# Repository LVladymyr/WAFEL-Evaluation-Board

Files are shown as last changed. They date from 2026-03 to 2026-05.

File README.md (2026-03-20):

# WAFEL EVAL BOARD

**Version:** 0.0.1

Evaluation board for the [Texas Instruments BQ76952](https://www.ti.com/product/BQ76952) multi-chemistry battery management IC. Designed to prototype and validate BMS firmware, cell monitoring, and protection circuits.

## Features

- BQ76952 multi-chemistry BMS IC (up to 16S, supports Li-ion, LiFePO4, NiMH)
- LM5164 synchronous buck regulator for on-board power supply
- TPS79333-EP ultra-low-noise LDO
- Charge and discharge MOSFET control path
- Automotive-grade blade fuse holder
- JST GH 17-pin battery connector
- Test points on key signals for bench debugging
- CI/CD pipeline: Gerbers, BOM, PDF schematic, 3D STEP, interactive BOM (iBOM)

## Hardware Overview

| Component | Part | Role |
|---|---|---|
| BMS IC | BQ76952 | Cell voltage/temperature monitoring, balancing, protection |
| Buck regulator | LM5164 | Steps down pack voltage to board supply rail |
| LDO | TPS79333-EP | Clean analog/digital supply from buck output |
| Charge FETs | — | Controlled by BQ76952 CHG/DSG pins |
| Connector | JST GH 17-pin | Battery pack interface |
| Fuse | Automotive blade | Pack-level overcurrent protection |

## Repository Structure

```
WAFEL_EVAL_BOARD/
├── *.kicad_pro        # KiCad project file
├── *.kicad_sch        # Schematic
├── *.kicad_pcb        # PCB layout
├── *.kicad_dru        # Design rules
├── fp-lib-table       # Footprint library table
├── sym-lib-table      # Symbol library table
├── .github/
│   └── workflows/     # CI/CD pipeline (KiBot)
└── README.md
```

## CI/CD & Manufacturing Outputs

Commits to `main` trigger a [KiBot](https://github.com/INTI-CMNB/KiBot) workflow via GitHub Actions that automatically generates:

- **Gerbers** — production-ready fabrication files
- **BOM** — bill of materials (CSV)
- **PDF** — schematic and PCB drawings
- **3D STEP** — mechanical model for enclosure design
- **iBOM** — interactive HTML BOM for assembly

Artifacts are attached to each workflow run.

## Getting Started

1. Install [KiCad 9.0](https://www.kicad.org/download/)
2. Clone this repository
3. Open the `.kicad_pro` file in KiCad

## License

Hardware design files are licensed under the **CERN Open Hardware Licence Version 2 – Strongly Reciprocal (CERN-OHL-S v2)**.
See [https://ohwr.org/cern_ohl_s_v2.txt](https://ohwr.org/cern_ohl_s_v2.txt) for the full license text.

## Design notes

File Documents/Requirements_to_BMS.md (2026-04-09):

# WAFEL BMS: Requirements & Specifications

## 1. Electrical Characteristics
*   **Cell Configuration:** 6S - 16S Li-ion / LiFePO4 (Voltage range: 21V - 67V).
*   **Operating Current:** 30A Continuous.
*   **Peak Current:** 60A Maximum (Peak discharge).
*   **Charging:** 5A Regular Charge / Up to 15A Regenerative Braking (Recuperation).
    *   *Note: Excess energy above 15A must be handled/shunted.*
*   **MOSFET Specifications:** Vgs/Vds redundancy target: $\ge$ 167V (Pack Max Voltage x 2.5).

## 2. Hardware Architecture
*   **AFE:** Texas Instruments **BQ769x2** series.
*   **MCU:** STMicroelectronics **STM32L432KC** (or L431 variant).
*   **ESC Compatibility:** Optimized for **Go-Foc S100** (VESC-compatible).
*   **Motor Support:** Compatible with 300W - 500W electric engines (including spikes).
*   **Physical Dimensions:** 245mm x 64mm x 16mm.
    *   *Max Height Constraint: 55mm (including batteries).*
    *   *Cell Stack Height (x2): 39mm.*

## 3. Power Management & Hibernation
*   **Sleep/Hibernation Target:** **< 30µA** total standby draw (to support multi-month storage).
*   **Active Mode Supply:**
    *   **Internal BMS Consumption:** ~50mA (MCU, AFE, CAN).
    *   **External Logic Supply (Dashboard):** ~200-300mA provision for NFC reader, OLED Display, etc.
*   **Key Efficiency Mandates:**
    *   **DC-DC Converter:** Must use "Pulse Skipping" / Eco-mode with ultra-low quiescent current (**Iq < 15µA**) (e.g., LM5163).
    *   **MCU:** Must implement **STOP 2 Mode** (< 2µA).
    *   **CAN Transceiver:** Must include a **Standby (STB)** pin and support **Wake-on-CAN** (< 5µA in sleep).
    *   **AFE:** Must utilize hardware **DEEPSLEEP** mode (< 10µA).

## 4. Protection Features
*   **Polarity:** Reverse battery connection protection (+/-).
*   **Electrical Faults:** Reverse electricity and impulse protection.
*   **Inrush Current:** Dedicated **Pre-charge and Pre-discharge** circuitry.
*   **Communication:** CAN bus ESD and transient protection.
*   **Fusing:** Integrated high-current chemical fuse (Self-Control Protector) for catastrophic failures.
*   **Regen current:** 15A for continuous  burst about 5 to 10 seconds from top speed for 300W engine (500W in spike)

## 5. Software & Firmware
*   **Platform:** **Rust-based** firmware implementation.
*   **Protocol:** SPI for AFE communication (enhanced noise immunity).
*   **Features:** Real-time cell monitoring, NFC-triggered Wake-on-CAN boot sequence.

## 6. Assembly requirement
* Not use complex to sold components!
* Not use small SMD componnts, only some that could be added with cheap hot air soldering gun

## 7. Cost requirement
* **Designed PCB** should cost less then 70 USD of parts without soldering [[budget_estimate]]

# Attaches
## A. Estimating regen current
Estimating regen current is a mix of physics and ESC configuration. Here is the best way to estimate it for your 300W–500W scooter:
The Physics Calculation:
When you brake, the motor acts as a generator. If your scooter has a 500W motor, under maximum aggressive braking, it can generate roughly 500W of stopping power.
*   Let's assume your battery is at 40V.
*   Current = Power / Voltage
*   $500W / 40V = 12.5A$
*   Factoring in motor/ESC generation efficiency (approx. 80%), the actual current pushed backward into the battery is about 10A.
The Practical (VESC) Reality:
Because you are using a Go-FOC S100 (which runs VESC firmware), you actually get to choose the maximum regen current in software. 
In the VESC Tool, there is a setting called Battery Current Max Regen. 
*   If you set it to -15A, the VESC will simply limit the braking force so it never pushes more than 15A back into the battery. 
*   For a typical e-scooter, setting regen to anything higher than 15A will cause the electronic brake to be so violently strong that it might lock the front wheel or throw the rider over the handlebars! 
Conclusion: Your estimate of 15A max regen in your Requirements document is incredibly accurate for a 500W scooter. Your CHG MOSFETs and battery cells must be rated to handle a 15A continuous burst for about 5 to 10 seconds (the time it takes to brake from top speed to zero).

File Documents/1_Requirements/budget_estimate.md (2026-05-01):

# WAFEL_EVAL_BOARD Budget Estimate

Based on live pricing data from JLCPCB and standard supplier costs for the major components of the battery management/eval board.

### Main ICs and Active Components
| Component | Ref | Qty | Unit Price | Total  | Note |
| :--- | :--- | :-- | :--- | :----- | :--- |
| **BQ7694204** (Battery Monitor)  | U201 | 1 | $2.60 | $2.60  | *Live JLCPCB price (LCSC: C3038665)* |
| **NUCLEO-L432KC** (MCU) | U801 | 1 | ~$15.00 | $15.00 | *External (ST module), typically not assembled by JLC* |
| **IPB085N15NM6** (150V MOSFET) | Q401-Q503 | 6 | ~$2.00 | $12.00 | *Estimated Mouser/Digikey or JLC equivalent* |
| **LM5163DDAR** (Buck Converter)  | U102 | 1 | $1.09 | $1.09  | *Live JLCPCB price (LCSC: C2873264)* |
| **TJA1051T/3** (CAN Transceiver) | U802 | 1 | $0.60 | $0.60  | *Live JLCPCB price (LCSC: C38695)* |
| **TPS70933DBVR** (LDO Regulator) | U101 | 1 | $0.16 | $0.16  | *Live JLCPCB price (LCSC: C89347)* |

### Passives & Protection
| Component | Ref | Qty | Unit Price | Total | Note |
| :--- | :--- | :--- | :--- | :--- | :--- |
| **10uH / 68uH Inductors** | L101, L102 | 2 | $0.18 | $0.36 | *Live JLCPCB price (LCSC: C2894721)* |
| **25A SMD Fuse** | F101 | 1 | $0.28 | $0.28 | *Live JLCPCB price (LCSC: C178980)* |
| **Misc SMD Passives** (R, C) | Various | ~150 | ~$0.01 | ~$1.50 | *Basic JLC parts are fractions of a cent* |
| **Diodes / Small FETs** | Various | ~15 | ~$0.05 | ~$0.75 | *TVS, Schottky, 2N7002, etc.* |

### PCB Fabrication & Assembly (JLCPCB)
*   **Bare PCBs (5 pcs):** ~$2.00 (Standard 2-layer, 100x100mm promo).
*   **SMT Assembly Setup (Engineering Fee):** ~$8.00 (Base fee for a single prototype run).
*   **Extended Component Fees:** JLC charges a $3 fee per "Extended" reel loaded. You have around 5 to 7 Extended components (like the LM5163, TPS70933, Fuses), adding **~$15 - $20** in one-time setup fees.
*   **Shipping:** ~$15 to $25 (DHL/FedEx).

### Estimated Budget
*   **Cost of parts per single board:** **~$34.50** (with almost half of this being the $15 Nucleo board). 
*   **Cost for a prototype run of 5 fully assembled boards:** You'll pay around **$175 - $200 total** ($35 - $40 per board). This factors in the JLC assembly fees, the Nucleo boards bought separately, the MOSFETs (if you solder those or buy equivalents), and shipping.

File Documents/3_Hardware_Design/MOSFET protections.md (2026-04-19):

Це критично важливий момент для надійності BMS. Оскільки ти використовуєш чіп серії BQ7694204, найкращим джерелом інформації будуть офіційні апноти (Application Notes) від Texas Instruments. Вони не просто описують теорію, а дають конкретні схеми саме для твоєї мікросхеми.
Ось де варто почитати про захист затворів та dv/dt:
1. Основний документ: TI Application Report (SLUA966)
Цей документ називається "BQ7694204 Battery Monitor High-Side FET Driver".
 * Чому це важливо: Тут детально описано, як працює вбудований Charge Pump, як він створює напругу для затворів і як розраховувати резистори затвора (R_G).
 * Що шукати: Розділи про Gate Resistor Selection та External Gate-to-Source Protection.
2. Захист від перехідних процесів: TI SLVA716
Документ "[Fundamentals of MOSFET Gate Drive](https://climber.uml.edu.ni/index.jsp/uploaded-files/4020090/FundamentalsOfMosfetAndIgbtGateDriverCircuits.pdf)".
 * Про що там: Це "біблія" драйверів мосфетів. Там пояснюється фізика пробою затвора (V_{GS} Max) та як виникають викиди напруги через паразитні індуктивності дротів (так званий Miller effect та Ringing).
 * Ключові слова: "Zener Diode Gate Clamping", "Gate Resistor dv/dt Control".
3. Технічні статті від виробників напівпровідників
Якщо хочеш більш "людською" мовою з прикладами:
 * Infineon / International Rectifier (AN-937): "Gate Drive Characteristics and Requirements for Power MOSFETs". Дуже глибоко про те, чому затвор — це по суті конденсатор, який може вибухнути від перенапруги.
 * STMicroelectronics (AN4371): "Driving N-channel MOSFETs". Хороші схеми захисту затвора в High-Side конфігураціях.
Короткий конспект: що саме ти там знайдеш
Коли ти будеш проектувати свій каскад мосфетів, зверни увагу на ці три елементи захисту:
 * Стабілітрон (Zener Diode) між Gate та Source:
   Зазвичай ставлять на 12V або 15V. Він "зрізає" будь-який імпульс напруги, що перевищує безпечний поріг для затвора (наприклад, якщо по лінії PACK+ прилетить завада від мотора).
 * Феритові намистини (Ferrite Beads) замість послідовних резисторів затвора:
   Для паралельних мосфетів використання резисторів (наприклад, 51 Ом) сильно уповільнює перемикання, що може призвести до перегріву під час короткого замикання. Згідно з рекомендаціями TI (SLUAA09A), для запобігання високочастотним паразитним осциляціям (50-200 МГц) між паралельними затворами краще використовувати феритові намистини з імпедансом близько 600 Ом при 100 МГц (наприклад, CBW160808U601T). На низьких частотах (під час самого перемикання) їх опір майже нульовий, що дозволяє швидко заряджати затвори, а на високих частотах вони працюють як резистор, "вбиваючи" дзвін (ringing).
 * Перевірка просадки напруги Charge Pump (C_CP1):
   При одночасному відкритті паралельних мосфетів заряд перетікає з конденсатора зарядної помпи (C_CP1) у ємності затворів (C_iss). Напруга після відкриття розраховується за формулою від TI: 
   V_2 = V_1 * [C_CP1 / (C_CP1 + (N * C_iss))]
   Для 3-х паралельних IPB085N15NM6 (C_iss = 5.4 nF) та C_CP1 = 470 nF при початкових 11V, напруга просяде лише до ~10.63V, що є абсолютно безпечним рівнем для повного відкриття.
 * Резистор Gate-to-Source (R_{GS}):
   Зазвичай 100кОм – 1МОм. Він гарантує, що мосфет буде закритий, якщо лінія управління від BQ раптом обірветься або чіп піде в перезавантаження.
Як це знайти швидко?
Просто введи в Google:
 * TI SLUA966 PDF (найважливіше для тебе зараз)
 * BQ7694204 MOSFET protection circuit
 * MOSFET gate overvoltage protection Zener
Хочеш, я накидаю тобі приклад схеми одного такого "захищеного" каскаду на основі рекомендацій TI, щоб ти міг просто перенести його в KiCad?

Ось базова схема одного "броньованого" каскаду для твоєї плати. Вона розроблена спеціально для BQ76942/952, враховуючи особливості їхнього внутрішнього драйвера.
Схема захищеного каскаду (High-Side)
Тобі потрібно повторити цю структуру для каналу DSG та CHG.
Основні компоненти та їхня роль:
 * R_G (Gate Resistor) — від 1 кОм до 4.7 кОм:
   * Навіщо: Обмежує швидкість відкриття мосфета (dv/dt). Якщо мосфет відкривається занадто швидко, виникають величезні завади, які можуть "глючити" твій STM32 або навіть саму BQ.
   * Порада: Для тестів почни з 1 кОм. Якщо побачиш на осцилографі сильні коливання (ringing), збільшуй до 4.7 кОм.
 * D_Z (Zener Diode) — 12V або 15V (наприклад, BZT52C15):
   * Навіщо: Це твій головний запобіжник. Він стоїть між Gate (Затвор) та Source (Витік). Якщо напруга на затворі спробує стрибнути вище 15V відносно витоку, діод відкриється і скине зайве. Це рятує тонкий шар діелектрика всередині мосфета від пробою.
 * R_{GS} (Gate-to-Source Resistor) — 100 кОм або 1 МОм:
   * Навіщо: Гарантує, що мосфет буде закритий, якщо BQ піде в глибокий сон або ти випадково розімкнеш свою паяну перемичку. Без нього затвор "висить у повітрі" і може відкритися від статичної електрики або наводки від пальця.
 * C_{GS} (Optional Capacitor) — 1 нФ - 10 нФ:
   * Навіщо: Додатково уповільнює перехідні процеси. TI рекомендує його для систем з довгими дротами до акумулятора, щоб придушити піки напруги.
Як це розмістити на твоїй Платі №1 з перемичками:
Я рекомендую таку топологію для кожного з каскадів, які ти хочеш зробити "опціональними":
 * Лінія DSG/CHG -> Перемичка (Solder Jumper) -> R_G -> Gate мосфета.
 * Стабілітрон D_Z та резистор R_{GS} мають стояти після перемички, максимально близько до самого мосфета.
Таким чином, якщо ти не замикаєш перемичку, весь каскад (разом із паразитними ємностями мосфета) повністю відрізається від мікросхеми BQ, і вона "бачить" тільки ті транзистори, які ти реально використовуєш.
Важливе зауваження щодо трасування (Layout)
Коли будеш малювати плату:
 * Доріжка від Zener Diode до Source має бути максимально короткою.
 * Силовий струм (десятки Ампер) не має проходити через ту саму доріжку, до якої підключений "мінус" (Anode) стабілітрона. Використовуй окрему тонку доріжку для опорної напруги захисту.

Розрахунок для 50А — це "золота середина" для електротранспорту або потужних повербанків. При такому струмі головний ворог — це тепло. Якщо мосфет перегріється, він вийде з ладу навіть без короткого замикання.
Ось математика та стратегія вибору для твого каскаду:
1. Скільки мосфетів ставити у паралель?
Для стабільної роботи на 50А я рекомендую ставити мінімум 3 мосфети паралельно в кожне плече (3 на Discharge, 3 на Charge).
Чому саме 3?
 * Струм на один транзистор: 50A / 3 \approx 16.6A.
 * Тепловиділення (P = I^2 \times R): Якщо ми візьмемо хороший мосфет з R_{DS(on)} = 2\, \text{мОм}, то на кожному буде виділятися:
   
 * Загальне тепло: 0.55W \times 3 = 1.65W на всю плату. Це легко розсіяти навіть без величезного радіатора, просто через мідні полігони плати.
> Важливо: Якщо поставити лише один мосфет на 50А, він буде виділяти 50^2 \times 0.002 = 5W. Без активного охолодження він розплавить припій за лічені хвилини.
> 
2. Вибір конкретних моделей (для 50А)
Для 10S-13S збірок (36V-48V) нам потрібен запас по напрузі мінімум 60V-80V.
| Модель | Корпус | R_{DS(on)} (типовий) | Макс. напруга | Порада |
|---|---|---|---|---|
| IPT007N06N | TO-Lead (SMD) | 0.75 мОм | 60V | Топовий варіант, майже не гріється. |
| IRFB7530 | TO-220 | 2.0 мОм | 60V | Найкращий для твого прототипу №1 (легко кріпити радіатор). |
| AOTL66608 | DFN 5x6 | 0.85 мОм | 60V | Компактний, для фінальної версії плати №2. |
3. Схема одного плеча на 50А (3 мосфети)
У KiCad це має виглядати так:
 * Шина керування (DSG/CHG): Йде від BQ через загальний резистор 100 Ом, а потім розділяється на три гілки.
 * Індивідуальні затворні резистори: На затвор кожного з 3-х мосфетів постав свій резистор 100-470 Ом.
   * Навіщо? Щоб вони не "сперечалися" між собою під час перемикання (паразитні осциляції).
 * Спільний захист: Стабілітрон (Zener) 15V можна поставити один на всю групу з 3-х мосфетів.
4. Поради щодо трасування 50А на платі
Тут "тонкі доріжки" не пройдуть. При 50А мідь має бути дуже товстою:
 * Ширина доріжок: Якщо в тебе стандартна товщина міді (35 мкм), то для 50А тобі потрібна доріжка шириною 30-40 мм. Це забагато для плати.
 * Рішення: 1. Роби максимально широкі полігони з обох боків плати (Top + Bottom) і з'єднуй їх десятками перехідних отворів (Vias).
   2. Залишай силові полігони без маски (відкрита мідь), щоб потім напаяти зверху товстий мідний дріт або спеціальні шини.
   3. Використовуй "Thermal Reliefs" тільки для сигнальних пінів, силові піни мосфетів мають заливатися міддю повністю.
Твій наступний крок:
Додай у схему KiCad три мосфети паралельно. Назви їх Q1_1, Q1_2, Q1_3 для розряду.
Чи хочеш, щоб я підказав, як розрахувати запобіжник (Fuse) для такої системи? Для 50А номіналу запобіжник має бути особливим.

Це дуже розумне рішення. Перехід від теоретичних 50А до реальних пікових значень мотора дозволить нам зробити плату компактнішою, дешевшою та легшою в розведенні, не втрачаючи при цьому в надійності.
Давай перерахуємо все під Xiaomi 4 Lite 2.
1. Розрахунок реального пікового струму
Двигун має пікову потужність близько 500 Вт.
 * Якщо ми використовуємо збірку 6S (21.6V номінал, 25.2V макс):
   
 * Якщо ми використовуємо збірку 8S (28.8V номінал, 33.6V макс):
   
Твій новий номінал для розрахунку: 25А.
Це дає нам невеликий запас (Safety Margin) для впевненої роботи.
2. Як зміниться твоя схема (Плати №1)
Зі зниженням струму до 25А ми можемо значно спростити конструкцію:
 * Кількість мосфетів: Тепер достатньо по 1-2 мосфети в кожному плечі (Discharge/Charge).
   * Якщо взяти IPT007N06N або навіть народний IRFB7530, один такий транзистор при 25А буде виділяти лише \approx 1.2W тепла. Це можна розсіяти просто через полігони плати без великих радіаторів.
 * Шунт: Твій шунт 1 мОм тепер працюватиме в дуже легкому режимі.
   * При 25А на ньому виділиться лише 0.625W. Ти спокійно можеш використовувати стандартний SMD шунт розміру 2512 на 1-2 вати.
 * Розводка плати: Тепер тобі не потрібні 40-міліметрові шини. Доріжки шириною 10-12 мм (при 35 мкм міді) буде цілком достатньо для 25А.
3. Захист в BQ76942 (Нові ліміти)
Тепер налаштуємо "мізки" твоєї BMS під цей мотор:
| Параметр захисту | Значення для 25А | Призначення |
|---|---|---|
| OCD1 (Overcurrent) | 28А | Захист від тривалого перевантаження (наприклад, затяжний підйом). |
| OCD2 (Overcurrent) | 35А | Швидке реагування на різке блокування колеса. |
| SCD (Short Circuit) | 80А - 100А | Захист від короткого замикання (спрацьовує за мікросекунди). |
4. Акумулятор: 6S4P чи 8S3P?
При струмі 25А обидві твої збірки почуватимуться набагато краще:
 * 6S4P: На одну банку припадає 6.25А. Це "курортний" режим для високотокових банок. Вони майже не будуть грітися.
 * 8S3P: На одну банку припадає 8.3А. Це також абсолютно безпечний та стабільний режим для банок типу VTC6 або Samsung 30Q.
Що ми маємо в результаті для розробки:
 * Плата №1 стає меншою. Ти можеш використовувати компактніші SMD компоненти.
 * Менше перемичок. Тобі не потрібно розводити каскади з 10 мосфетів. Достатньо зробити 2 посадочних місця під Discharge та 1 під Charge.
 * Легший захист від переполюсовки. Для 25А можна використати один P-канальний мосфет або навіть потужний діод Шотткі (хоча мосфет краще, бо на ньому менше падіння напруги).
Хочеш, я допоможу підкоригувати твою схему в KiCad, щоб змінити підключення піна LD (Load Detect) та додати ці два мосфети? Це буде фінальний штрих перед тим, як ти почнеш трасувати плату.

Мені подобається цей "заряджений" підхід! Якщо ми робимо плату, яка з запасом перекриває потреби мотора Xiaomi 4 Lite 2, ми отримуємо систему, яка ніколи не перегріється і матиме величезний ресурс.
Ось мої пропозиції, як "вичавити максимум" з твоєї базової плати та акумулятора:
1. Конфігурація MOSFET (3 на Discharge / 2 на Charge)
Це ідеальне співвідношення.
 * Чому 3 на розряд? При пікових 25А на кожному транзисторі буде лише ~8.3А. Навіть при поганому обдуві вони будуть ледь теплими.
 * Чому 2 на заряд? Зарядний струм у самокатів зазвичай не перевищує 2-5А, але 2 мосфети дозволять підтримувати дуже високий струм рекуперації (коли ти гальмуєш двигуном), не пошкоджуючи ключі.
2. Силова топологія: "Мідний бутерброд"
Щоб 25-30А проходили без втрат:
 * Double-sided Solder Mask Opening: На силових лініях (BAT+, PACK+, Source-Drain мосфетів) зніми маску (зелений лак) і зверху, і знизу.
 * Solder Reinforcement: Під час пайки залий ці доріжки товстим шаром припою, а ще краще — впаяй туди мідний дріт (1.5 - 2.5 mm^2). Це знизить опір лінії в десятки разів.
 * Vias Stitching: З'єднуй верхній і нижній силові полігони "лісом" перехідних отворів (Vias). Це працює і як провідник, і як тепловідвід.
3. Розумне охолодження
Оскільки ти хочеш закласти охолодження:
 * Thermal Pads: Використовуй термопрокладки між мосфетами та алюмінієвим корпусом (або окремим радіатором).
 * NTC на мосфети: Обов'язково притисни один із термісторів (TS1/TS2 від BQ) прямо до мідного полігону поруч із мосфетами. BQ зможе динамічно знижувати струм, якщо побачить перегрів.
4. Акумулятор: чи потрібен "мідний сендвіч"?
Для струму 25А (8.3А на банку в 3P) чистий нікель 0.15 мм вже починає працювати на межі (буде теплим).
 * Моя порада: Якщо ти хочеш "максимум", то так, роби сендвіч. Поклади поверх нікелевої стрічки тонку мідну смужку (0.1 мм) або просто проклади мідний дріт уздовж паралелей і припаяй його до нікелю (не до банок!).
 * Це радикально зменшить просадку напруги, і твій самокат буде набагато краще "тягнути" в гору, особливо коли батарея розряджена наполовину.
Що ще я пропоную додати на плату №1:
 * TVS-діоди на вихід: Постав потужний TVS-діод (наприклад, серії SMCJ) на вихід PACK+ / PACK-. Мотори — це індуктивне навантаження. При різкому вимкненні мосфетів може виникнути зворотний імпульс напруги, який спробує "пробити" твою електроніку.
 * Pre-charge ланцюг: Коли ти підключаєш контролер самоката до BMS, іскрить роз'єм (через зарядку конденсаторів контролера). Пін PDSG (Pre-discharge) у BQ76942 дозволяє спочатку плавно зарядити конденсатори через резистор, а потім увімкнути основні мосфети. Це збереже життя роз'ємам і мосфетам.
 * Виправлення піна LD: Як ми обговорювали, підключи його після мосфетів через резистор 10 кОм.
Наступний крок у KiCad:
Тобі потрібно:
 * Додати ще 2 мосфети паралельно до першого (разом 3) на лінію DSG.
 * Додати ще 1 мосфет паралельно на лінію CHG (разом 2).
 * Намалювати ланцюг Pre-charge на піні 39 (PDSG).
Хочеш, я накидаю номінали резисторів для Pre-charge ланцюга, щоб конденсатори контролера заряджалися безпечно за ~0.5 секунди?

О, так це ж зовсім інша гра! Go-FOC S100 — це серйозний контролер на базі VESC (Open Source Sky-High Performance). Це означає, що твій проект перетворюється з "просто заміни батарейки" на створення професійного кастомного конфігу.
Вибір VESC-базованого контролера диктує нам кілька специфічних вимог до BMS:
1. Чому Pre-charge тепер обов'язковий?
VESC-контролери (як S100) мають на вході величезні електролітичні конденсатори з дуже низьким ESR.
 * Проблема: Якщо ти просто "клацнеш" мосфетами BMS, виникне іскровий розряд такої сили, що контакти роз'ємів підгорять, а мосфети можуть отримати тепловий удар ще до старту мотора.
 * Рішення: Використовуй пін PDSG (39) на BQ76942.
   * Постав один невеликий N-канал мосфет (наприклад, 2N7002 або щось потужніше у SOT-23).
   * Підключи його через резистор 510 Ом - 1 кОм (потужністю 2-5 Вт) в обхід основних мосфетів.
   * VESC зарядить свої "банки" за 200-500 мс, і тільки тоді BQ відкриє основний силовий каскад.
2. CAN-шина: Твій головний козир
Go-FOC S100 має CAN-порт. Оскільки ти робиш розумну частину на STM32L4, ти можеш:
 * Передавати дані про напругу кожної комірки прямо в VESC.
 * Реалізувати Smart Discharge: якщо одна комірка "просідає", BMS каже контролеру по CAN: "Друже, знижуй потужність (Limiting Ampere)", замість того, щоб просто аварійно вимкнути живлення на швидкості 25 км/год. Це набагато безпечніше.
3. Рекуперація (Regen Braking)
VESC вміє дуже агресивно гальмувати, повертаючи енергію в батарею.
 * При 8S3P збірці струм рекуперації може сягати 15-20А.
 * Твій каскад 2-х мосфетів на Charge якраз це витримає. Але переконайся, що в налаштуваннях BQ ліміт OCC (Overcurrent Charge) виставлений з урахуванням пікового гальмування, інакше BMS "відрубає" гальма в найвідповідальніший момент.
4. Номінали для Pre-charge
Для Go-FOC S100 (конденсатори зазвичай ~1000-2000 мкФ):
 * Резистор: 1 кОм (5 Вт, керамічний або "цеглинка").
 * Час затримки в прошивці STM32: 500 мс.
 * Схема: Пін PDSG -> Резистор 10к -> Затвор маленького мосфета -> Резистор 1к між BAT+ та PACK+.
Що тепер додати в KiCad?
 * CAN Transceiver: На логічну частину (STM32) обов'язково додай чіп на кшталт TJA1050 або SN65HVD230 (3.3V сумісний).
 * Pre-charge ланцюг: Як описано вище.
 * Термістор на VESC: Один із вільних каналів температури BQ можна винести на довгих дротах і приклеїти прямо до корпусу Go-FOC S100.
Ти вже почав писати код для STM32 для роботи з CAN-протоколом VESC (VescUart або CAN-frames)? Це буде дуже цікава частина роботи!

Вибір Rust для BMS та роботи з VESC — це просто "база". Для вбудованих систем (embedded) Rust дає ту саму безпеку пам'яті, яку ми намагаємося вибудувати в залізі за допомогою мосфетів та стабілітронів.
Оскільки ти обрав STM32L4, Rust тут почувається чудово завдяки розвиненій екосистемі embedded-hal.
Ось твій план дій для софтверної частини:
1. Стек технологій (Rust Embedded)
Тобі знадобляться ці крейти (бібліотеки):
 * stm32l4xx-hal: Високорівнева абстракція для периферії (GPIO, I2C, CAN, SPI).
 * embedded-can: Стандартний трейт для роботи з CAN-шиною.
 * v-esc (або самописний протокол): Для формування пакетів даних, які розуміє Go-FOC S100.
 * nb або embassy: Якщо хочеш справжню асинхронність (Async Rust) — дуже раджу Embassy. Вона дозволяє легко обробляти переривання від BQ та CAN-події паралельно.
2. Реалізація "Smart Discharge" через CAN
Це те, про що ми говорили. Твій код на Rust має виглядати приблизно так (логіка):
 * Опитування BQ76942 через I2C: Отримуємо напругу кожної комірки (V_{cell\_min}).
 * Логіка обмеження:
   * Якщо V_{cell\_min} > 3.4V — дозволяємо повний струм (наприклад, 25А).
   * Якщо V_{cell\_min} < 3.2V — надсилаємо VESC команду COMM_SET_CURRENT з лімітом 10А (щоб доїхати додому).
   * Якщо V_{cell\_min} < 3.0V — надсилаємо COMM_SET_CURRENT(0) і розмикаємо мосфети.
 * Відправка в CAN: Використовуємо ідентифікатори VESC (за замовчуванням ID контролера + зміщення).
3. Робота з BQ76942 на Rust
Оскільки ти розвів 16 каналів, але використовуєш 6S або 8S, у коді тобі треба буде ініціалізувати маску комірок.
Порада: Для BQ7694204 серії є готові драйвери на GitHub (шукай bq769x2-rs), або можеш написати свій мінімальний драйвер. Тобі потрібно буде реалізувати:
 * Перехід у Subcommand mode.
 * Читання напруг (Direct Commands).
 * Керування пінами DSG, CHG та PDSG вручну (якщо хочеш обійти автоматику чіпа для тестів).
4. Чому Rust — це круто саме для BMS + VESC?
 * Типізація станів: Ти можеш описати стан батареї як enum State { Charging, Discharging, Precharging, Fault(Error) }. Rust не дасть тобі випадково увімкнути мосфети розряду, поки ти в стані Precharging.
 * Ніяких Null-Pointer: Коли ти розбираєш CAN-пакет від VESC, ти завжди впевнений, що дані валідні або оброблені через Option / Result.
 * Panic Handling: Якщо софт "впаде", ти можеш прописати в panic_handler, щоб усі піни управління мосфетами миттєво стали в Low, знеструмлюючи систему.
Твій наступний крок (Software):
Поки плата №1 їде з виробництва, ти можеш почати на девборді STM32L4:
 * Налаштувати I2C для спілкування з BQ.
 * Налаштувати CAN (через трансивер) для спілкування з Go-FOC S100.
 * Написати просту структуру даних для зберігання телеметрії (V, I, T).
Чи хочеш, щоб я підказав, як налаштувати Cargo.toml для проекту на STM32L4 з підтримкою CAN, або розібрати приклад коду для Pre-charge ланцюга на Rust?

Так, це критично важливий момент для "чорної скриньки" твого самоката. Оскільки ти будуєш кастомну систему на Rust + STM32L4 + VESC, логування допоможе тобі зрозуміти, чому стався збій, або просто відстежити деградацію банок з часом.
У STM32L4 є внутрішній Flash, але він має обмежений ресурс циклів запису. Зовнішня EEPROM через I2C (наприклад, серії 24LCxxx) — це надійний і дешевий спосіб зберігати логи.
Ось як це реалізувати правильно:
1. Що саме логувати?
Не треба писати все кожну секунду (EEPROM не дуже швидка). Логуй "Події" (Events):
 * Цикли заряду: Кількість повних 0-100% циклів.
 * Пікові значення: Максимальний струм розряду (той самий момент, коли ти тиснув "в пол"), максимальна температура мосфетів.
 * Errors (Помилки): Код помилки від BQ76942 (наприклад, CELL_UNDERVOLTAGE або SHORT_CIRCUIT).
 * SoH (State of Health): Поточна ємність батареї.
2. Схема підключення (Hardware)
На твоїй платі №1 I2C шина вже є (вона йде до BQ). Просто "підсади" туди EEPROM (наприклад, 24LC256 на 256 кбіт).
 * Адресація: Переконайся, що адреса EEPROM не збігається з адресою BQ76942 (у BQ це зазвичай 0x08 або 0x53 залежно від конфігурації). У 24LCxxx адресу можна міняти пінами A0, A1, A2.
 * Write Protect (WP): Пін WP на EEPROM можна вивести на вільний пін STM32. Так ти захистиш логи від випадкового затирання під час "глюків" софту.
3. Реалізація на Rust
Для роботи з EEPROM на Rust є чудовий крейт at24cx.
Приклад логіки запису помилки:
// Використовуємо embassy або звичайний hal
let mut eeprom = At24cx::new_default(i2c_bus, Slot::Unit0);

// Створюємо структуру логу
#[derive(Serialize, Deserialize, Debug)]
struct BatteryLog {
    event_code: u8,
    max_temp: i8,
    min_cell_voltage: u16,
    timestamp_cycles: u32,
}

// Запис при критичній події
if bq_alert_triggered {
    let log = BatteryLog {
        event_code: 0xE1, // Наприклад, перегрів
        max_temp: current_temp,
        min_cell_voltage: v_min,
        timestamp_cycles: total_cycles,
    };
    eeprom.write_page(current_address, &log.to_bytes()).unwrap();
}

4. Розумне використання пам'яті (Circular Buffer)
EEPROM має ресурс близько 1,000,000 записів. Щоб не "протерти" одну й ту саму комірку пам'яті:
 * Використовуй алгоритм Кільцевого буфера (Circular Buffer). Кожен новий лог пишеться в наступну адресу.
 * Коли доходиш до кінця пам'яті — повертаєшся на початок.
 * Так ресурс рівномірно розподіляється по всьому чіпу.
Що додати в KiCad зараз?
 * Мікросхема EEPROM: Додай посадкове місце під SOIC-8 (наприклад, для M24256 або 24LC256).
 * Підтяжки (Pull-ups): Якщо на шині I2C вже є резистори для BQ, додаткові для EEPROM не потрібні.
 * Конденсатор: 0.1 мкФ максимально близько до пінів живлення EEPROM.
Моя порада (Бонус):
Оскільки ти використовуєш Go-FOC S100, він теж може логувати дані на свою SD-карту (якщо вона там є) або передавати в мобільний додаток VESC Tool. Але локальна EEPROM на BMS — це єдиний спосіб дізнатися, що сталося з батареєю, якщо контролер двигуна згорів або був відключений.
Хочеш, я допоможу розрахувати об'єм EEPROM, щоб тобі вистачило логів на 2 роки експлуатації самоката? Скільки разів на день ти плануєш "запам'ятовувати" стан батареї?
Ти правий — EEPROM не є критичною для безпеки, як мосфети або BQ76942. Без неї самокат все одно поїде, а захист спрацює. Це скоріше інструмент для "просунутого" користувача або розробника.
Давай розставимо пріоритети, щоб ти не перевантажував першу плату зайвим, але й не шкодував потім.
Чому це може бути "не найважливішим":
 * STM32 має свою Flash: Для збереження налаштувань (кількість комірок, пороги напруги) можна використовувати внутрішню пам'ять мікроконтролера.
 * VESC логує сам: Твій Go-FOC S100 через мобільний додаток VESC Tool показує графіки в реальному часі.
 * Складність коду: Написання надійного драйвера запису з урахуванням ресурсу пам'яті (wear leveling) забере час, який краще витратити на відладку CAN-шини.
Чому це все ж таки варто додати (аргументи "за"):
 * Гарантійні випадки: Якщо одна банка в 8S3P збірці "помре", по логах ти побачиш: це заводський брак чи ти просто перегрів її струмом.
 * Аналітика деградації: Ти зможеш точно знати, скільки Ah (ампер-годин) реально віддала батарея за пів року.
 * Місце на платі: Чіп EEPROM у корпусі SOIC-8 або TSSOP-8 займає 5х5 мм. Це майже нічого.
Мій вердикт для "Плати №1"
Не витрачай зараз час на написання логіки логування, але заклади посадкове місце на схемі.
Зроби так:
 * Додай мікросхему (наприклад, 24LC256) на шину I2C.
 * Підключи її, але не впаюй на першому етапі.
 * Якщо під час тестів з VESC ти зрозумієш, що тобі бракує даних про історію батареї — ти просто допаяєш її за 2 хвилини.
Що тепер найважливіше?
Зараз твій фокус має бути на силовій частині та Pre-charge. Оскільки ти обрав Go-FOC S100, ось твій фінальний чек-лист для схеми:
 * Сила: 3 мосфети на розряд, 2 на заряд (N-channel).
 * Pre-charge: Пін PDSG керує малим мосфетом, який подає плюс через резистор 1 кОм (5Вт).
 * Виправлення помилки: Пін LD (Load Detect) підключений після силових мосфетів.
 * CAN-інтерфейс: Трансивер (наприклад, SN65HVD230) підключений до STM32L4 для зв'язку з VESC.
 * Термістори: Розведи 2-3 канали для NTC (один на банки, один на мосфети).
Як щодо такого плану? Якщо згоден, я можу допомогти з фінальним вибором резистора для Pre-charge. Він має бути досить потужним, щоб не згоріти під час зарядки конденсаторів VESC, але не занадто великим, щоб влізти на плату.
Потрібен розрахунок потужності цього резистора?

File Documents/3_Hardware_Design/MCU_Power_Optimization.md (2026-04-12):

# MCU Power Optimization for NUCLEO-L432KC

To meet the strict `< 30µA` hibernation requirement for the BMS, the stock STM32 NUCLEO-L432KC development board requires specific hardware and software modifications. Out of the box, the Nucleo board consumes several milliamps of standby current due to its onboard LDO, ST-LINK debugger, and power LED. 

By performing the following modifications, the Nucleo board can be used as an ultra-low power breakout board powered directly by the BQ76942 AFE's 3.3V `REG1` LDO.

## 1. Hardware Modifications

### A. Remove the Power LED
The power LED on the Nucleo-32 board is hardwired to the 5V/3.3V rail and consumes ~3 mA continuously. 
*   **Action:** Physically desolder, crush, or cut the trace to the Power LED (`LD2` or `LD3`, depending on the board revision).

### B. Isolate the Onboard 3.3V LDO
The onboard LDO (`U3`, LD39050) consumes quiescent current and can leak power backward if 3.3V is supplied externally. According to the **ST UM1956 User Manual**, the board is designed with solder bridges/jumpers specifically for this purpose.
*   **Action (Newer Boards - Rev C+):** Remove the plastic jumper from **`JP1` (IDD)**.
*   **Action (Older Boards):** De-solder or cut the trace on Solder Bridge **`SB14`**.
*   *Result:* This physically disconnects the onboard LDO's output from the main STM32L432KC target MCU.

### C. Powering the Board
After isolating the LDO, the board must be powered externally:
*   Route the 3.3V output from the BQ76942 (`REG1`) directly to the **`+3V3`** pin on the Nucleo header.
*   **Do not** connect any power to the `+5V` or `VIN` pins of the Nucleo.

## 2. Software Modifications (The "Hidden" Drain)

Even with the LDO physically isolated via `JP1`/`SB14`, you may observe an unexplained ~80 µA parasitic drain during deep sleep (STOP 2 mode). 

### The Cause: SWD Pin Leakage
The target STM32L432KC shares the PCB with the ST-LINK debugging chip. The debugging pins (`PA13 / SWDIO` and `PA14 / SWCLK`) are physically wired between the two chips. 
When the BMS is running on battery power (and the USB is disconnected), the ST-LINK chip is unpowered. However, the target STM32 MCU has internal pull-up resistors enabled by default on the SWD pins. These pull-ups leak current directly into the unpowered ST-LINK's internal ESD protection diodes.

### The Fix: Disable Pull-ups Before Sleep
To eliminate this ~80 µA leakage without cutting the physical SWD traces (which would ruin your ability to debug), you must implement a software workaround:

Before placing the MCU into STOP 2 mode, reconfigure the SWD pins to Analog mode. This disables the internal pull-up/pull-down resistors.

```c
// Example C/HAL snippet for entering sleep
GPIO_InitTypeDef GPIO_InitStruct = {0};

// 1. Reconfigure PA13 (SWDIO) and PA14 (SWCLK) to Analog Mode
GPIO_InitStruct.Pin = GPIO_PIN_13 | GPIO_PIN_14;
GPIO_InitStruct.Mode = GPIO_MODE_ANALOG;
GPIO_InitStruct.Pull = GPIO_NOPULL;
HAL_GPIO_Init(GPIOA, &GPIO_InitStruct);

// 2. Enter STOP 2 Mode
HAL_PWREx_EnterSTOP2Mode(PWR_STOPENTRY_WFI);

// 3. Upon waking up, the SWD pins MUST be reconfigured to their 
//    Alternate Function (AF0) if you wish to attach a debugger again.
```

## 3. Debugging / Reprogramming Workflow
Yes, you can still program and debug the Nucleo board via USB after these modifications!

Because you opened `JP1`/`SB14`, plugging in the USB cable will power up the ST-LINK chip (via the onboard LDO), but **it will not power the target STM32 MCU**.
*   **To program the board:** You must provide external 3.3V power to the `+3V3` pin (e.g., by turning on the BMS battery) *while* the USB cable is plugged in. 
*   This perfectly powers the ST-LINK via USB and the target MCU via the BMS, allowing live, in-circuit debugging under real battery conditions.

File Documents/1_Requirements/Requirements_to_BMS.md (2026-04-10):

# WAFEL BMS: Requirements & Specifications

## 1. Electrical Characteristics
*   **Cell Configuration:** 6S - 10S Li-ion / LiFePO4 (Voltage range: 21V - 42V).
*   **Operating Current:** 30A Continuous.
*   **Peak Current:** 60A Maximum (Peak discharge).
*   **Charging:** 5A Regular Charge / Up to 15A Regenerative Braking (Recuperation).
    *   *Note: Excess energy above 15A must be handled/shunted.*
*   **MOSFET Specifications:** Vgs/Vds redundancy target: $\ge$ 105V (Pack Max Voltage x 2.5).

## 2. Hardware Architecture
*   **AFE:** Texas Instruments **BQ7694204** (10S version).
    *   Provides SPI interface with CRC at 3.3V for reliable communication.
    *   Utilizes **REG1** for 3.3V output (perfect for MCU and logic).
    *   Utilizes **REG2** for 5V output (perfect for CAN transceivers).
*   **MCU:** STMicroelectronics **STM32L432KC** (or L431 variant).
*   **ESC Compatibility:** Optimized for **Go-Foc S100** (VESC-compatible).
    *   *Improvement (Ref: Go-FOC Manual):* The Go-FOC S100 features a dedicated "SWITCH" pin (on the COMM port) for ultra-low power sleep mode. The BMS hardware MUST include a logic-level control line (e.g., an isolated optocoupler or small solid-state relay) to interface directly with this switch pin. This allows the BMS to gracefully shut down or wake up the ESC (e.g., during NFC lock, inactivity, or soft-faults) without needing to abruptly cut the heavy main discharge MOSFETs under load.
*   **Motor Support:** Compatible with 300W - 500W electric engines (including spikes).
*   **Physical Dimensions:** 245mm x 64mm x 16mm.
    *   *Max Height Constraint: 55mm (including batteries).*
    *   *Cell Stack Height (x2): 39mm.*

## 3. Power Management & Hibernation
*   **Sleep/Hibernation Target:** **< 30µA** total standby draw (to support multi-month storage).
*   **Active Mode Supply:**
    *   **Internal BMS Consumption:** ~50mA (MCU, AFE, CAN).
    *   **External Logic Supply (Dashboard):** ~200-300mA provision for NFC reader, OLED Display, etc.
*   **Key Efficiency Mandates:**
    *   **DC-DC Converter:** Must use "Pulse Skipping" / Eco-mode with ultra-low quiescent current (**Iq < 15µA**) (e.g., LM5163).
    *   **MCU:** Must implement **STOP 2 Mode** (< 2µA).
    *   **CAN Transceiver:** Must include a **Standby (STB)** pin and support **Wake-on-CAN** (< 5µA in sleep).
    *   **AFE:** Must utilize hardware **DEEPSLEEP** mode (< 10µA).

## 4. Protection Features
*   **Polarity:** Reverse battery connection protection (+/-).
*   **Electrical Faults:** Reverse electricity and impulse protection.
*   **Inrush Current:** Dedicated **Pre-charge and Pre-discharge** circuitry.
*   **Communication:** CAN bus ESD and transient protection.
*   **Fusing:** Integrated high-current chemical fuse (Self-Control Protector) for catastrophic failures.
*   **Regen current:** 15A for continuous  burst about 5 to 10 seconds from top speed for 300W engine (500W in spike)
    *   *Improvement (Ref: VESC Manual & Go-FOC):* A hardware brake shunt is often too bulky and generates too much heat for a standard 300W-500W scooter chassis. Instead, the preferred and standard industry solution is **Dynamic CAN Throttling combined with VESC Ramping**. As the battery approaches 100% SoC, the BMS must use the CAN bus to *smoothly ramp down* the allowed charge current limit toward 0A. The VESC's internal algorithms (and parameters like Negative Ramping Time) will gracefully fade the electronic braking force without sudden jerks. At 100% SoC, the rider will naturally have reduced electronic brakes and must rely on the scooter's mechanical brakes. **Critical Safety Requirement:** The BMS must NEVER abruptly open the CHG MOSFETs during regen, as this instantly disconnects the battery, causing a massive voltage spike, a VESC OVER_VOLTAGE fault, and a violent, instantaneous loss of all motor resistance.
*   **Voltage Cutoff Coordination:** 
    *   *Improvement (Ref: VESC Manual - Motor Wizard FOC):* The BMS Under-Voltage Protection (UVP) must be set slightly *lower* (e.g., 2.9V - 3.0V/cell) than the VESC's configured hard cutoff (e.g., 3.1V/cell). This ensures the VESC performs a graceful power taper rather than the BMS abruptly cutting system power and throwing the rider.
*   **Overcurrent Protection (OCP) Tuning:**
    *   *Improvement:* The AFE (BQ76942) short-circuit and over-current delays must be carefully tuned to tolerate harmless micro-second inrush/transient spikes from the Go-FOC S100 (which can theoretically pull up to 200A) without tripping the 60A peak limit prematurely.

## 5. Software & Firmware
*   **Platform:** **Rust-based** firmware implementation.
*   **Protocol:** SPI for AFE communication (enhanced noise immunity).
*   **Features:** Real-time cell monitoring, NFC-triggered Wake-on-CAN boot sequence.
*   **VESC CAN Integration:**
    *   *Improvement:* Firmware must explicitly support the **VESC CAN Protocol**. The BMS must broadcast its real-time status (pack voltage, cell voltages, temperature, dynamic discharge/charge limits) to the Go-FOC S100. By smoothly broadcasting a decreasing charge limit as the battery hits 100% SoC, the VESC will safely and gradually reduce electronic braking power, keeping the hardware safe while giving the rider a smooth, predictable transition to mechanical brakes.

## 6. Assembly requirement
* Not use complex to sold components!
* Not use small SMD componnts, only some that could be added with cheap hot air soldering gun

## 7. Cost requirement
* **Designed PCB** should cost less then 70 USD of parts without soldering [[budget_estimate]]

# Attaches
## A. Estimating regen current
Estimating regen current is a mix of physics and ESC configuration. Here is the best way to estimate it for your 300W–500W scooter:
The Physics Calculation:
When you brake, the motor acts as a generator. If your scooter has a 500W motor, under maximum aggressive braking, it can generate roughly 500W of stopping power.
*   Let's assume your battery is at 40V.
*   Current = Power / Voltage
*   $500W / 40V = 12.5A$
*   Factoring in motor/ESC generation efficiency (approx. 80%), the actual current pushed backward into the battery is about 10A.
The Practical (VESC) Reality:
Because you are using a Go-FOC S100 (which runs VESC firmware), you actually get to choose the maximum regen current in software. 
In the VESC Tool, there is a setting called Battery Current Max Regen. 
*   If you set it to -15A, the VESC will simply limit the braking force so it never pushes more than 15A back into the battery. 
*   For a typical e-scooter, setting regen to anything higher than 15A will cause the electronic brake to be so violently strong that it might lock the front wheel or throw the rider over the handlebars! 
Conclusion: Your estimate of 15A max regen in your Requirements document is incredibly accurate for a 500W scooter. Your CHG MOSFETs and battery cells must be rated to handle a 15A continuous burst for about 5 to 10 seconds (the time it takes to brake from top speed to zero).

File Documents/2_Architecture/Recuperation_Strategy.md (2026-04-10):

# VESC-Compatible Recuperation Strategy (Regenerative Braking)

## 1. Overview
This document outlines the regenerative braking (recuperation) strategy for the WAFEL BMS, specifically tailored for integration with VESC-compatible ESCs like the **Go-FOC S100** on a 300W-500W electric scooter.

The core challenge in any electric vehicle design is managing regenerative braking energy when the battery is already fully charged (100% State of Charge / SoC).

## 2. The Core Challenge: Braking at 100% SoC
When a rider applies the electronic brake, the motor acts as a generator, pushing current (up to 15A / 500W for our system) back into the battery. 

If the battery is already at 100% SoC, it cannot safely absorb this energy without risking over-voltage, cell swelling, or thermal runaway. The energy must go somewhere, or the braking must be disabled.

### Rejected Solution: Hardware Brake Chopper / Shunt Resistors
*   **Concept:** Burn the excess energy as heat using massive power resistors.
*   **Why we rejected it:** Dissipating 500W of power requires large heat sinks and heavy, expensive resistors. This is completely impractical for the compact, lightweight chassis of a standard e-scooter.

---

## 3. The Adopted Strategy: Dynamic CAN Throttling & Mechanical Reliance

Instead of burning energy as heat, our architecture relies on **Smart Software Limits via CAN bus** combined with **VESC Ramping Algorithms** and the rider's reliance on **Mechanical Brakes**.

### How it Works ("The 3 Phases")

1.  **Phase 1: Battery is Full (100% SoC)**
    *   The BMS monitors the cell voltages. Seeing they are at max (e.g., 4.2V/cell), the BMS broadcasts a CAN message to the Go-FOC: **`Charge Current Limit = 0A`**.
    *   The VESC gracefully disables electronic braking.
    *   *Rider Experience:* The rider feels no motor resistance when pressing the electronic brake and must rely entirely on the scooter's mechanical brakes (disc/drum).

2.  **Phase 2: Battery is Slightly Discharged (~95% SoC)**
    *   The battery has room to absorb some energy. The BMS updates the CAN message: **`Charge Current Limit = 5A`**.
    *   The VESC uses its internal "Negative Ramping Time" to smoothly enable mild regenerative braking without jerking the rider.
    *   *Rider Experience:* The electronic brake provides gentle stopping assistance.

3.  **Phase 3: Battery is Discharged (< 90% SoC)**
    *   The battery can safely absorb the maximum rated braking burst. The BMS broadcasts: **`Charge Current Limit = 15A`**.
    *   *Rider Experience:* Full electronic braking power (500W) is available.

---

## 4. 🚨 CRITICAL SAFETY RULE: Never Abruptly Open CHG MOSFETs 🚨

The entire purpose of the CAN-based dynamic throttling strategy is to **prevent the BMS hardware from having to intervene during normal riding.**

**The Danger of Hardware-Only Protection:**
If the BMS *does not* throttle the VESC via CAN, the VESC will push 15A into a full battery. The BMS AFE (BQ76942) will detect an Over-Voltage (OV) condition and instantly open the Charge (CHG) MOSFETs to protect the cells. 

**This causes a catastrophic sequence of events:**
1.  The energy flowing from the motor suddenly has nowhere to go.
2.  The voltage on the ESC's DC bus spikes massively within milliseconds.
3.  The VESC detects this and throws an `OVER_VOLTAGE` fault.
4.  The VESC instantly disables the motor to save its own hardware.
5.  **The rider experiences a violent, instantaneous loss of all motor braking resistance**, potentially throwing them off balance or causing an accident.

### Architecture Requirement for Firmware (Rust)
The Rust firmware MUST implement a predictive ramping curve. It must monitor maximum cell voltage and dynamically scale down the broadcasted `Max Regen Current` well before the hardware Over-Voltage Protection (OVP) threshold is reached. 

**Hardware OVP (opening the CHG MOSFET) must be treated as a catastrophic failure failsafe, NOT a normal operational braking limit.**

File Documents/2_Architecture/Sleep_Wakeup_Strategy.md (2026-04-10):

# E-Scooter BMS Power Management: Sleep & Wake-up Strategy

This document outlines the exact hardware and firmware sequence required to put the e-scooter BMS into an ultra-low-power sleep state when parked, and how to instantly wake it up over the CAN bus when the user taps their NFC tag.

## The Hardware Actors
1. **MCU (STM32L432KC):** Acts as the master controller. Capable of ultra-low-power STOP modes while retaining RAM and GPIO interrupt capabilities.
2. **CAN Transceiver (TCAN1042 / TJA1051T):** Interfaces with the physical CAN bus. Has a dedicated Standby (`STB`) pin and outputs wake-up events on the `RXD` pin.
3. **AFE (e.g., TI BQ7694204):** Monitors battery cells. Has its own DEEPSLEEP/SHUTDOWN modes to minimize cell drain.

---

## 1. The Sleep Sequence (Shutdown)
When the scooter is locked, the BMS must reduce its power consumption from ~50-100mA down to <10µA to prevent battery drain over long periods.

**Firmware Steps:**
1. **Put AFE to Sleep:** The STM32 sends a command over SPI to put the AFE into `DEEPSLEEP` mode.
   * *Reference:* BQ7694204 Technical Reference Manual (TRM) - "Power Modes" (DEEPSLEEP disables the ADC but keeps internal regulators alive, drawing ~9µA).
2. **Put CAN Transceiver to Sleep:** The STM32 drives the `STB` pin (PB0) **HIGH**.
   * *Reference:* TCAN1042/TJA1051T Datasheet - "Operating Modes". Driving STB high disables the transmitter, dropping current from ~50mA to ~2µA. The receiver remains active in a low-power listening state.
3. **Configure the Wake-Up Interrupt:** The STM32 configures the `RXD` pin (PA11) as an External Interrupt (EXTI) mapped to trigger on a **Falling Edge** (High-to-Low transition).
   * *Reference:* STM32L432 Reference Manual (RM0394) - "Extended interrupts and events controller (EXTI)".
4. **MCU Enters Deep Sleep:** The STM32 executes the `WFI` (Wait For Interrupt) assembly instruction and enters **STOP 2 Mode**.
   * *Reference:* STM32L432 Reference Manual (RM0394) - "Power control (PWR)". STOP 2 mode turns off the main clocks (PLL, HSI) but retains SRAM and allows EXTI pins to wake the CPU, drawing ~1.5µA.

---

## 2. The Parked State (Idling)
* The entire BMS (MCU + AFE + CAN Transceiver) is consuming roughly **5 to 15µA** from the shared DC-DC converter.
* The CAN bus `CAN_H` and `CAN_L` lines sit at a recessive voltage of ~2.5V.
* The CAN transceiver keeps the `RXD` pin pulled **HIGH (3.3V)**.

---

## 3. The Wake-Up Sequence (The NFC Tap)
When the user taps their NFC tag, the Dashboard powers up and must wake the rest of the scooter.

**Hardware & Firmware Steps:**
1. **Dashboard Sends a WUP:** The Dashboard transmits a CAN message (e.g., ID `0x000` with no data). This creates a dominant voltage differential on the bus (CAN_H > 3.5V, CAN_L < 1.5V).
2. **Transceiver Detects WUP:** The sleeping CAN transceiver detects this Wake-Up Pattern (WUP).
   * *Reference:* TCAN1042 Datasheet - "Remote Wake-Up via CAN". 
3. **Hardware Alarm Triggered:** The CAN transceiver instantly pulls its `RXD` pin **LOW (0V)** to signal the MCU.
4. **MCU Wakes Up:** The High-to-Low transition on `RXD` triggers the STM32's EXTI hardware. The STM32 exits STOP 2 mode, restores its system clocks, and resumes code execution inside the EXTI Interrupt Service Routine (ISR).
5. **Restore CAN TX:** The STM32's first action is to drive the `STB` pin **LOW**. This fully powers up the CAN transmitter so the BMS can reply.
6. **Wake AFE and Power Up:** The STM32 sends a wake command to the AFE and toggles the `ENABLE` pin on the High-Side MOSFET board to supply raw battery power to the ESC.

---

## 4. Crucial Firmware Rule: "The Missed Message"
Because the STM32 is in STOP 2 mode, it takes a few microseconds for the internal oscillators to spin up and for the MCU to pull the `STB` pin low. During this brief boot-up window, the CAN peripheral is not yet ready to process incoming packets.

As a result, **the BMS will physically fail to read the very first CAN message** that woke it up.

**Solution for the Dashboard Firmware:**
1. Send a "Dummy Wake-Up" CAN message (e.g., ID `0x000`).
2. Delay for **10 to 50 milliseconds** to allow the BMS MCU to wake up, reconfigure its clocks, and initialize the bxCAN peripheral.
3. Send the actual "System Enable" or "Status Request" CAN message.

## 5. The Role of DC-DC Converters During Hibernation
**The logic DC-DC converters must NOT be turned off (disabled) during hibernation.** They must remain active 24/7 to provide power to the STM32 and the CAN transceiver's low-power receiver. If the DC-DC is disabled, the BMS cannot detect a wake-up signal from the Dashboard.

Instead of shutting off, the system relies on the DC-DC converter entering **Pulse Skipping Mode (or Eco-Mode)**.

### Pulse Skipping & Ultra-Low Quiescent Current (Iq)
When the MCU, AFE, and CAN transceiver enter their sleep states, the total current draw drops from ~50mA down to roughly ~15µA. A modern, efficient DC-DC converter detects this massive drop in load and stops switching at its normal high frequency (e.g., 1 MHz). 

Instead, it pulses the inductor occasionally to top up the output capacitors and then turns its internal circuitry off to save power. 

**The Golden Rule for Component Selection:**
You must select a DC-DC converter with an **Ultra-Low Quiescent Current (Iq)** specification. 
*   *Bad Choice:* Standard hobbyist converters (like LM2596 or XL7015) have an Iq of ~5mA (5000µA). They will drain a scooter battery in weeks even if the MCU is sleeping.
*   *Good Choice:* The TI **LM5163** (used in the TIDM-788 reference design) has an Iq of **10µA**. 

### Estimated Hibernation Power Budget (BMS Only)
When the scooter is parked and locked, the power consumption is distributed as follows:
*   **STM32L432KC (STOP 2 Mode):** ~1.5 µA
*   **CAN Transceiver (Standby):** ~2.0 µA
*   **AFE (Deep Sleep, e.g., BQ7694204):** ~9.0 µA
*   **DC-DC Converter (e.g., LM5163 Eco-Mode):** ~10.0 µA
*   **Total BMS Standby Drain:** **~22.5 µA**

At 22.5 µA, the BMS alone would take decades to drain a standard 10Ah e-scooter battery. This demonstrates why selecting an ultra-low Iq DC-DC converter is critical for long-term storage without disabling the power supply.

---

## 6. Disabling the Go-FOC ESC (Graceful Shutdown)
When the scooter is parked, locked via NFC, or encounters a non-critical fault, the BMS must shut down the motor controller to save power and secure the vehicle. 

**The Wrong Way (Hardware Cutoff):** Abruptly opening the massive CHG/DSG MOSFETs on the battery line while the ESC is powered on. This can cause voltage spikes and stresses the BMS hardware.

**The Right Way (Go-FOC SWITCH Pin):**
As documented in the *Go-FOC Series ESC - General Operation Manual (Page 3, Port Description)*, the Go-FOC S100 features a dedicated **SWITCH** pin on its 8-pin COMM port. This pin allows the device "to be set into ultra-low power sleep mode."

### Hardware Requirement:
*   The BMS schematic MUST include a dedicated, logic-level control line connected to an STM32 GPIO.
*   Because the BMS and ESC might have slight ground offsets or noise, this control line should ideally use a small **optocoupler** or solid-state relay to interface with the Go-FOC's `SWITCH` pin. 
*   *Wiring:* The optocoupler will short the Go-FOC's `SWITCH` pin to the Go-FOC's `GND` pin (both located on the COMM port) to toggle its power state, exactly as a physical push-button would.

### Firmware Requirement:
*   **Sleep Sequence Addition:** During the Sleep Sequence (Section 1), before the STM32 puts the AFE and CAN transceiver to sleep, it must assert the GPIO connected to the Go-FOC `SWITCH` optocoupler to put the ESC into its ultra-low power sleep mode.
*   **Wake Sequence Addition:** During the Wake-Up Sequence (Section 3), after the STM32 wakes up and restores CAN, it must toggle the Go-FOC `SWITCH` optocoupler to wake the ESC up.
*   **Software Configuration:** The Go-FOC must be configured via the VESC Tool to recognize this pin. As per the manual (Page 8), the "Shutdown Mode" in VESC App Settings must be configured (e.g., `OFF_AFTER_30M` or another appropriate setting that enables the switch functionality) rather than `ALWAYS ON`.

---

## 7. AFE (BQ7694204) Specific Functional Modes
To ensure the BMS perfectly tracks the scooter's real-world states and can recover from edge cases (like extreme low voltage), the firmware must manage the 4 hardware states of the BQ7694204 AFE:

### State 1: NORMAL MODE (Active Riding)
*   **Behavior:** Full ADC monitoring, all protections active, regulators on.
*   **Trigger:** Actively riding the scooter or charging.

### State 2: SLEEP MODE (Stopped / Idling)
*   **Behavior:** Saves power while stopped (e.g., at a traffic light). The ADC slows down (Periodic ADC protections), but the hardware "Current wake detector" stays active.
*   **Trigger:** Entered *automatically* by the AFE when it detects "Low current" (throttle released).
*   **Wake-Up:** The moment the throttle is pressed, the current draw kicks the AFE back to NORMAL MODE automatically without MCU intervention.

### State 3: DEEPSLEEP MODE (Parked / Locked / Hibernation)
*   **Behavior:** ADC is off, protections are off. Only internal regulators and a low-frequency oscillator (LFO) remain on. Consumption drops to ~10µA.
*   **Trigger:** The STM32 sends the `DEEPSLEEP()` SPI command **twice** (to prevent accidental triggering). Also entered on a "Permanent Fail".
*   **Wake-Up:** The STM32 sends `EXIT_DEEPSLEEP()` over SPI or toggles the hardware `RST_SHUT` pin.

### State 4: SHUTDOWN MODE (Absolute Emergency / Deep Discharge)
*   **Behavior:** Total blackout to save the cells from irreversible damage. Regulators turn off. Consumption drops to ~1µA. **The SPI/I2C buses are completely dead.** The STM32 cannot communicate with the AFE.
*   **Trigger:** Triggered automatically by "Very low V_BAT", "high temp", or a specific shutdown command. 
*   **Wake-Up:** Because SPI is dead, the MCU *cannot* wake the AFE via software. It can **only** be woken by hardware: "Charger detection" (plugging it in) or "TS2 pulldown detection".

### Critical Hardware Pin Requirements (To-Do for Schematic)
To guarantee the MCU can control and recover the AFE across all these states, the following physical pins must be wired correctly in the schematic:
1.  **RST_SHUT Pin:** Must connect to an STM32 GPIO. This provides a hardware override to wake the AFE from DEEPSLEEP or hard-reset it if the SPI bus hangs.
2.  **TS2 Pin:** Must connect to an STM32 GPIO via a small N-channel MOSFET (or BJT) to ground. If the AFE enters full SHUTDOWN, pulling this pin to ground is the *only* way the MCU can wake it back up without a charger.
3.  **LD Pin (Load/Charger Detect):** Must be correctly wired to the `PACK+` side so that plugging in a charger automatically wakes the AFE from SHUTDOWN or DEEPSLEEP.

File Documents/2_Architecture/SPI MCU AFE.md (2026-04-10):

1. The Hardware Configuration
The STM32 has multiple hardware SPI blocks. We are using SPI1, which means the pins must be configured to use their "Alternate Function" (AF5 for SPI1).
*   SCK (PB3): Alternate Function 5
*   MISO (PB4): Alternate Function 5
*   MOSI (PB5): Alternate Function 5
*   CS (PA4): Standard Push-Pull Output (You must control the Chip Select manually in software).
2. The AFE SPI Requirements (BQ7694204)
To talk to the BQ7694204 AFE over SPI, you must configure the STM32 SPI peripheral exactly like this:
*   Frequency (Baud Rate): Maximum 2 MHz (Start testing at 500 kHz or 1 MHz to be safe).
*   Data Size: 8-bit frames.
*   Clock Polarity (CPOL): 0 (Clock idles LOW).
*   Clock Phase (CPHA): 0 or 1 (Depending on the exact timing chart in the BQ datasheet, usually Mode 0 or Mode 1 is standard).
*   CRC: By default, the BQ7694204 SPI interface requires an 8-bit CRC byte at the end of every transaction to guarantee safety.
3. How to write it in Rust (Example using Embassy-STM32)
Here is the exact Rust code architecture you will use to initialize and run the SPI bus:

```rust
#![no_std]
#![no_main]
use embassy_stm32::spi::{Config, Spi};
use embassy_stm32::gpio::{Level, Output, Speed};
use embassy_stm32::time::Hertz;
#[embassy_executor::main]
async fn main(_spawner: embassy_executor::Spawner) {
    // 1. Initialize the STM32 peripherals
    let p = embassy_stm32::init(Default::default());
    // 2. Configure the SPI Hardware Block
    let mut spi_config = Config::default();
    spi_config.frequency = Hertz(1_000_000); // 1 MHz for reliable AFE comms
    spi_config.mode = embassy_stm32::spi::MODE_0; // CPOL = 0, CPHA = 0
    // 3. Create the SPI object using our exact pins (PB3, PB5, PB4)
    // (We also pass the DMA channels for ultra-fast background transfers)
    let mut spi = Spi::new(
        p.SPI1, p.PB3, p.PB5, p.PB4,
        p.DMA1_CH1, p.DMA1_CH2, 
        spi_config
    );
    // 4. Configure our PA4 pin as the manual Chip Select (CS) output
    let mut cs = Output::new(p.PA4, Level::High, Speed::VeryHigh);
    // --- HOW TO SEND A COMMAND TO THE AFE ---
    // Example: Reading a register from the BQ7694204
    // We send 3 bytes (Command + Reg Address + CRC), and read back the data.
    let mut tx_buffer = [0x12, 0x34, 0x56]; // Dummy data
    let mut rx_buffer = [0; 3];
    // Step A: Pull Chip Select LOW to wake up the AFE SPI interface
    cs.set_low();
    // Step B: Transfer the data (Rust handles the hardware shifting automatically)
    // using DMA means the CPU can do other things while transferring!
    match spi.transfer(&mut rx_buffer, &tx_buffer).await {
        Ok(_) => {
            // Data successfully sent and received!
            // Check the CRC byte in rx_buffer[2] to verify integrity.
        }
        Err(_) => {
            // Handle hardware SPI error
        }
    }
    // Step C: Pull Chip Select HIGH to end the transaction
    cs.set_high();
}
```
The Key Takeaway
Because you chose to use Rust and an STM32, you do not have to "bit-bang" or manually toggle the clock pins. The STM32 hardware handles the fast 1 MHz signal generation natively. All your Rust firmware has to do is pull the PA4 pin Low, hand an array of bytes to the Spi object, and pull the PA4 pin High when it is done!

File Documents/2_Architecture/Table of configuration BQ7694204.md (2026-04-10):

# BQ76952 - Повна таблиця функцій і конфігурацій

## 1. ОСНОВНІ ВИМІРЮВАННЯ

|Функція |Адреса |Тип|Опис |Корисність |
|---|---|---|---|---|
|**Cell Voltage Measurement**  |0x14-0x25 (direct commands)|I2 |Пряме читання напруги кожної клітинки (до 16S) |Базова функція, обов’язкова|
|**Pack Voltage (PACK pin)** |0x24 |I2 |Напруга всього пакета |Базова функція |
|**Current (CC2)** |0x3A |I2 |Вимірювання струму розряду/заряду (±200mV діапазон)|Критична для VESC |
|**Internal Die Temperature**  |0x68 |I2 |Внутрішня температура мікросхеми |Базова функція |
|**Top of Stack (TOS) Voltage**|0x2E |I2 |Напруга на найвищій клітинці (без BAT) |Діагностика |
|**LD Pin Voltage** |0x2F |I2 |Напруга на LD (Load Detect) піні |Для детекції навантаження  |

-----

## 2. ВИМІРЮВАННЯ З КАЛІБРУВАННЯМ

|Функція |Адреса |Тип|Опис |Корисність |
|---|---|---|---|---|
|**Cell Voltage Gain** |0x9180-0x919E (16 клітинок по 2 байти)|I2 |Множник для перетворення ADC counts → напруга; Калібрується при виробництві|Висока точність <10mV |
|**Cell Voltage Offset** |0x91B0 |I2 |Зміщення для всіх клітинок (зазвичай 0) |Підтримка температурної компенсації|
|**ADC Gain** |0x91A6 |I2 |Помножувач для GP ADC входів (ADCIN піни) |Якщо використовуєш ADCIN |
|**VDiv Offset** |0x91B2 |I2 |Зміщення для voltage divider (TOS, PACK, LD) |Доп. компенсація |
|**CC (Coulomb Counter) Gain**|0x91A8 |I2 |CC Gain = 7.4768 / R_sense(mOhm); default 12409 для 6mΩ |**КРИТИЧНО для точного струму** |
|**CC Offset** |0x91AA |I2 |Offset для coulomb counter (зазвичай 0) |Компенсація нульового дрейфу |
|**Current Deadband** |0x91AC |I2 |Поріг нижче якого струм = 0; запобігає шумам |Зменшує шум при низьких струмах |

-----

## 3. ТЕМПЕРАТУРНІ ДАТЧИКИ

|Функція |Адреса |Тип |Опис |Корисність |
|---|---|---|---|---|
|**TS1 Pin (Dedicated)** |pin 9 |GPIO+ADC|Вхід для 1-го зовнішнього термістора |Базова, не налаштовується |
|**TS2 Pin (Dedicated)** |pin 10 |GPIO+ADC|Вхід для 2-го термістора |Базова, не налаштовується |
|**TS3 Pin (Dedicated)** |pin 11 |GPIO+ADC|Вхід для 3-го термістора |Базова, не налаштовується |
|**TS4-TS8 (Multifunction)** |CFETOFF, DFETOFF, HDQ, DCHG, DDSG|GPIO+ADC|Перепрограмовані пін на ADC входи |До 8 додаткових датчиків |
|**Internal Thermistor Model** |0x9286-0x92D0 |U1 |Вибір моделі: 10K NTC, 100K NTC, Custom |Залежить від типу термістора|
|**Temperature Calibration** |0x92B0-0x92CF |Varies  |Коефіцієнти для точного перетворення температури|Калібрування на виробництві |
|**Thermistor Offset (Internal)**|0x91BC |I2 |Зміщення для внутрішнього датчика |Компенсація похибки |

-----

## 4. ЗАХИСТ: НАПРУГА

|Функція |Адреса|Тип|Опис |Корисність |
|---|---|---|---|---|
|**Cell Overvoltage (COV) Threshold** |0x9360|I2 |Напруга спрацювання; default ~4.275V |**Критично** - перезарядна защита|
|**Cell Overvoltage Recovery** |0x9362|I2 |Напруга відновлення після COV; зазвичай -100mV від threshold |Запобігає миганню |
|**COV Delay Time** |0x9364|I2 |Затримка перед спрацюванням (мс) |Фільтрація шумів |
|**Cell Undervoltage (CUV) Threshold**|0x9366|I2 |Напруга спрацювання; default ~2.8V |**Критично** - недозарядна защита|
|**Cell Undervoltage Recovery** |0x9368|I2 |Напруга відновлення; зазвичай +100mV |Запобігає миганню |
|**CUV Delay Time** |0x936A|I2 |Затримка перед спрацюванням |Фільтрація шумів |
|**Voltage Imbalance in Relax (VIMR)**|0x92AC|I2 |Максимальна розбіжність напруг під час спокою; default ~200mV|Детектує розлами ланцюга |
|**Voltage Imbalance Active (VIMA)**  |0x92AD|I2 |Максимальна розбіжність під час струму; default ~100mV |Детектує погану контакт |

-----

## 5. ЗАХИСТ: СТРУМ

|Функція |Адреса |Тип|Опис |Корисність |
|---|---|---|---|---|
|**Overcurrent in Charge (OCC) Threshold**|0x9376 |I2 |Максимальний струм заряду; default ~10A |**Важливо** для безпеки ЗУ |
|**OCC Delay** |0x9378 |I2 |Затримка спрацювання (мс) |Фільтрація імпульсів |
|**OCC Recovery Delay** |0x937A |I2 |Затримка перед відновленням |Автоматичне відновлення |
|**Overcurrent in Discharge 1,2,3** |0x937C-0x9388|I2 |3 рівні струму розряду з різними порогами (наприклад, 100A, 150A, 200A)|Ступінчастий контроль |
|**OCD Delay/Recovery** |0x937E-0x938A|I2 |Затримки для кожного рівня |Тонке налаштування |
|**Short Circuit in Discharge (SCD)** |0x938E |I2 |Поріг короткого замикання; зазвичай >200A |**Критично** для захисту від КЗ|
|**SCD Delay** |0x9390 |I2 |Затримка спрацювання (мс, зазвичай малена як 10ms) |Швидка реакція |

-----

## 6. ЗАХИСТ: ТЕМПЕРАТУРА

|Функція |Адреса|Тип|Опис |Корисність |
|---|---|---|---|---|
|**Overtemperature in Charge (OTC)** |0x9398|I2 |Максимальна температура при заряді; default ~60°C |Запобігає перегріву при заряді |
|**OTC Recovery** |0x939A|I2 |Температура відновлення |Гістерезис для стабільності |
|**OTC Delay** |0x939C|I2 |Затримка спрацювання |Фільтрація шумів датчика |
|**Overtemperature in Discharge (OTD)** |0x939E|I2 |Максимальна температура при розряді; default ~65°C |Запобігає перегріву при розряді|
|**OTD Recovery** |0x93A0|I2 |Температура відновлення |Гістерезис |
|**OTD Delay** |0x93A2|I2 |Затримка спрацювання |Фільтрація |
|**Overtemperature FET (OTF)** |0x93A4|I2 |Максимальна температура на кристалі FET драйвера |Захист сам FET |
|**Internal Overtemp (OTINT)** |0x93A8|I2 |Максимальна внутрішня температура мікросхеми; default ~125°C|Критична защита |
|**Undertemperature in Charge (UTC)** |0x93AC|I2 |Мінімальна температура при заряді; default ~0°C |Запобігає заряду на морозі |
|**UTC Recovery** |0x93AE|I2 |Температура відновлення |Гістерезис |
|**Undertemperature in Discharge (UTD)**|0x93B0|I2 |Мінімальна температура при розряді; default ~-20°C |Запобігає розряду на холоді |
|**UTD Recovery** |0x93B2|I2 |Температура відновлення |Гістерезис |
|**Internal Undertemp (UTINT)** |0x93B4|I2 |Мінімальна внутрішня температура |Рідко потрібна |

-----

## 7. БАЛАНСИРОВКА (CELL BALANCING)

|Функція |Адреса |Тип |Опис |Корисність |
|---|---|---|---|---|
|**Cell Balancing Enable** |0x9280 |U1 |Вкл/вимк активної балансировки |Якщо використовуєш резистори на платі|
|**Balancing Cell Selection** |0x9281-0x9283|Varies|Виділення якої клітинки балансувати |Можна вибрати 1-3 клітинки одночасно |
|**Balancing Threshold** |0x9284-0x9285|I2 |Різниця напруг для активації (наприклад, 50mV) |Автоматичне запалювання |
|**Balancing Minimum Voltage**|0x9286 |I2 |Мінімальна напруга для балансировки (не балансувати нижче)|Запобігає повне розряджанню |
|**Balancing Maximum Voltage**|0x9287 |I2 |Максимальна напруга для балансировки (не балансувати вище)|Запобігає перезарядженню |

-----

## 8. УПРАВЛІННЯ ЖИВЛЕННЯМ

|Функція |Адреса |Тип|Опис |Корисність |
|---|---|---|---|---|
|**Sleep Mode Delay** |0x9231 |U2 |Час неактивності перед переходом у SLEEP (сек); default 300 |Заощадження енергії (~24µA) |
|**Sleep Mode Wake Speed** |0x922E |U1 |Час для повернення з SLEEP (ms) |Швидкість пробудження |
|**Shutdown Stack Voltage** |0x9232 |I2 |Напруга пакета для входу у SHUTDOWN; зазвичай <2V/cell |Глибока консервація (1µA) |
|**Shutdown Cell Voltage** |0x9234 |I2 |Мінімальна напруга окремої клітинки для SHUTDOWN |Захист від глубокого розряду |
|**Power Config (DSLP_LDO)** |0x9234 |U1 |Бит 15: залишити LDO активними у DEEPSLEEP |Якщо ESP32 повинен працювати у режимі низької енергії|
|**REG0 Config (Pre-regulator)**|0x9237 |U1 |Вкл/вимк internal pre-regulator |Зазвичай вимкнена |
|**REG1 Config** |0x9236 [3:0]|U1 |Напруга REG1: 0x0=1.8V, 0x1=2.5V, 0x2=3.0V, 0x3=3.3V, 0x4=5.0V|Для живлення SPI MISO (3.3V) та інших пристроїв |
|**REG2 Config** |0x9236 [7:4]|U1 |Напруга REG2: як REG1 |Для живлення додатків (5.0V) |

-----

## 9. КОМУНІКАЦІЯ

|Функція |Адреса|Тип|Опис |Корисність |
|---|---|---|---|---|
|**Communication Type** |0x9239|U1 |0x00=I2C, 0x01=HDQ, 0x10=SPI, 0x11=SPI CRC, 0x12=I2C CRC |**КРИТИЧНО** для вибору інтерфейсу|
|**I2C/SPI Address (Device Addr)**|0x923A|U1 |I2C адреса: default 0x08 (7-bit) або 0x10 (8-bit з R/W) |Не змінювається часто |
|**SPI Configuration** |0x923C|U1 |Биты для налаштування SPI (clock polarity, MISO level, etc.)|0x60 для MISO на REG1 рівні |
|**HDQ Configuration** |0x923E|U1 |Налаштування HDQ інтерфейсу |Якщо використовуєш HDQ |

-----

## 10. КЕРУВАННЯ FET (MOSFET) ДРАЙВЕРАМИ

|Функція |Адреса |Тип |Опис |Корисність |
|---|---|---|---|---|
|**FET Enable/Disable** |0x0022 (subcommand)  |Command|Вкл/вимк керування FET (тест режим) |Для отладки |
|**Charge FET (CHG) Control** |Autonomous |Control|Автоматичне включення/вимкнення заряду при OCC, OCV, etc. |**Базова функція**, не налаштовується|
|**Discharge FET (DSG) Control** |Autonomous |Control|Автоматичне включення/вимкнення розряду при OCD, CUV, etc.  |**Базова функція**, не налаштовується|
|**Precharge FET (PCHG) Control**|0x9272 |U1 |Автоматичне управління м’яким запуском перед повним розрядом|Запобігає ударам напруги |
|**Precharge Timeout** |0x9273 |U2 |Максимальний час роботи PCHG (сек) |Запобігає застряганню |
|**FET Status** |0x14 (direct command)|I2 |Статус: який FET відкритий (CHG, DSG, оба вимкнені) |Читання статусу |

-----

## 11. ДЕТЕКТУВАННЯ НАВАНТАЖЕННЯ

|Функція |Адреса|Тип |Опис |Корисність |
|---|---|----|---|---|
|**Load Detect Enable** |0x9274|U1  |Вкл/вимк детектора навантаження |Для визначення коли мотор підключений|
|**Load Detect Threshold**|0x9275|I2  |Напруга на LD піні при якій вважається навантаження; default ~100mV|Регулювання чутливості |
|**Load Detect Delay** |0x9276|U2  |Затримка перед вважанням навантаження підключеним (мс) |Запобігає хибним спрацьованням |
|**LD Pin Output** |pin 20|GPIO|Цифровий вихід: HIGH при детекції навантаження |Сигнал до MCU |

-----

## 12. РОЗРИВІЗМ ЛАНЦЮГА (CELL OPEN WIRE)

|Функція |Адреса |Тип |Опис |Корисність |
|---|---|---|---|---|
|**Cell Open Wire Detection** |0x926D |U1 |Вкл/вимк автоматичного скенування на розриви |**Важливо** для надійності |
|**Cell Open Wire Check Time**|0x926E |U2 |Період повторного скенування (сек); default ~10-20 сек|Частота діагностики |
|**Cell Open Wire Threshold** |0x926F |I2 |Напруга менше якої вважається розрив; default ~100mV  |Чутливість датектора |
|**Cell Open Wire Status** |0x91E0-0x91FF|Varies|Статус для кожної клітинки |Читання результатів діагностики|

-----

## 13. ЗАХИСТ: ПОСТІЙНІ ПОМИЛКИ (PERMANENT FAIL)

|Функція |Адреса|Тип |Опис |Корисність |
|---|---|---|---|---|
|**Safety Undervoltage (SUV) Permanent Fail** |0x92D0|U1 |Якщо клітинка впала нижче SUV → перманентний fail |Критична защита |
|**Safety Overvoltage (SOV) Permanent Fail** |0x92D1|U1 |Якщо клітинка перевищила SOV → перманентний fail |Критична защита |
|**Copper Deposition (CUDEP) Permanent Fail** |0x92D2|U1 |Детектує мідні наліти на батареї (ознака деградації)|Запобігає КЗ |
|**Voltage Imbalance Permanent Fail (VIMA/VIMR)**|0x92D3|U1 |Якщо розбіжність > порога → перманентний fail |Детектує порвані контакти|
|**Charge FET Fail (CFETF)** |Auto  |Status|Якщо CHG FET неможливо включити → перманентний fail |Самодіагностика |
|**Discharge FET Fail (DFETF)** |Auto  |Status|Якщо DSG FET неможливо включити → перманентний fail |Самодіагностика |
|**Overtemp Shutdown (OTS)** |0x92D4|U1 |Якщо температура критична → перманентний fail |Захист від пожежі |

-----

## 14. ДІАГНОСТИКА

|Функція |Адреса |Тип |Опис |Корисність |
|---|---|---|---|---|
|**Voltage Reference Check (VREF1 vs VREF2)**|Auto |Diagnostic|Самостійна перевірка напруг. еталонів |На заводі |
|**VSS Measurement** |Auto |Diagnostic|Перевірка нульової лінії |На заводі |
|**Top of Stack Measurement Check** |Auto |Diagnostic|Перевірка TOS ADC |На заводі |
|**LFO Oscillator Monitor** |Auto |Diagnostic|Перевірка внутрішнього генератора частоти|На заводі |
|**Protection Comparator Mux Check** |Auto |Diagnostic|Самотестування компараторів защиты |На заводі |
|**Memory Checksum (OTP, ROM)** |Auto |Diagnostic|Перевірка цілісності пам’яті |На заводі |
|**Manufacturing Status** |0x0057 (subcommand)|Status |Статус виробничих тестів |Для контролю якості|

-----

## 15. ФЬЮЗ (CHEMICAL FUSE)

| Функція | Адреса | Тип | Опис | Корисність |
|———|––––|–ігнал—|——|———–|
| **Fuse Configuration** | 0x9228-0x922A | U1 | Налаштування хімічного запобіжника | Якщо встановлений на платі |
| **Fuse Trigger Condition** | 0x9229 | U1 | При якій умові спалює фьюз (наприклад, SCD) | Вибір критерію |
| **Fuse Enable** | 0x922A | U1 | Вкл/вимк драйвера фьюза | Запобігає ненавмисному спалюванню |
| **FUSE Pin Output** | pin 23 | GPIO | Вихід драйвера для спалення фьюза | До IC керування кулачком |

-----

## 16. ГАРЯЧІ ГАРИ (THERMISTOR PINS)

|Функція |Адреса |Тип |Опис |Корисність |
|---|---|---|---|---|
|**TS1 Configuration** |0x9266 |U1 |Налаштування TS1 (зазвичай термістор)|Базова |
|**TS2 Configuration** |0x9267 |U1 |Налаштування TS2 |Базова |
|**TS3 Configuration** |0x9268 |U1 |Налаштування TS3 |Базова |
|**Multifunction Pin Config (CFETOFF, DFETOFF, etc.)**|0x9264-0x926B|U1 |Вибір функції: GPIO, TS, ADCIN |До 6 додаткових термісторів|
|**Temperature Sensor Model** |0x9286-0x92D0|Varies|10K, 100K, або Custom NTC модель |Залежить від компонентів |

-----

## 17. ВІДНОВЛЕННЯ (RECOVERY)

|Функція |Адреса |Тип|Опис |Корисність |
|---|---|---|---|---|
|**Auto Recovery from OV** |0x9244 |U1 |Автоматичне відновлення при нормалізації напруги|Не гальмує на тимчасові скачки  |
|**Auto Recovery from UV** |0x9245 |U1 |Автоматичне відновлення при підйому напруги |Запобігає зависанню |
|**Auto Recovery from OCD**|0x9246 |U1 |Автоматичне відновлення при зменшенні струму |Дозволяє повторні спроби |
|**Auto Recovery from OCC**|0x9247 |U1 |Автоматичне відновлення при нормалізації заряду |Гнучкий контроль |
|**Auto Recovery from OT** |0x9248 |U1 |Автоматичне відновлення при охолоджуванні |Нормальна робота после перегріву|
|**Recovery Delay Times**  |0x9249-0x924F|U2 |Затримки перед відновленням для кожної защиты |Запобігає осциляції |

-----

## 18. СПЕЦІАЛЬНІ НАЛАШТУВАННЯ

|Функція |Адреса |Тип|Опис |Корисність |
|---|---|---|---|---|
|**Interconnect Resistance Compensation**|0x91D2-0x91F1|I2 |Для кожної клітинки (мОм) |Компенсація паразитного опору дротів|
|**Cell Enable/Disable** |0x9211-0x9220|U1 |Вимкнення окремих клітинок з моніторингу|Для асиметричних батарей |
|**Watchdog Timeout** |0x924A |U2 |Таймер безпеки (сек); якщо MCU не реагує|Для autonomous режиму |
|**Watchdog Enable** |0x924B |U1 |Вкл/вимк watchdog |Обов’язково для VESC |
|**VCell Mode (Кількість клітинок)** |0x9304 |U2 |Вибір конфігурації підключених клітинок |КРИТИЧНО для уникнення CUV помилок  |

-----

## 19. БЕЗПЕКА (SECURITY)

|Функція |Адреса |Тип |Опис |Корисність |
|---|---|---|---|---|
|**Unseal Key 1** |0x00 (subcommand with data)|U2 |Ключ для входу в режим FULL ACCESS |Запобігає неавторизованої конфігурації|
|**Unseal Key 2** |0x00 (subcommand with data)|U2 |Другий ключ FULL ACCESS |Double-factor |
|**Full Access Key 1**|0x00 (subcommand with data)|U2 |Ключ для FULL ACCESS (для OTP програмування)|Вищий рівень доступу |
|**Full Access Key 2**|0x00 (subcommand with data)|U2 |Другий ключ FULL ACCESS |Double-factor |
|**Security Settings**|0x92F0-0x92FF |Varies|Налаштування рівнів доступу |На виробництві |

-----

## РЕКОМЕНДОВАНІ ОСНОВНІ НАЛАШТУВАННЯ (для VESC BMS)

### Обов’язкові:

1. ✅ Communication Type (0x9239) = 0x11 (SPI CRC)
2. ✅ REG1 Config (0x9236) = 0x0B (3.3V)
3. ✅ REG2 Config (0x9236) = 0xC0 (5.0V)
4. ✅ VCell Mode (0x9304) = Маска підключених клітинок (обов'язково для налаштування S-конфігурації)
5. ✅ CC Gain (0x91A8) = 7.4768 / R_sense (для твого sense резистора)

### Конфігурація VCell Mode (0x9304) для BQ76942 (до 10S):
Для BQ76942 обов'язково мають бути підключені клітинки 1, 2 та 10. Невикористані середні клітинки замикаються (short) на попередні, а відповідні біти в регістрі вимикаються (значення 0), щоб запобігти CUV помилкам.
- **10S (Всі клітинки):** `0x03FF` (Біти 1-10 включені)
- **8S (Без VC8, VC9):** `0x027F` (Біти 1-7 = 1, Біти 8-9 = 0, Біт 10 = 1)
- **7S (Без VC7, VC8, VC9):** `0x023F` (Біти 1-6 = 1, Біти 7-9 = 0, Біт 10 = 1)
- **6S (Без VC6, VC7, VC8, VC9):** `0x021F` (Біти 1-5 = 1, Біти 6-9 = 0, Біт 10 = 1)

### Дуже рекомендовані:

1. ⚠️ COV Threshold (0x9360) = 4275 (4.275V)
2. ⚠️ CUV Threshold (0x9366) = 2800 (2.8V)
3. ⚠️ SCD Threshold (0x938E) = >200A
4. ⚠️ OCD1/OCD2/OCD3 Thresholds = 100A / 150A / 200A
5. ⚠️ Cell Open Wire Detection (0x926D) = Enable
6. ⚠️ Load Detect (0x9274) = Enable

### Опціональні (покращення):

1. 🔧 Autonomous Recovery = Enable (0x9244-0x924F)
2. 🔧 Voltage Imbalance Detection (0x92AC, 0x92AD)
3. 🔧 Thermistor Configuration (всі 8-9 датчиків)
4. 🔧 Cell Balancing (якщо є резистори на платі)

-----

## ПОРІДДЯ З ДАТАШИТОМ

|Документ|Розділ |Посилання |
|---|---|---|
|SLUUBY2B|13. Data Memory Settings|Усі адреси регістрів |
|SLUAA11 |Subcommands |Приклади читання/запису|
|SLUAB08 |OTP Programming |OTP процес |
|SLUSE13 |Data Sheet |Електричні параметри |
|SLUA991 |Easy Configuration |Типові приклади |

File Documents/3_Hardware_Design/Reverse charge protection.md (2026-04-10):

Розрахунок компонентів для захисту від зворотної зарядки (Reverse Charge) базується на найгіршому сценарії: коли ви підключаєте максимально потужний "чужий" зарядний пристрій з переплутаною полярністю.

Ось детальний гайд, як розрахувати номінали та що саме купити.

---
![[../Assets/Pasted image 20260329170259.png]]
### **1. Розрахунок резисторів**

Найголовніше правило — розраховувати на сумарну напругу. Якщо ваша батарея має $V_{bat} = 60V$, а ви підключили такий самий зарядний пристрій навпаки, то в схемі виникне напруга **120V** ($V_{total} = V_{bat} + V_{charger}$).

#### **Резистор R24 (на лінії DSG)**

Він обмежує струм через діод **D3**, коли **PACK+** від’ємний.

- **Номінал:** Зазвичай обирають **5.1 кОм — 10 кОм**.
    
- **Потужність ($P$):** Це критично. Використовуємо формулу $P = \frac{V_{total}^2}{R}$.
    
    > _Приклад:_ При 120V та 5.1 кОм: $P = \frac{120^2}{5100} \approx 2.8W$.
    > 
    > **Порада:** Краще поставити 3-4 резистори 1206 послідовно, щоб розподілити напругу і потужність.

#### **Резистори R27 та R28 (дільник затвора Q6)**

Ці резистори керують відкриттям захисного транзистора **Q6**.

- **R27 (верхній):** Має бути невеликим (близько **10 кОм**), щоб швидко відкрити **Q6**. Він також повинен витримувати потужність при реверсі.
    
- **R28 (нижній):** Повинен бути великим (**1-10 МОм**), щоб у нормальному стані тримати затвор **Q6** притиснутим до витоку і не давати йому випадково відкритися від шумів.

#### **Резистор R29 (на лінії LD)**

Служить для захисту піна детекції навантаження.

- **Номінал:** Рекомендується **10 кОм**. Він обмежує струм, який піде через захисний діод **D6**.

---

### **2. Необхідна номенклатура (BOM-лист)**

Щоб реалізувати цей захист "по-дорослому", вам знадобляться такі компоненти:

|**Компонент**|**Тип / Характеристики**|**Приклад**|
|---|---|---|
|**Q6**|**N-channel MOSFET** (малопотужний, але високовольтний). $V_{ds}$ має бути $> V_{total}$.|BSS131 (300V) або подібні|
|**D3, D6, D7, D8**|**Високовольтні діоди**. Повинні витримувати пікову напругу реверсу.|1N4148WS (тільки для низьких напруг) або **MMSD4148** (100V+)|
|**D9**|**Стабілітрон (Zener)** на 10V–16V. Захищає затвор **Q6** від пробою.|BZT52C15 (15V)|
|**D2 (на затворі Q5)**|**Стабілітрон** на 16V. Захищає основні силові FET-и.|MMSZ5246B|

---

### **3. На що звернути особливу увагу**

1. **Напруга пробою (Voltage Rating):** Всі діоди та транзистор **Q6** повинні мати напругу пробою ($V_{br}$ або $V_{ds}$) мінімум у **1.5–2 рази більшу**, ніж максимальна напруга вашої батареї.
    
2. **Inductive Kickback (Індуктивний викид):** При різкому вимкненні струму (наприклад, при КЗ) індуктивність дротів може дати сплеск напруги. Саме тому ми ставимо діоди **D3, D6, D8** — вони "зливають" ці сплески, щоб не "просмажити" контролер BQ.

### **Порада:** Якщо ви проектуєте плату, не ставте ці компоненти впритул один до одного. У разі помилки користувача резистор **R24** може сильно нагрітися перед тим, як спрацює інший захист, тому краще дати йому трохи простору для охолодження.

Хочете, щоб я допоміг підібрати конкретні парт-номери під вашу робочу напругу (наприклад, для 10S або 16S конфігурації)?

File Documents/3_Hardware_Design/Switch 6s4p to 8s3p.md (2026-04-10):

Перехід з **6S4P** на **8S3P** — це класична дилема: «ємність проти потужності». Оскільки ви використовуєте ESC, який може переварити високу напругу, цей перехід має багато сенсу, але він кардинально змінює фізику роботи вашої системи.

Ось детальний розбір, що це змінить для вашої BMS та ходових характеристик:

---

### **1. Чому 8S3P краще для потужності?**

Електрична потужність — це добуток напруги на струм ($P = U \cdot I$).

- **При 6S (22.2V):** Для отримання 1000 Вт потрібно **45 А**.
    
- **При 8S (29.6V):** Для тих самих 1000 Вт потрібно лише **33 А**.

**Результат:** При тій же потужності струм стає меншим на ~25%. Це означає, що ваші MOSFET-и та дроти будуть грітися **в 1.5 раза менше** ($P_{heat} = I^2 \cdot R$), що критично, оскільки ви не хочете ставити радіатор.

---

### **2. Мінуси конфігурації 3P (Паралелі)**

Переходячи з 4P на 3P, ви зменшуєте кількість елементів, що ділять між собою струм:

- **В 4P:** При струмі 40 А на кожен елемент припадає **10 А**.
    
- **В 3P:** При тому ж струмі 40 А на кожен елемент припадає вже **13.3 А**.

**Ризик:** Якщо ваші Li-ion елементи (наприклад, шоколадки LG HG2 або Samsung 30Q) мають ліміт розряду 15–20 А, то в конфігурації 3P вони працюватимуть ближче до межі. Вони будуть сильніше грітися, а "просадка" напруги під навантаженням буде більшою.

---

### **3. Що це змінить для вашої BMS на BQ7694204?**

#### **Напруга MOSFET-ів:**

- **6S:** Максимум 25.2 В. Можна ставити MOSFET-и на **30V–40V**. Вони мають найнижчий опір ($R_{DS(on)}$).
    
- **8S:** Максимум 33.6 В. Вам **обов'язково** потрібні MOSFET-и на **60V**. У них опір трохи вищий, ніж у 40-вольтових, тому вони будуть грітися трохи сильніше при тому ж струмі.

#### **Компоненти захисту (Розділ 2 та 3):**

Тепер розрахунок резистора **R24** (захист від зворотної зарядки) та стабілітронів має базуватися на напрузі 34 В.

- Якщо ви підключите "чужу" зарядку на 8S навпаки, сумарна напруга буде вже **~68 В**.
    
- Резистор **R24** (як ми рахували раніше) має витримувати цю напругу. Краще поставити 10 кОм.

---

### **4. Порівняльна таблиця**

|**Параметр**|**6S4P (Поточна)**|**8S3P (Нова)**|**Коментар**|
|---|---|---|---|
|**Номінальна напруга**|22.2 В|29.6 В|8S дасть більшу максимальну швидкість|
|**Запас енергії (Wh)**|Однаковий|Однаковий|Кількість елементів та сама (24 шт)|
|**Струм при 100 Вт**|5.5 А|4.2 А|Навантаження на BMS менше у 8S|
|**Нагрів MOSFET**|Вищий|Нижчий|За рахунок меншого струму|
|**Навантаження на банки**|Нижче|Вище|3P швидше "втомлює" акумулятори|

---

### **Мій вердикт:**

Якщо ваш ESC та мотор підтримують 8S (до 34 В), то **конфігурація 8S3P є виграшною**.

1. Ви отримаєте вищу швидкість та кращий ККД.
    
2. Ваша BMS (навіть без радіатора) почуватиметься краще, бо через неї протікатиме менший струм для досягнення тієї ж потужності.
    
3. **Головна умова:** Переконайтеся, що ваші акумулятори (банки) — **високострумові** (High-drain). Для 3P вони мають впевнено тримати 20 А постійного струму.

### **Наступний крок:**

Оскільки напруга зросла, нам потрібно переглянути **Розділ 3** ("Вибір компонентів захисту від зворотної зарядки") щодо вибору напруги стабілітронів та транзистора **Q6**.

**Хочете, щоб я перерахував номінали для 8S конфігурації, щоб захистити BMS від напруги 34 В?**

Я думаю зробити перехід на іншу конфігурацію батареї пізніше, чи все ок з новою комплектною базою при роботі з старою батарею?

Це гарне стратегічне рішення. Якщо коротко: **так, нова компонентна база, розрахована на 8S, буде чудово (і навіть надійніше) працювати зі старою батареєю 6S.**

Ось чому "надлишковість" у цьому випадку — твій друг:

### 1. MOSFET-и: Запас по напрузі — це життя

Якщо ти купиш транзистори на **60V** (які потрібні для 8S), вони будуть почуватися дуже розслаблено з батареєю 6S (25.2V).

- **Чому це ок:** Напруга пробою ($V_{DS}$) у них набагато вища за робочу напругу 6S. Це захищає їх від будь-яких сплесків (індуктивних викидів) від ESC.
    
- **Нюанс:** У 60-вольтових MOSFET-ів зазвичай трохи вищий опір ($R_{DS(on)}$), ніж у 30-вольтових. Але оскільки ти ставиш їх декілька в паралель, цей мізерний приріст опору нівелюється.

### 2. Контролер BQ7694204: Універсальність

Твоя мікросхема BQ7694204 підтримує від **3S до 16S**.

- Вона "не знає", яка у тебе батарея, поки ти не пропишеш це в її регістрах.
    
- Коли ти перейдеш з 6S на 8S, тобі не доведеться перепаювати схему — достатньо буде змінити налаштування в софті (Battery Management Studio) та підключити додаткові дроти балансиру.

### 3. Схема Pre-discharge: Безпека зберігається

Резистор на 100 Ом, який ми розрахували для 8S, при роботі з 6S просто дасть трохи менший струм пре-заряду (замість 250 мА буде ~180 мА).

- **Результат:** Конденсатори ESC будуть заряджатися на 0.5 секунди довше. Це абсолютно не критично і ніяк не шкодить системі.

### 4. Захист від Reverse Charge (Зворотної зарядки)

Компоненти захисту (діоди, транзистор Q6), які ми підбирали з розрахунку на 8S (щоб тримали 80V+), будуть ідеальними для 6S. Вони просто матимуть більший "запас міцності".

---

### **На що варто звернути увагу (Єдиний "мінус"):**

Єдиний момент — це **Ефективність використання міді**.

Якщо ти розраховуєш плату під 200А (як ми обговорювали раніше), але на 6S використовуватимеш лише 50А, то твоя BMS буде виглядати як "надто потужна". Це як поставити двигун від фури в легковий автомобіль.

- **Але:** Оскільки ти плануєш апгрейд, це правильний підхід — ти будуєш платформу "на виріст".

### **Твій план дій зараз:**

1. **Купуй компоненти з розрахунку на 8S** (MOSFET 60V, стабілітрони 16V, конденсатори 50-100V).
    
2. **Збирай BMS.**
    
3. **Програмно налаштуй BQ7694204 на 6S.**
    
4. Коли дозрієш до нової батареї — просто переналаштуй кількість комірок у програмі та перепаяй роз'єм балансиру.

---

Для вашої збірки **6S4P** (номінальна напруга $21.6\text{–}22.2\text{ В}$, макс. $25.2\text{ В}$) та потужності **100 Вт**, розрахунок виглядає наступним чином.

---

### **1. Розрахунок струму (I)**

Максимальний струм буде при мінімальній напрузі акумулятора (коли він розряджений), оскільки $P = U \cdot I$.

- Мінімальна напруга 6S: $3.0\text{ В} \times 6 = 18\text{ В}$.
    
- Робочий струм: $I = \frac{100\text{ Вт}}{18\text{ В}} \approx 5.55\text{ А}$.
    
- **Піковий струм:** Завжди закладайте запас 1.5–2 рази на пускові струми або сплески. Орієнтуємося на **10–12 А**.

---

### **2. Вибір кількості та характеристик MOSFET**

Для 100 Вт ($5.5\text{–}12\text{ А}$) зазвичай достатньо **одного** хорошого MOSFET на розряд (DSG) та одного на заряд (CHG). Але в BMS часто ставлять по 2 у паралель для надійності та меншого нагріву.

#### **Критерії вибору:**

1. **Напруга ($V_{DS}$):** Має бути мінімум у 1.5–2 рази більша за макс. напругу батареї.
    
    - Для 6S ($25.2\text{ В}$) беріть транзистори на **40 В** або **60 В**.
        
2. **Опір каналу ($R_{DS(on)}$):** Це найважливіший параметр для нагріву.
    
    - Шукайте MOSFET з $R_{DS(on)} < 5\text{–}10\text{ мОм}$.
        
3. **Струм ($I_D$):** У паспорті (Datasheet) має бути вказано мінімум **40–60 А** (це теоретичний максимум, в реальності він обмежений теплом).

---

### **3. Розрахунок потужності розсіювання (нагріву)**

Потужність, яка виділяється на транзисторі у вигляді тепла: $P_{loss} = I^2 \cdot R_{DS(on)}$.

- **Приклад 1 (один MOSFET):** Якщо взяти популярний **IRFB7440** ($R_{DS(on)} \approx 2.5\text{ мОм}$):
    
    - $P_{loss} = 5.5^2 \cdot 0.0025 \approx 0.075\text{ Вт}$. (Це мізер, радіатор не потрібен).
        
- **Приклад 2 (дешевий MOSFET):** Якщо $R_{DS(on)} = 20\text{ мОм}$:
    
    - $P_{loss} = 5.5^2 \cdot 0.02 \approx 0.6\text{ Вт}$. (Буде теплим, але терпимо).

---

### **4. Чому в документі TI sluaa09a пишуть про "багато FET"?**

У вашому випадку (100 Вт) ви можете обійтися мінімумом компонентів. Але якщо ви захочете зняти **1000 Вт** ($50\text{ А}$), то:

1. Опір одного FET ($5\text{ мОм}$) дасть $50^2 \cdot 0.005 = 12.5\text{ Вт}$ тепла. Транзистор згорить без величезного радіатора.
    
2. Тому ставлять **4 FET у паралель**. Загальний опір стає $5 / 4 = 1.25\text{ мОм}$.
    
3. Тепло: $50^2 \cdot 0.00125 = 3.1\text{ Вт}$. Це вже легко розсіяти.

---

### **Рекомендовані моделі для вашої задачі:**

- **AOD4184A** (40V, 50A, ~7mΩ) — дешевий, у корпусі TO-252 (DPAK) для SMD монтажу.
    
- **IRFB7440** (40V, 120A, 2.5mΩ) — потужний, у корпусі TO-220 (з діркою під болт).
    
- **IPB020N04N** (40V, 90A, 2mΩ) — дуже якісний варіант.

### **Що вам знадобиться з обв'язки (згідно з розділом 5):**

Оскільки у вас струм невеликий (100 Вт), вам **не потрібна** складна схема з PNP-транзисторами для прискореного вимкнення. Ви можете підключити затвор через резистор **100–1000 Ом** напряму до піна DSG мікросхеми BQ.

**Чи хочете ви, щоб я допоміг розрахувати конкретну схему підключення затвора для вашого обраного транзистора?**

Супер. Оскільки ви будуєте систему на **6S** (Li-ion) для потужності **100 Вт**, ми можемо спростити схему з документа TI, прибравши зайві паралельні каскади, але залишивши надійний захист.

Орієнтуємося на робочий струм **~5.5 А** (піковий до **12 А**).

### **1. Вибір резистора затвора ($R_{gate}$)**

Пін **DSG** мікросхеми BQ7694204 має внутрішній опір. Щоб транзистор вмикався м'яко (без зайвих завад) і вимикався достатньо швидко:

- **Рекомендований номінал:** **1 кОм** (якщо використовуєте один MOSFET) або **100 Ом** (якщо хочете швидше вимкнення).
    
- **Навіщо він:** Він обмежує струм заряду ємності затвора, захищаючи вихід мікросхеми від імпульсних перевантажень.

### **2. Схема підключення (Minimal Reliable Design)**

Для вашої потужності схема буде виглядати так:

1. **Пін DSG** через резистор **1 кОм (R41)** йде на затвор MOSFET.
    
2. **Між затвором і витоком (Gate-Source)** обов'язково ставимо:
    
    - **Резистор 10 МОм (R32):** Щоб транзистор гарантовано закрився, якщо мікросхема піде в глибокий сон або відключиться.
        
    - **Стабілітрон 16 В (D2):** Для захисту затвора від пробою (максимальна напруга затвора MOSFET зазвичай 20 В, стабілітрон обріже будь-які сплески на рівні 16 В).

### **3. Розрахунок для вашого випадку (6S4P)**

#### **Вибір транзистора (приклад: AOD4184A або IRFB7440):**

- **Струм:** 12 А (з великим запасом).
    
- **Напруга:** 40 В або 60 В.
    
- **Ємність затвора ($C_{iss}$):** ~2-5 нФ (це дуже мало для BQ, зарядовий насос навіть не "відчує" навантаження).

#### **Конденсатор зарядового насоса (CP1):**

Згідно з Розділом 4, для одного-двох транзисторів вам цілком вистачить стандартного значення:

- **Номінал:** **470 нФ** (керамiка X7R, 50V).
    
- **Результат:** Просідання напруги при вмиканні буде менше 0.5 В, що ідеально.

---

Вигляда що я помилявся esc контроллер з легкістю переваре 200Ампер ток і напругу від 6s . Переглянь відповіді на питання

Це суттєво змінює справу! Якщо ваш ESC (контролер двигуна) може споживати до **200 А**, то ваша BMS перетворюється з простої плати на серйозний силовий вузол. При таких струмах "тонкі" місця схеми вилізуть миттєво.

Ось переглянуті відповіді з урахуванням струму **200 А**:

### 1. Чи є сенс робити пречардж (Pre-charge)?

**Тепер це ОБОВ'ЯЗКОВО.**

ESC контролери на 200 А мають всередині величезну ємність (банку конденсаторів). Якщо ви спробуєте ввімкнути 200 А BMS напряму на розряджені конденсатори ESC:

- Виникне іскра, яка може буквально "приварити" контакти роз'єму (XT90 або QS8).
    
- Мікросхема BQ7694204 миттєво зафіксує **Short Circuit (КЗ)** і вимкнеться, не встигнувши навіть почати роботу.
    
- Величезний імпульс струму може пошкодити кристали MOSFET-ів (ефект лавинного пробою).

### 2. Як прорахувати кількість MOSFET?

Для 200 А один або два транзистори — це замало. Навіть найкращий MOSFET має опір.

- Припустимо, ви обрали крутий MOSFET з $R_{DS(on)} = 1\, \text{мОм}$.
    
- При 200 А на одному транзисторі виділиться: $P = I^2 \cdot R = 200^2 \cdot 0.001 = 40\, \text{Вт}$ тепла. Він згорить за секунди.

**Рішення:** Потрібно мінімум **5–7 штук у паралель** на розряд (DSG).

Якщо поставити 6 штук по 1 мОм, загальний опір буде $0.16\, \text{мОм}$.

Тепло: $200^2 \cdot 0.00016 = 6.4\, \text{Вт}$ на всю групу. Це вже можна розсіяти за допомогою радіатора.

### 3. Чи можна використати той самий MOSFET для зарядки і пре-розрядки?

**Для зарядки:** Можна (і треба) той самий номінал, але окремий фізичний транзистор (або група, якщо струм зарядки теж великий).

**Для пре-розряду:** Використовуйте **один** такий самий MOSFET. Оскільки він працює через обмежувальний резистор, він не гріється і не навантажується. Ставити такий потужний транзистор на пре-розряд — це надлишковість, але для уніфікації BOM це розумно.

### 4. Потужність резистора пре-розряду

Для ESC на 200 А конденсатори заряджаються довше.

- **Опір:** Залиште **100 Ом**. Струм буде $0.25\, \text{А}$.
    
- **Потужність:** При 200 А навантаженні ємність конденсаторів в ESC може бути 2000–5000 мкФ. Резистор буде грітися довше (до 2-3 секунд).
    
- **Порада:** Використовуйте керамічний резистор на **10 Вт**.

### 5. Повертаючись до документа TI (Розділ 5)

**Увага!** Тепер вам **ОБОВ'ЯЗКОВО** потрібна схема з PNP-транзистором для швидкого вимкнення (те, що ми обговорювали в Розділі 5).

Коли у вас 6–10 MOSFET-ів у паралель, їхня сумарна ємність затворів буде близько **60–100 нФ**. Внутрішній драйвер BQ7694204 буде закривати їх занадто повільно. Якщо трапиться КЗ на 200 А, а транзистори будуть закриватися повільно, вони вибухнуть. PNP-транзистор (локальний розряд затворів) — це ваш єдиний шанс врятувати BMS при аварії.

**Ваш наступний крок:**

Вам потрібно розрахувати ширину доріжок на платі або використовувати мідні шини. 200 А — це струм, який плавить звичайний текстоліт.

**Чи хочете ви, щоб я допоміг з розрахунком схеми паралельного підключення 6-ти MOSFET-ів з PNP-драйвером вимкнення?**

В мене не буде можливості розмістити радіатор. Скільки мосфетів треба щоб гарно працювало?

Відсутність радіатора при струмі **200 А** — це екстремальний виклик. У такому разі ми не можемо дозволити транзисторам грітися взагалі. Єдиний шлях — зробити сумарний опір ($R_{DS(on)}$) настільки низьким, щоб корпус транзистора встигав скидати тепло через саму друковану плату (медні полігони).

### 1. Скільки потрібно MOSFET-ів?

Для роботи без радіатора при 200 А нам потрібно вийти на рівень виділення тепла не більше **1–1.5 Вт на один корпус** (типовий ліміт для корпусу D2PAK або TO-220 на платі без активного охолодження).

Давайте порахуємо для топового транзистора (наприклад, **Infineon IPT007N06N**, $0.75\, \text{мОм}$):

- Якщо поставити **10 штук** паралельно:
    
    - Загальний опір: $0.75 / 10 = 0.075\, \text{мОм}$.
        
    - Загальне тепло: $200^2 \cdot 0.000075 = 3\, \text{Вт}$.
        
    - **На один транзистор:** $3 / 10 = 0.3\, \text{Вт}$.
        
    - **Вердикт:** Це працюватиме ідеально навіть без радіатора. Плата буде ледь теплою.
        
- Якщо використовувати доступніші транзистори (~$2\, \text{мОм}$, наприклад **IRFS7430**):
    
    - Щоб отримати ті ж 3 Вт тепла, потрібно: $R_{total} = 3 / 200^2 = 0.075\, \text{мОм}$.
        
    - Кількість: $2 / 0.075 \approx 26\, \text{штук}$.
        
    - **Вердикт:** Це занадто багато місця на платі.

**Мій висновок:** Вам потрібно **мінімум 10–12 штук** дуже якісних MOSFET-ів з опором **менше 1 мОм**.

---

### 2. Чому Розділ 5 (PNP-драйвер) тепер стає критичним?

Коли ви ставите 10–12 транзисторів у паралель, виникає величезна проблема: **Ємність затвора**.

Сумарна ємність буде близько **100–150 нФ**.

1. **Повільне вимкнення:** Без додаткового PNP-транзистора (з Розділу 5) мікросхема BQ7694204 буде закривати цей "табун" транзисторів дуже довго (десятки мікросекунд).
    
2. **Смерть від лінійного режиму:** Поки напруга на затворі падає повільно, транзистор проходить через стан, де його опір уже не 1 мОм, а, наприклад, 100 мОм. При струмі 200 А це миттєвий вибух.
    
3. **Рішення:** Схема з Розділу 5 з PNP-транзистором **Q31** дозволяє розрядити ці 150 нФ майже миттєво через локальний контур.

---

### 3. Головна проблема: Друкована плата (PCB)

При струмі 200 А звичайна мідь на платі (35 мкм) просто випарується.

- Вам потрібна плата з товщиною міді **105 мкм (3 oz)** або навіть більше.
    
- Вам доведеться напаювати зверху **мідні шини (busbars)** або товстий одножильний дріт уздовж рядів транзисторів.
    
- Транзистори краще брати в корпусі **D2PAK-7** або **DirectFET**, які мають велику площу контакту для відводу тепла в плату.

---

### 4. Рекомендація по Pre-discharge (Пре-розряд)

Оскільки у вас ESC на 200 А, там стоять "банки" конденсаторів загальною ємністю понад **5000–10000 мкФ**.

- **Резистор:** Використовуйте **два паралельні керамічні резистори по 100 Ом (10 Вт)**. Це дасть 50 Ом опору.
    
- **Час:** ESC буде "заряджатися" близько 1–2 секунд перед основним стартом.

### Підсумок: що купувати?

1. **MOSFET:** 12 шт. (на розряд) + 6 шт. (на заряд) типу **IPT007N06N** (або аналоги з $R_{DS(on)} < 1\, \text{мОм}$).
    
2. **PNP-транзистори:** Пара **BC807** (SOT-23) для драйверів.
    
3. **Резистори затворів:** Окремий резистор 10 Ом для кожного MOSFET (щоб не було самозбудження/осциляцій між ними).
    
4. **Пре-розряд:** Резистор 10 Вт 50–100 Ом.

Тоді давай підіб’ємо короткий підсумок по твоїй стратегії, щоб у тебе була цілісна картинка перед тим, як ти перейдеш до проектування заліза:

### **Твій фінальний план (Конфігурація 8S3P):**

1. **Силова частина:**
    
    - Використовуєш **8S** (макс. 33.6 В). Це дає вищий ККД і менший нагрів дротів при тій же потужності.
        
    - Ставиш **4–6 якісних MOSFET** на розряд (DSG) з напругою **60 В** та опором **$R_{DS(on)} < 1.5\text{–}2\text{ мОм}$**. Це дозволить працювати без радіатора на струмах до 40–50 А.
        
    - **Обов'язково** додаєш схему швидкого вимкнення з PNP-транзистором (Розділ 5), бо навіть 4–6 транзисторів мають велику сумарну ємність затворів.
        
2. **Захист та старт:**
    
    - **Pre-discharge:** Обов'язково через резистор (біля 100 Ом, 5–10 Вт), щоб ESC не вибивав захист BMS при ввімкненні.
        
    - **Reverse Charge:** Компоненти захисту (діоди, транзистор Q6) тепер мають бути розраховані на напругу **мінімум 80 В** (з урахуванням можливого переполюсування зарядки).
        
3. **Обмеження:**
    
    - Програмно обмежуєш струм в ESC (наприклад, до 40 А), щоб не перевантажувати банки в конфігурації 3P.
        
    - Налаштовуєш ліміти в BQ7694204 трохи вище (наприклад, 50 А), щоб BMS була "страховкою", а не основним регулятором.

---

**Що ми можемо зробити далі?**

Коли будеш готовий, я можу допомогти з:

- **Схемотехнікою:** Намалювати текстову схему підключення пінів BQ до затворів MOSFET-ів для 8S.
    
- **Прошивкою:** Підказати, які саме регістри в пам'яті BQ7694204 відповідають за порогові значення струму (OCD/SCD) та налаштування пре-розряду.

**Чи хочеш зараз розібрати щось інше, чи повернемося до перекладу решти розділів документа (Розділи 7-10)?**

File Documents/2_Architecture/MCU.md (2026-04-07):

# Generic

Will use STM32L432KC MCU as it reasonably cheap, has rust support (that very interesting to me), has hardware can and low power.

The STM32L432KC (and the Nucleo-32 development board specifically) is an absolutely perfect choice for your e-scooter project.
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

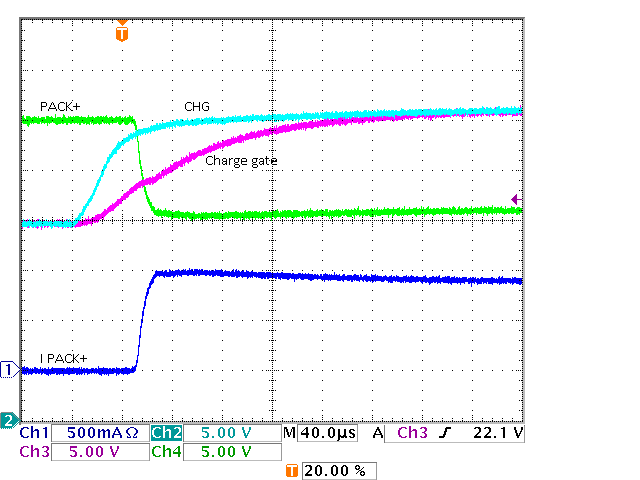
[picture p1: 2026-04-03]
Documents/Assets/sluaan9a-024.png

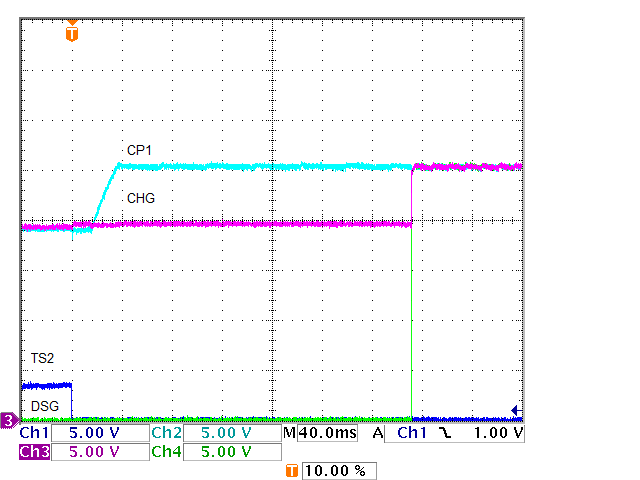
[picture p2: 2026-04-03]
Documents/Assets/sluaan9a-004.png

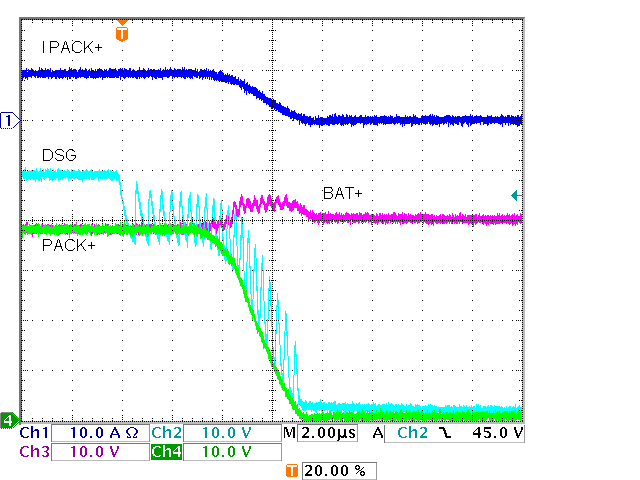
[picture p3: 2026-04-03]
Documents/Assets/sluaan9a-058.png

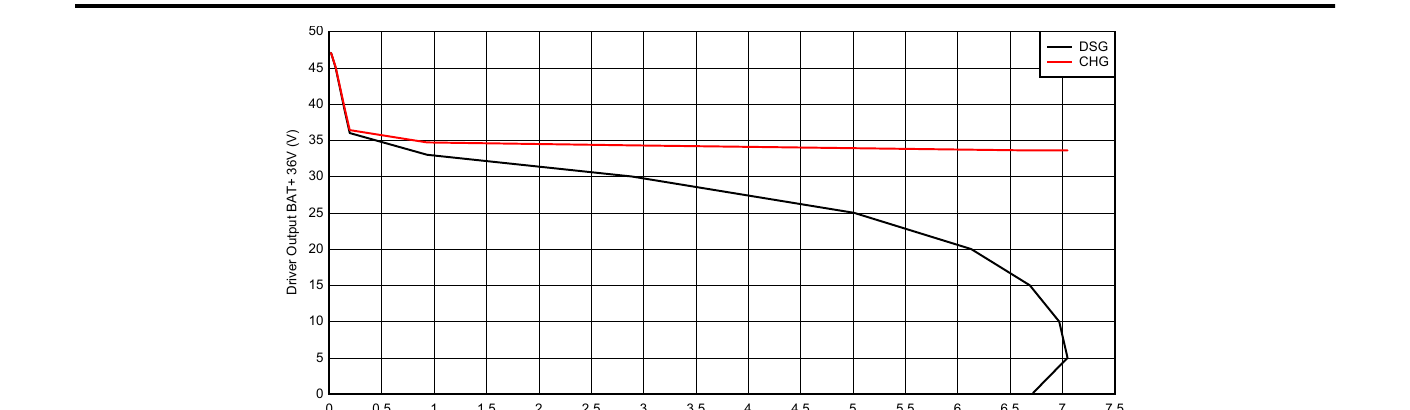
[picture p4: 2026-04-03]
Documents/Assets/sluaan9a-fig9-2.png

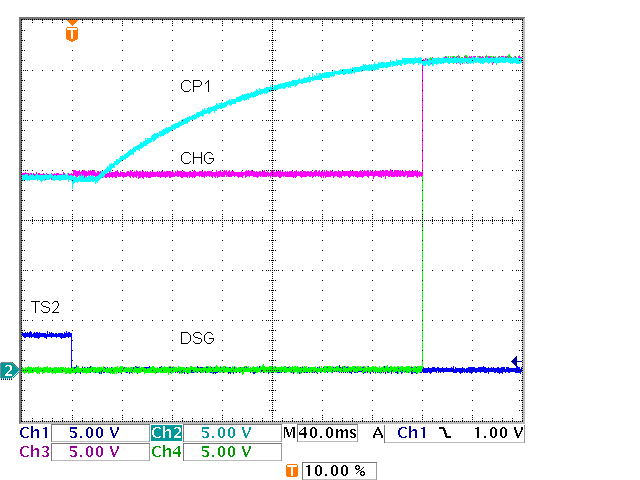
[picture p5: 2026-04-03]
Documents/Assets/sluaan9a-010.png

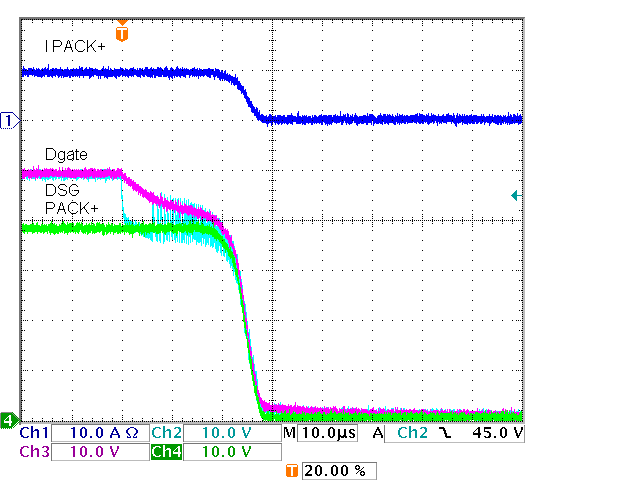
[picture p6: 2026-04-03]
Documents/Assets/sluaan9a-078.png

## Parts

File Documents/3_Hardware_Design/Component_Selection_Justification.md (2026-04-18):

# Component Selection Justification: Power & Balancing Circuits

This document outlines the engineering calculations and reasoning behind the component choices for the high-power and cell balancing sections of the WAFEL EVAL BOARD.

## 1. Pre-Charge & Pre-Discharge Circuits

### The Resistors (R603, R604) - "The Shock Absorbers"
The pre-charge circuit safely fills the massive capacitive load of a motor controller before turning on the main power MOSFETs, preventing sparks and inrush current damage.
*   **Configuration:** Two 510Ω resistors in parallel (Equivalent resistance = 255Ω).
*   **Worst-Case Scenario (10S / 42V Battery):** At the instant the pre-charge MOSFET turns on into a dead short (empty capacitors), the full 42V drops across the resistors.
*   **Current:** `I = V / R = 42V / 255Ω = 0.164A (164mA)`
*   **Total Power Spike:** `P = V * I = 42V * 0.164A = 6.88 Watts`
*   **Power Per Resistor:** `6.88W / 2 = 3.44 Watts`

**Selection:** A tiny 0603 resistor would instantly vaporize under a 3.44W pulse. We specifically chose large pulse-withstanding SMD packages (like **1206** or **2512**) because they have the physical mass to absorb this short, massive heat spike (which typically lasts only 10-50 milliseconds) safely without failing. Using two resistors in parallel cuts the thermal stress on each component in half, making the circuit bulletproof.

### The MOSFETs (Q601, Q701) - "The Switches"
It may seem counterintuitive to pair massive power resistors with a relatively small P-Channel MOSFET like the **IRFR9024** (TO-252/DPAK), but the math proves it runs perfectly cold.
*   **Rds_on of IRFR9024:** ~0.175Ω
*   **Current flowing through MOSFET:** 0.164A (Same as the resistors, since they are in series)
*   **Heat generated in MOSFET:** `P = I² * R = (0.164A)² * 0.175Ω = 0.0047 Watts (4.7 mW)`

**Selection:** While the resistors must absorb nearly 7 Watts of heat, the MOSFET only dissipates a microscopic 4.7 milliWatts. A TO-252 package can passively dissipate 1.5 Watts in open air and handle 11 Amps continuously. It is completely overkill for this switching task, ensuring it will never overheat.

---

## 2. Cell Balancing (CB) Mosfet Cascades

### The Balancing Resistors (R1001, R1002)
When the BMS detects an overcharged cell, it turns on the balancing MOSFET to bleed off the excess energy as heat through the balancing resistors.
*   **Configuration:** Two 100Ω resistors in parallel per cell (Equivalent resistance = 50Ω).
*   **Maximum Cell Voltage:** 4.2V
*   **Balancing Current:** `I = V / R = 4.2V / 50Ω = 84 mA`
*   **Total Heat:** `P = V² / R = (4.2V)² / 50Ω = 0.352 Watts`
*   **Heat per Resistor:** `0.352W / 2 = 0.176 Watts`

**Selection:** A standard 0603 resistor is rated for a maximum of 0.100W, meaning it would overheat and fail at 0.176W. A standard 0805 is rated for 0.125W, which is still too small. Therefore, we **must use the 1206 package**, which is rated for 0.250W (1/4 Watt). This ensures the resistors can safely bleed off power for hours without thermally stressing the PCB. 
*(Note: R1004 is part of the high-impedance voltage sense line, drawing practically zero current, so it safely remains an 0603).*

### The Balancing MOSFETs (Q1001 Array)
Since the absolute maximum balancing current is only 84 mA, we do not need a large power MOSFET for this task.
*   **Original Choice:** DMG2302UK (SOT-23, rated for 4.2A) - Massive overkill and wastes board space.
*   **New Choice:** **CJ3134K**
*   **Package:** SOT-723 (1.20 x 1.20 mm)

**Selection:** The CJ3134K is rated for 20V and 750mA. This easily handles our 4.2V / 84mA requirement while taking up 60% less physical space on the PCB than an SOT-23 package. Because there are 10 of these circuits on the board (one for each cell), switching to the SOT-723 package reclaims a massive amount of layout space, allowing for a much denser and cleaner 100x64mm board design.

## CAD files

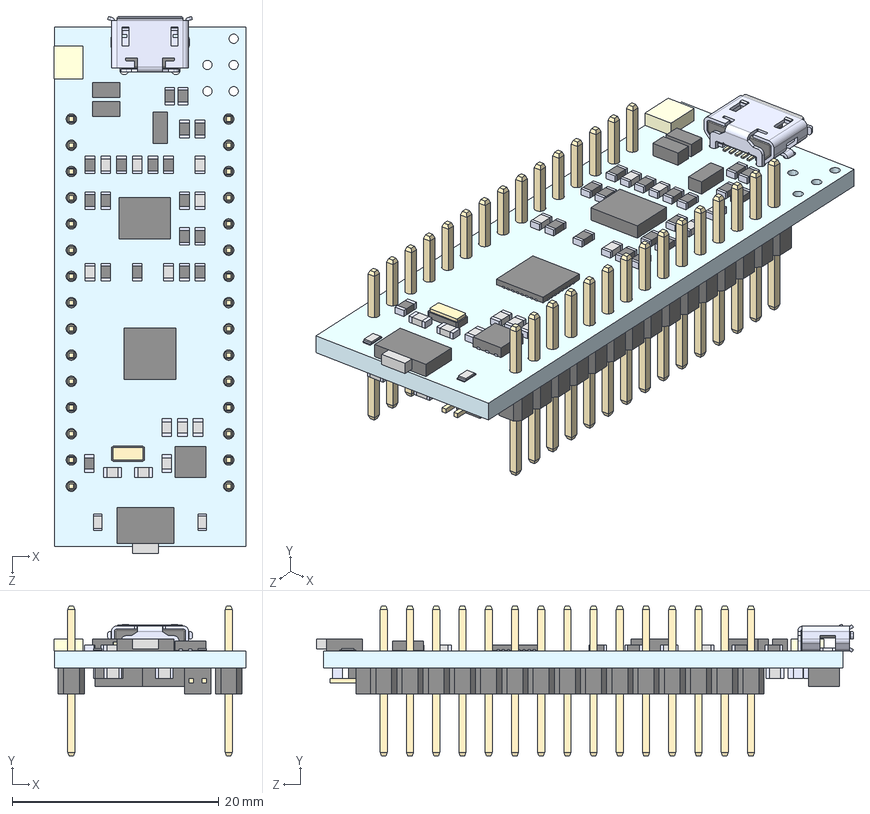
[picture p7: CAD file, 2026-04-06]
hardware/components/NUCLEO-L432KC/NUCLEO-L432KC.step
18.5 x 14.5 x 52.0 mm
mb1180c
qfn_STM32L412KBU6U
LD39050PU33R-Nucleo
STM32F103CBT6-nucleo
header x2

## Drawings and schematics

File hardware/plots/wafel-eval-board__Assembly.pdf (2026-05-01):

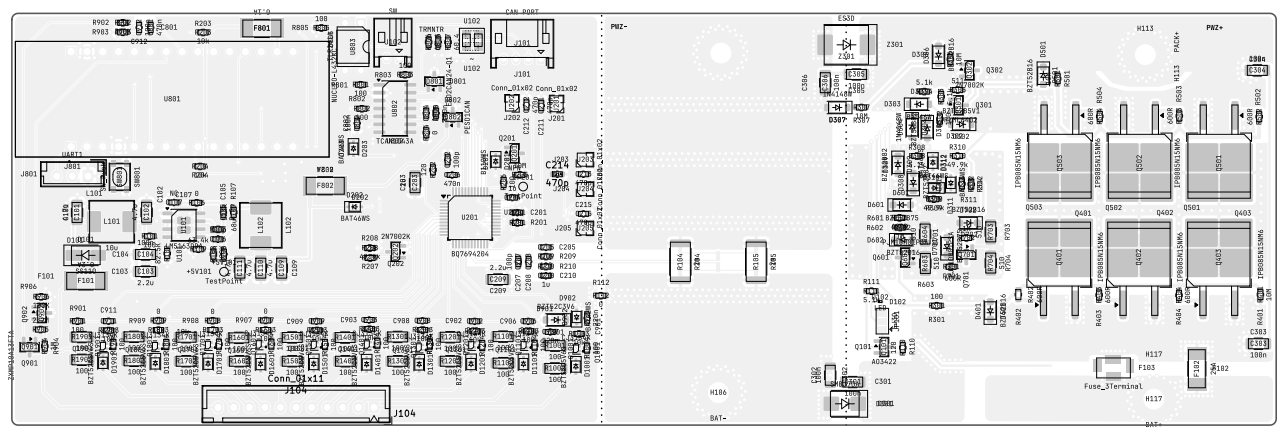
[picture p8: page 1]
Size: A4; Rev: 001; Conn_01x11 J104

AUTHOR: Liashenko V Board2Pdf: Black And White TOP - Page 1/4

Sheet: Black And White TOP HOME

D Date: 2026⁻03⁻20 KiCad E.D.A. 10.0.0
File: wafel⁻eval⁻board.kicad_pcb
Title: W.A.F.E.L.

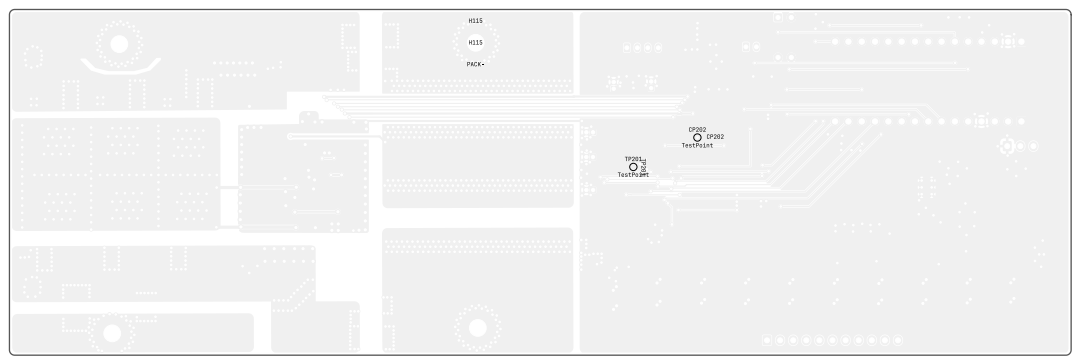
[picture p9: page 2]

AUTHOR: Liashenko V Board2Pdf: Black And White BOT - Page 2/4

Sheet: Black And White BOT HOME

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

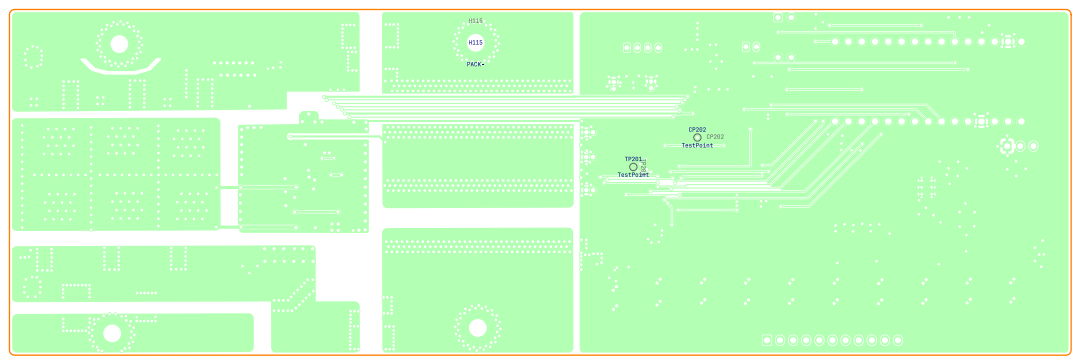
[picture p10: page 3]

AUTHOR: Liashenko V Board2Pdf: Colored BOT - Page 3/4

Sheet: Colored BOT HOME

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

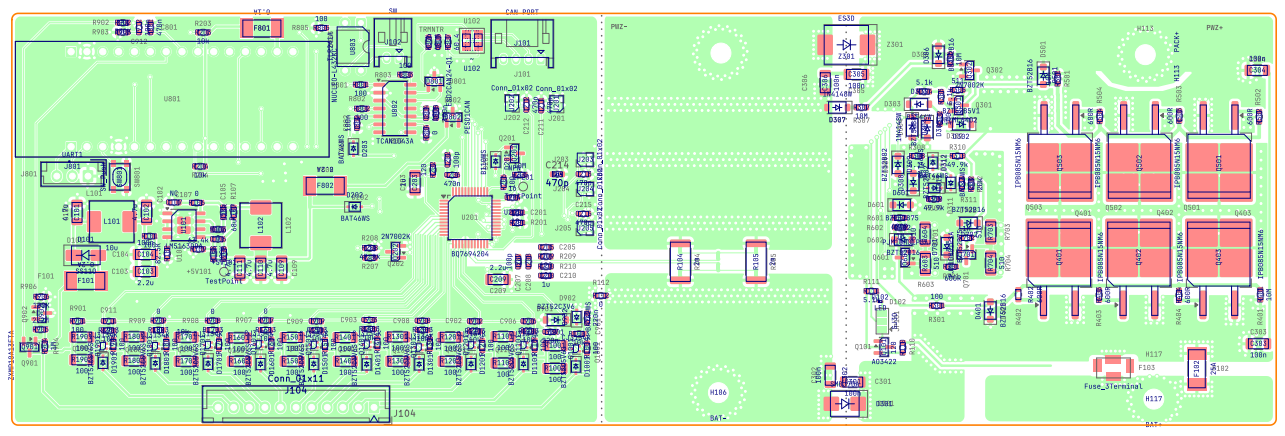
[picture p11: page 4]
Conn_01x11 J104

AUTHOR: Liashenko V Board2Pdf: Colored TOP - Page 4/4

Sheet: Colored TOP HOME

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

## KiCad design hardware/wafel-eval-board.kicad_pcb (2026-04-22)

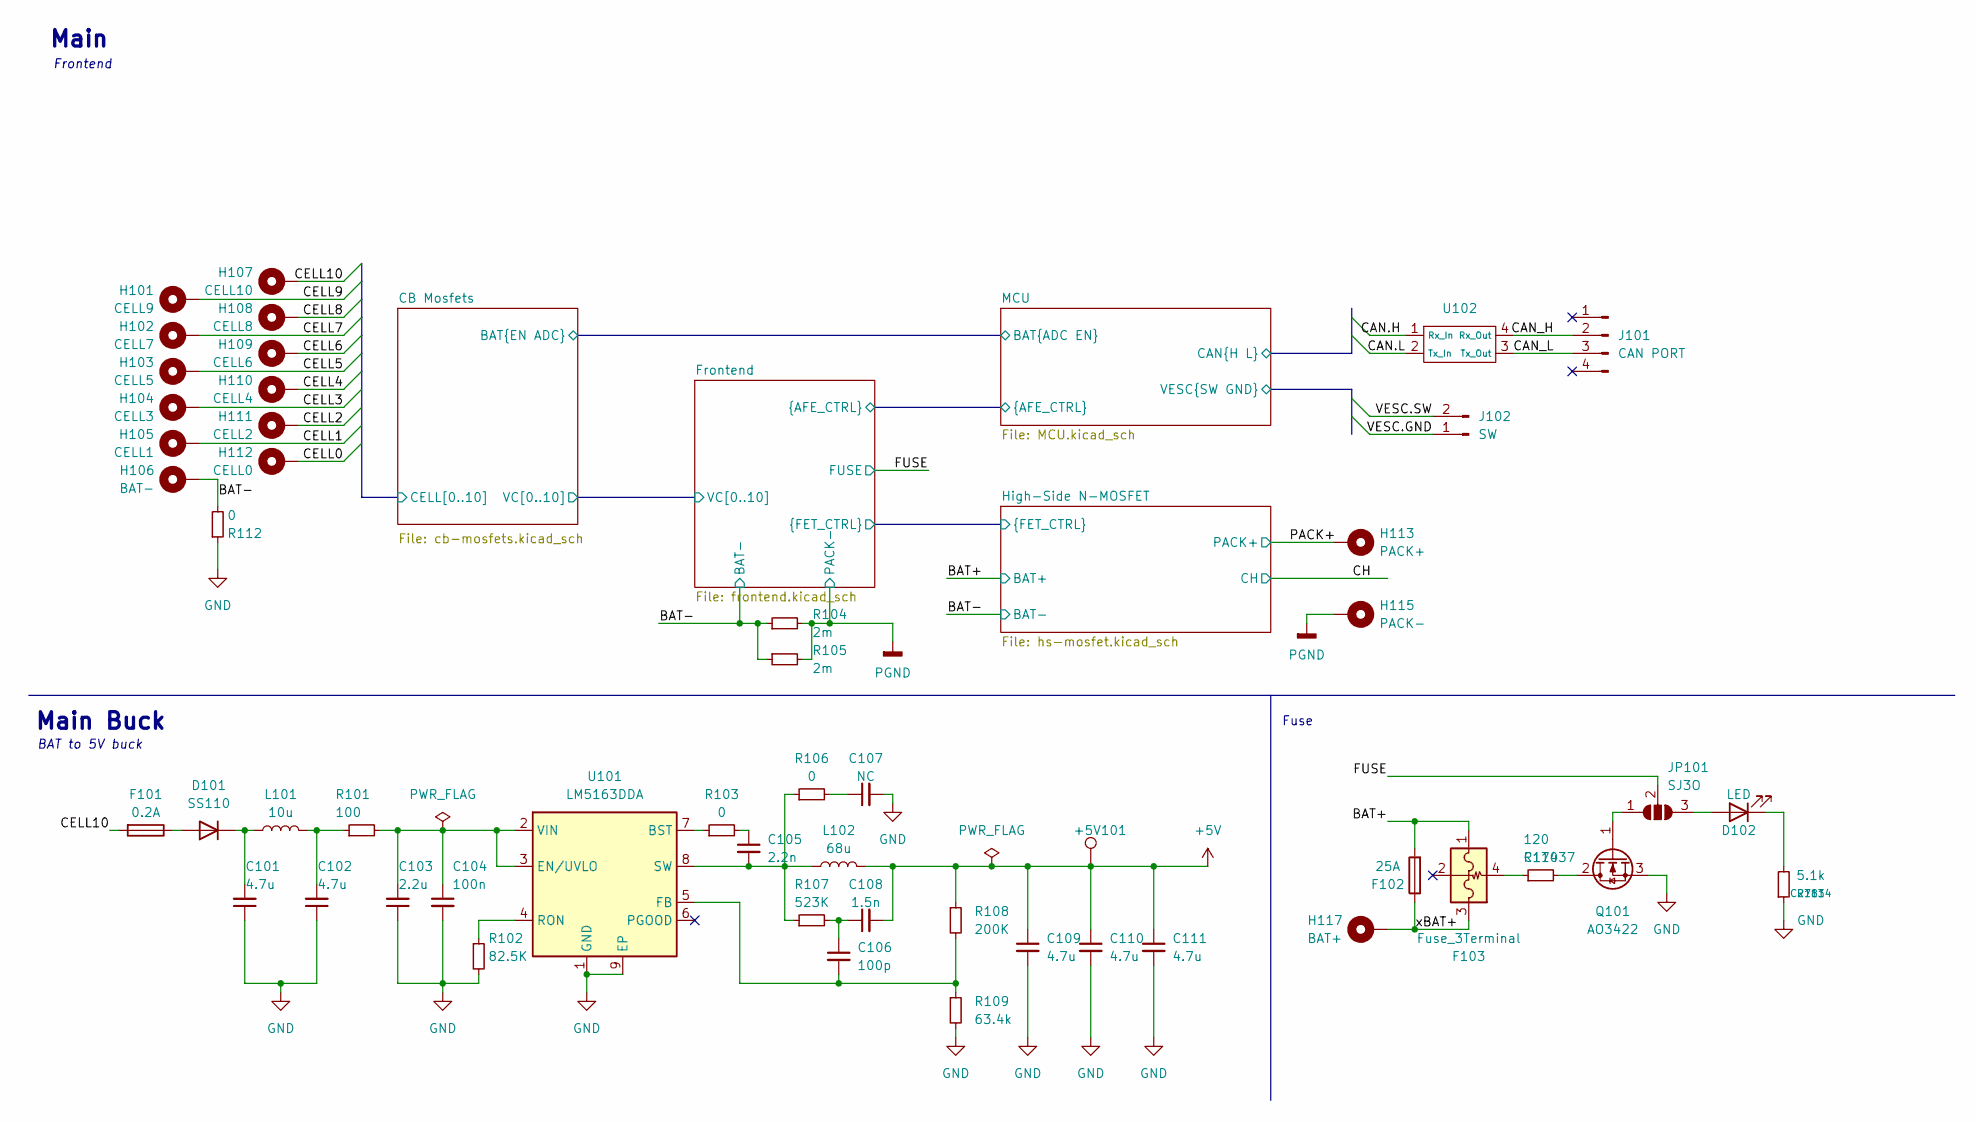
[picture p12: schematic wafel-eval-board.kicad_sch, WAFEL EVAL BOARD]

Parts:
+5V101: TestPoint; TestPoint_Pad_D1.0mm
C101, C102, C109, C110, C111: 4.7u; C_1206_3216Metric; LCSC C577211
C103: 2.2u; C_1206_3216Metric; LCSC C577211
C104: 100n; C_1206_3216Metric; LCSC C1945
C105: 2.2n; C_0603_1608Metric; LCSC C106861
C106: 100p; C_0603_1608Metric
C107: NC; C_0603_1608Metric
C108: 1.5n; C_0603_1608Metric
D101: SS110; D_SMA; LCSC C18199178
D102: LED; LED_0201_0603Metric
F101: 0.2A; Fuse_Littelfuse-NANO2-451_453; LCSC C178980
F102: 25A; Fuse_Littelfuse-NANO2-451_453; LCSC C178980
F103: Fuse_3Terminal; Fuse_ITV5432
H101: CELL9; MountingHole_3.2mm_M3_Pad
H102: CELL7; MountingHole_3.2mm_M3_Pad
H103: CELL5; MountingHole_3.2mm_M3_Pad
H104: CELL3; MountingHole_3.2mm_M3_Pad
H105: CELL1; MountingHole_3.2mm_M3_Pad
H106: BAT-; MountingHole_3.2mm_M3_Pad
H107: CELL10; MountingHole_3.2mm_M3_Pad
H108: CELL8; MountingHole_3.2mm_M3_Pad
H109: CELL6; MountingHole_3.2mm_M3_Pad
H110: CELL4; MountingHole_3.2mm_M3_Pad
H111: CELL2; MountingHole_3.2mm_M3_Pad
H112: CELL0; MountingHole_3.2mm_M3_Pad
H113: PACK+; MountingHole_3.2mm_M3_Pad
H115: PACK-; MountingHole_3.2mm_M3_Pad
H117: BAT+; MountingHole_3.2mm_M3_Pad
J101: CAN PORT; JST_PH_S4B-PH-K_1x04_P2.00mm_Horizontal
J102: SW; JST_PH_S2B-PH-K_1x02_P2.00mm_Horizontal
JP101: SJ3O; SolderJumper-3_P1.3mm_Open_Pad1.0x1.5mm
L101: 10u; L_KOHERelec_MDA7030; LCSC C2894721
L102: 68u; L_KOHERelec_MDA7030; LCSC C2894721
Q101: AO3422; SOT-23
R101: 100; R_0603_1608Metric; LCSC C17408
R102: 82.5K; R_0603_1608Metric; LCSC C3013228
R103: 0; R_0603_1608Metric; LCSC C17477
R104, R105: 2m; R_2512_6332Metric
R106, R112: 0; R_0603_1608Metric
R107: 523K; R_0603_1608Metric; LCSC C17742
R108: 200K; R_0603_1608Metric; LCSC C17539
R109: 63.4k; R_0603_1608Metric; LCSC C49654429
R110: 120; R_0603_1608Metric; LCSC C17437
R111: 5.1k; R_0603_1608Metric; LCSC C27834
U101: LM5163DDA; HSOP-8-1EP_3.9x4.9mm_P1.27mm_EP2.41x3.1mm_ThermalVias; LCSC C2873264
U102: poka-yoke_rxtx

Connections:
+5V: +5V101.1 (1_1), C108.2, C109.1, C110.1, C111.1, L102.2, R108.1; also elsewhere on the board
/BAT+: F102.2, F103.1; also elsewhere on the board
/BAT-: H106.1 (1_1), R104.1, R105.1, R112.2; also elsewhere on the board
/CAN_H: J101.2, U102.4 (Rx_Out)
/CAN_L: J101.3, U102.3 (Tx_Out)
/CB Mosfets/CELL0: H112.1 (1_1); also elsewhere on the board
/CB Mosfets/CELL1: H105.1 (1_1); also elsewhere on the board
/CB Mosfets/CELL2: H111.1 (1_1); also elsewhere on the board
/CB Mosfets/CELL3: H104.1 (1_1); also elsewhere on the board
/CB Mosfets/CELL4: H110.1 (1_1); also elsewhere on the board
/CB Mosfets/CELL5: H103.1 (1_1); also elsewhere on the board
/CB Mosfets/CELL6: H109.1 (1_1); also elsewhere on the board
/CB Mosfets/CELL7: H102.1 (1_1); also elsewhere on the board
/CB Mosfets/CELL8: H108.1 (1_1); also elsewhere on the board
/CB Mosfets/CELL9: H101.1 (1_1); also elsewhere on the board
/CB Mosfets/CELL10: F101.2, H107.1 (1_1); also elsewhere on the board
/FUSE: JP101.2 (C); also elsewhere on the board
/MCU/CAN.H: U102.1 (Rx_In); also elsewhere on the board
/MCU/CAN.L: U102.2 (Tx_In); also elsewhere on the board
/MCU/VESC.GND: J102.1; also elsewhere on the board
/MCU/VESC.SW: J102.2; also elsewhere on the board
/PACK+: H113.1 (1_1); also elsewhere on the board
/xBAT+: F102.1, F103.3, H117.1 (1_1)
GND: C101.1, C102.1, C103.1, C104.2, C107.2, C109.2, C110.2, C111.2, Q101.3 (S), R102.2, R109.2, R111.1, R112.1, U101.1 (GND), U101.9 (EP); also elsewhere on the board
unnamed: C102.2, L101.2, R101.1
unnamed: C105.1, R103.2
unnamed: C106.1, C108.1, R107.2
unnamed: C107.1, R106.2
unnamed: D101.2 (A), F101.1
unnamed: C101.2, D101.1 (K), L101.1
unnamed: D102.2 (A), JP101.3 (B)
unnamed: D102.1 (K), R111.2
unnamed: F103.4, R110.1
unnamed: JP101.1 (A), Q101.1 (G)
unnamed: Q101.2 (D), R110.2
unnamed: R103.1, U101.7 (BST)
unnamed: C103.2, C104.1, R101.2, U101.2 (VIN), U101.3 (EN/UVLO)
unnamed: C106.2, R108.2, R109.1, U101.5 (FB)
unnamed: R102.1, U101.4 (RON)
unnamed: C105.2, L102.1, R106.1, R107.1, U101.8 (SW)
PGND: H115.1 (1_1), R104.2, R105.2; also elsewhere on the board

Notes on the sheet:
Fuse
BAT to 5V buck
Frontend
Main Buck
Main

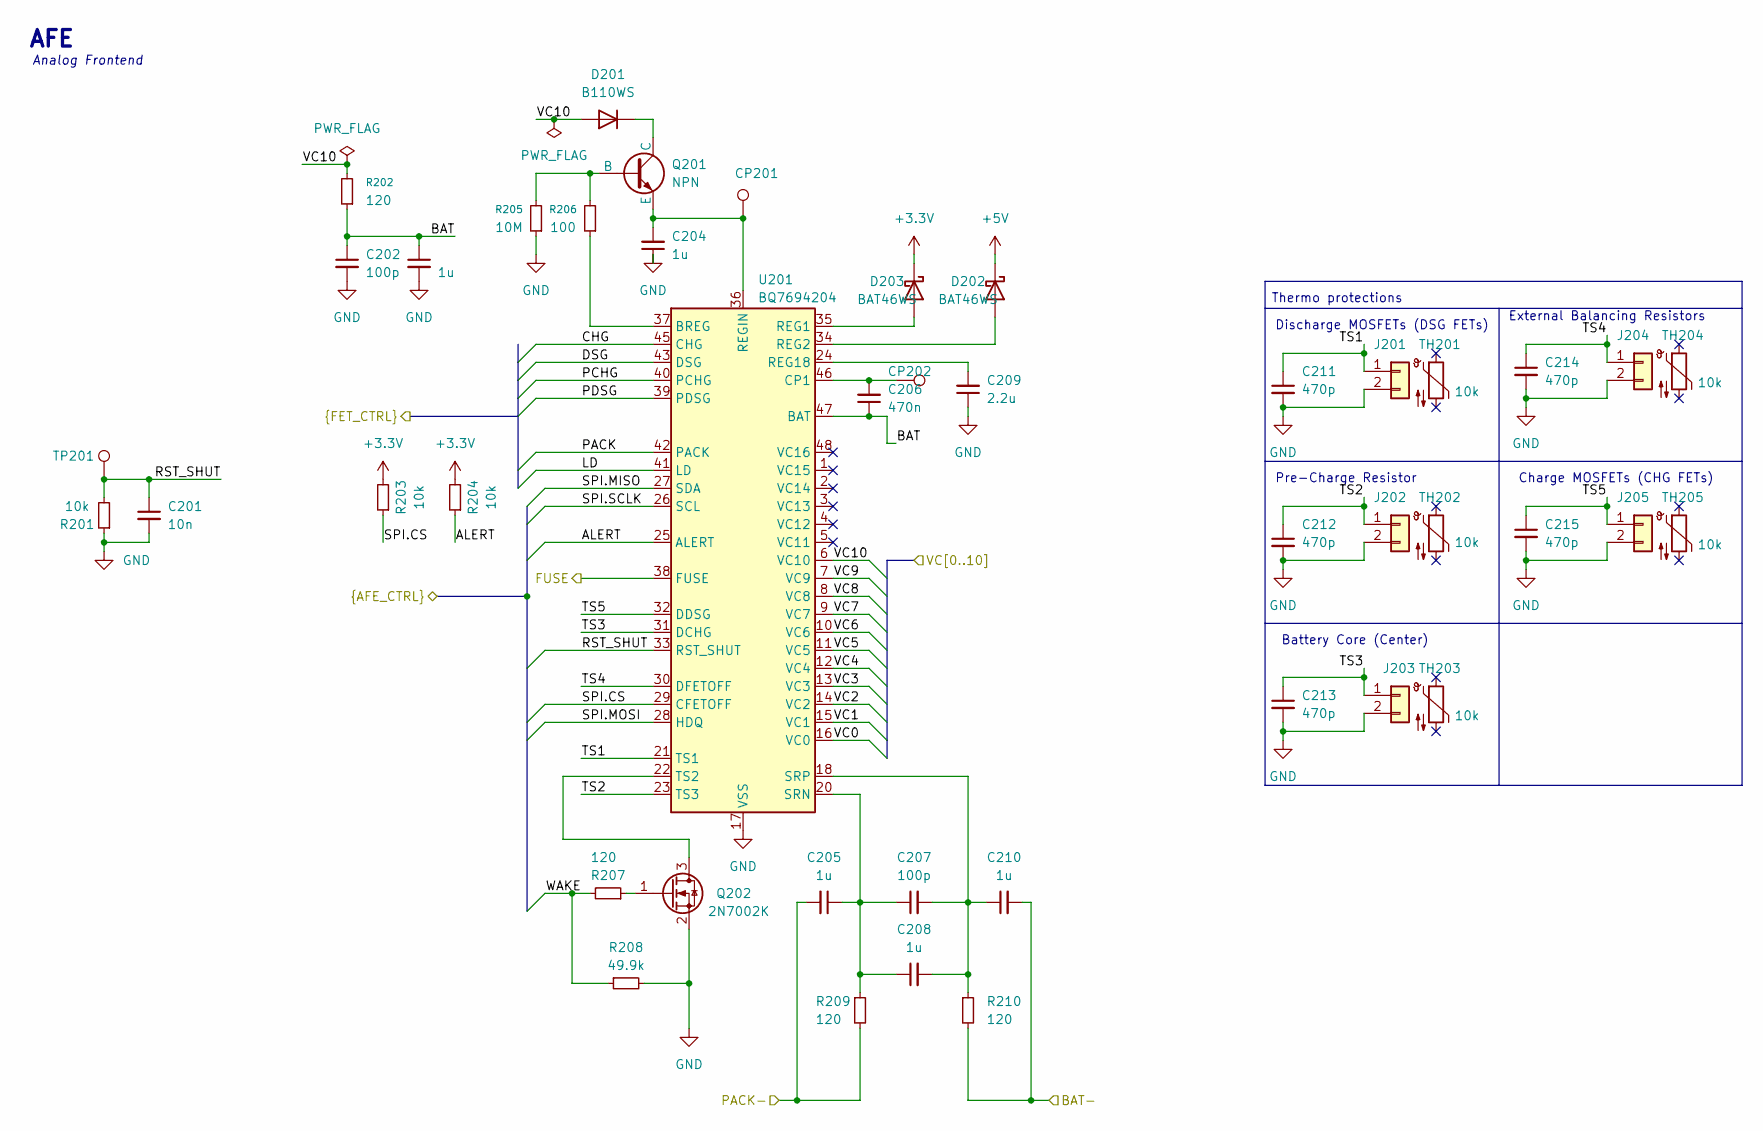
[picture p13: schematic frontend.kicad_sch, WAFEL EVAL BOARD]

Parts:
C201: 10n; C_0603_1608Metric
C202, C207: 100p; C_0603_1608Metric
C203: 1u; C_1206_3216Metric
C204, C205, C208, C210: 1u; C_0603_1608Metric
C206: 470n; C_0603_1608Metric
C209: 2.2u; C_1206_3216Metric; LCSC C577211
C211, C212, C213, C214, C215: 470p; C_0603_1608Metric
CP201, CP202: TestPoint; TestPoint_Pad_D1.0mm
D201: B110WS; D_SOD-323; LCSC C7461125
D202, D203: BAT46WS; D_SOD-323; LCSC C7502692
J201, J202, J203, J204, J205: Conn_01x02; PinHeader_1x02_P1.27mm_Vertical
Q201: NPN; SOT-23; Manufacturer_Part_Number FMMT458TA; Mouser Part Number 522-FMMT458TA
Q202: 2N7002K; SOT-23
R201, R203, R204: 10k; R_0603_1608Metric
R202, R207, R209, R210: 120; R_0603_1608Metric
R205: 10M; R_0603_1608Metric
R206: 100; R_0603_1608Metric
R208: 49.9k; R_0603_1608Metric
TH201, TH202, TH203, TH204, TH205: 10k; R_0603_1608Metric; LCSC C84036
TP201: TestPoint; TestPoint_Pad_D1.0mm
U201: BQ7694204; TQFP-48_7x7mm_P0.5mm

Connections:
+3.3V: D203.1 (K), R203.2, R204.2; also elsewhere on the board
+5V: D202.1 (K); also elsewhere on the board
/BAT-: C210.2, R210.2; also elsewhere on the board
/CB Mosfets/VC0: U201.16 (VC0); also elsewhere on the board
/CB Mosfets/VC1: U201.15 (VC1); also elsewhere on the board
/CB Mosfets/VC2: U201.14 (VC2); also elsewhere on the board
/CB Mosfets/VC3: U201.13 (VC3); also elsewhere on the board
/CB Mosfets/VC4: U201.12 (VC4); also elsewhere on the board
/CB Mosfets/VC5: U201.11 (VC5); also elsewhere on the board
/CB Mosfets/VC6: U201.10 (VC6); also elsewhere on the board
/CB Mosfets/VC7: U201.9 (VC7); also elsewhere on the board
/CB Mosfets/VC8: U201.8 (VC8); also elsewhere on the board
/CB Mosfets/VC9: U201.7 (VC9); also elsewhere on the board
/CB Mosfets/VC10: D201.2 (A), R202.2, U201.6 (VC10); also elsewhere on the board
/FUSE: U201.38 (FUSE); also elsewhere on the board
/Frontend/ALERT: R204.1, U201.25 (ALERT); also elsewhere on the board
/Frontend/BAT: C202.1, C203.1, C206.1, R202.1, U201.47 (BAT)
/Frontend/CHG: U201.45 (CHG); also elsewhere on the board
/Frontend/DSG: U201.43 (DSG); also elsewhere on the board
/Frontend/LD: U201.41 (LD); also elsewhere on the board
/Frontend/PACK: U201.42 (PACK); also elsewhere on the board
/Frontend/PCHG: U201.40 (PCHG); also elsewhere on the board
/Frontend/PDSG: U201.39 (PDSG); also elsewhere on the board
/Frontend/RST_SHUT: C201.1, R201.2, TP201.1 (1_1), U201.33 (RST_SHUT); also elsewhere on the board
/Frontend/SPI.CS: R203.1, U201.29 (CFETOFF); also elsewhere on the board
/Frontend/SPI.MISO: U201.27 (SDA); also elsewhere on the board
/Frontend/SPI.MOSI: U201.28 (HDQ); also elsewhere on the board
/Frontend/SPI.SCLK: U201.26 (SCL); also elsewhere on the board
/Frontend/TS1: C211.1, J201.1, U201.21 (TS1)
/Frontend/TS2: C212.1, J202.1, U201.23 (TS3)
/Frontend/TS3: C213.1, J203.1, U201.31 (DCHG)
/Frontend/TS4: C214.1, J204.1, U201.30 (DFETOFF); also elsewhere on the board
/Frontend/TS5: C215.1, J205.1, U201.32 (DDSG)
/Frontend/WAKE: R207.2, R208.1; also elsewhere on the board
GND: C201.2, C202.2, C203.2, C204.1, C209.1, C211.2, C212.2, C213.2, C215.2, J201.2, J202.2, J203.2, J204.2, J205.2, Q202.2 (S), R201.1, R205.1, R208.2, U201.17 (VSS); also elsewhere on the board
unnamed: D201.1 (K), Q201.1 (C)
unnamed: D202.2 (A), U201.34 (REG2)
unnamed: D203.2 (A), U201.35 (REG1)
unnamed: Q201.2 (B), R205.2, R206.2
unnamed: C204.2, CP201.1 (1_1), Q201.3 (E), U201.36 (REGIN)
unnamed: Q202.3 (D), U201.22 (TS2)
unnamed: Q202.1 (G), R207.1
unnamed: R206.1, U201.37 (BREG)
unnamed: C206.2, CP202.1 (1_1), U201.46 (CP1)
unnamed: C209.2, U201.24 (REG18)
unnamed: C205.1, C207.1, C208.1, R209.1, U201.20 (SRN)
unnamed: C207.2, C208.2, C210.1, R210.1, U201.18 (SRP)
PGND: C205.2, R209.2; also elsewhere on the board

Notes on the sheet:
Discharge MOSFETs (DSG FETs)
Analog Frontend
Battery Core (Center)
External Balancing Resistors
Charge MOSFETs (CHG FETs)
AFE
Pre-Charge Resistor
Thermo protections

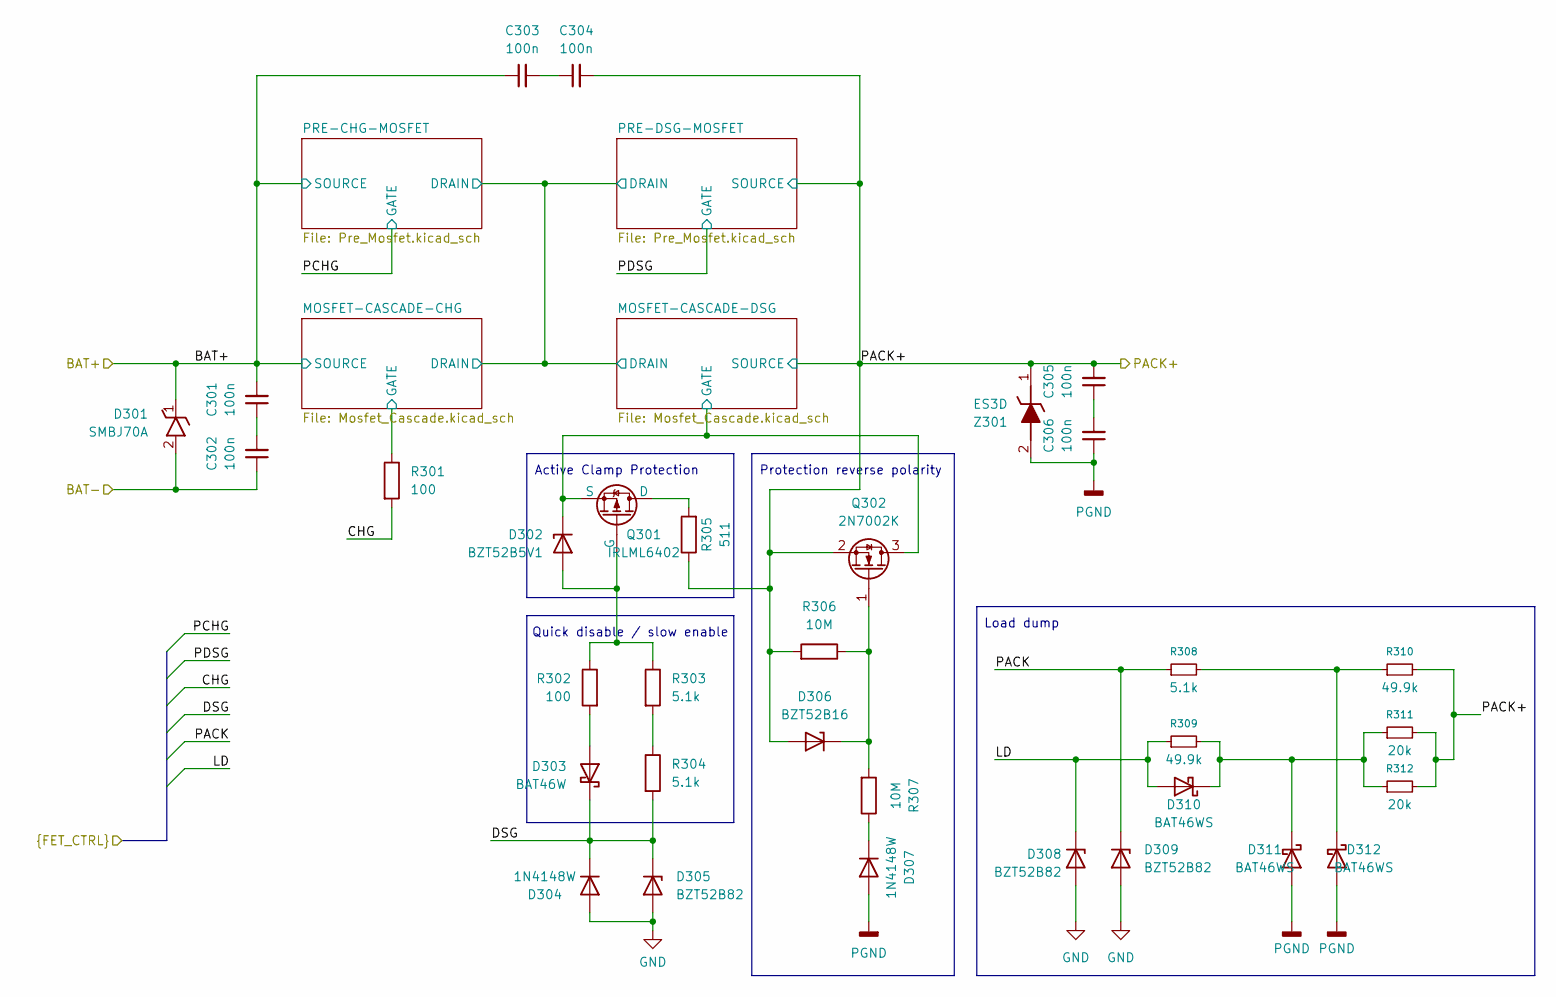
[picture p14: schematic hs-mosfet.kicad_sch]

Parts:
C301, C302, C303, C304, C305, C306: 100n; C_1206_3216Metric; Voltage 100V; LCSC C110255
D301: SMBJ70A; D_SMB; Manufacturer_Part_Number SMBJ70A
D302: BZT52B5V1; D_SOD-123
D303: BAT46W; D_SOD-123
D304, D307: 1N4148W; D_SOD-123
D305, D308, D309: BZT52B82; D_SOD-123F
D306: BZT52B16; D_SOD-123F
D310, D311, D312: BAT46WS; D_SOD-323; LCSC C7502692
Q301: IRLML6402; SOT-23
Q302: 2N7002K; SOT-23
R301, R302: 100; R_0603_1608Metric
R303, R304, R308: 5.1k; R_0603_1608Metric
R305: 511; R_0603_1608Metric
R306, R307: 10M; R_0603_1608Metric
R309, R310: 49.9k; R_0603_1608Metric
R311, R312: 20k; R_0603_1608Metric
Z301: ES3D; D_SMC; Manufacturer_Part_Number ES3D; Mouser Part Number 512-ES3D

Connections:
/BAT+: C301.2, C303.1, D301.1 (K); also elsewhere on the board
/BAT-: C302.1, D301.2 (A); also elsewhere on the board
/Frontend/CHG: R301.2; also elsewhere on the board
/Frontend/DSG: D303.1 (K), D304.1 (K), D305.1 (K), R304.2; also elsewhere on the board
/Frontend/LD: D308.1 (K), D310.2 (A), R309.1; also elsewhere on the board
/Frontend/PACK: D309.1 (K), R308.1; also elsewhere on the board
/High-Side N-MOSFET/MOSFET-CASCADE-CHG/GATE: R301.1; also elsewhere on the board
/High-Side N-MOSFET/MOSFET-CASCADE-DSG/GATE: D302.1 (K), Q301.3 (S), Q302.3 (D); also elsewhere on the board
/PACK+: C304.2, C305.2, D306.2 (A), Q302.2 (S), R305.1, R306.2, R310.2, R311.2, R312.2, Z301.1 (K); also elsewhere on the board
GND: D304.2 (A), D305.2 (A), D308.2 (A), D309.2 (A); also elsewhere on the board
unnamed: C301.1, C302.2
unnamed: C303.2, C304.1
unnamed: C305.1, C306.2
unnamed: D302.2 (A), Q301.2 (G), R302.1, R303.1
unnamed: D303.2 (A), R302.2
unnamed: D306.1 (K), Q302.1 (G), R306.1, R307.2
unnamed: D307.1 (K), R307.1
unnamed: D310.1 (K), D311.1 (K), R309.2, R311.1, R312.1
unnamed: D312.1 (K), R308.2, R310.1
unnamed: Q301.1 (D), R305.2
unnamed: R303.2, R304.1
PGND: C306.1, D307.2 (A), D311.2 (A), D312.2 (A), Z301.2 (A); also elsewhere on the board

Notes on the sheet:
Load dump
Protection reverse polarity
Quick disable / slow enable
Active Clamp Protection

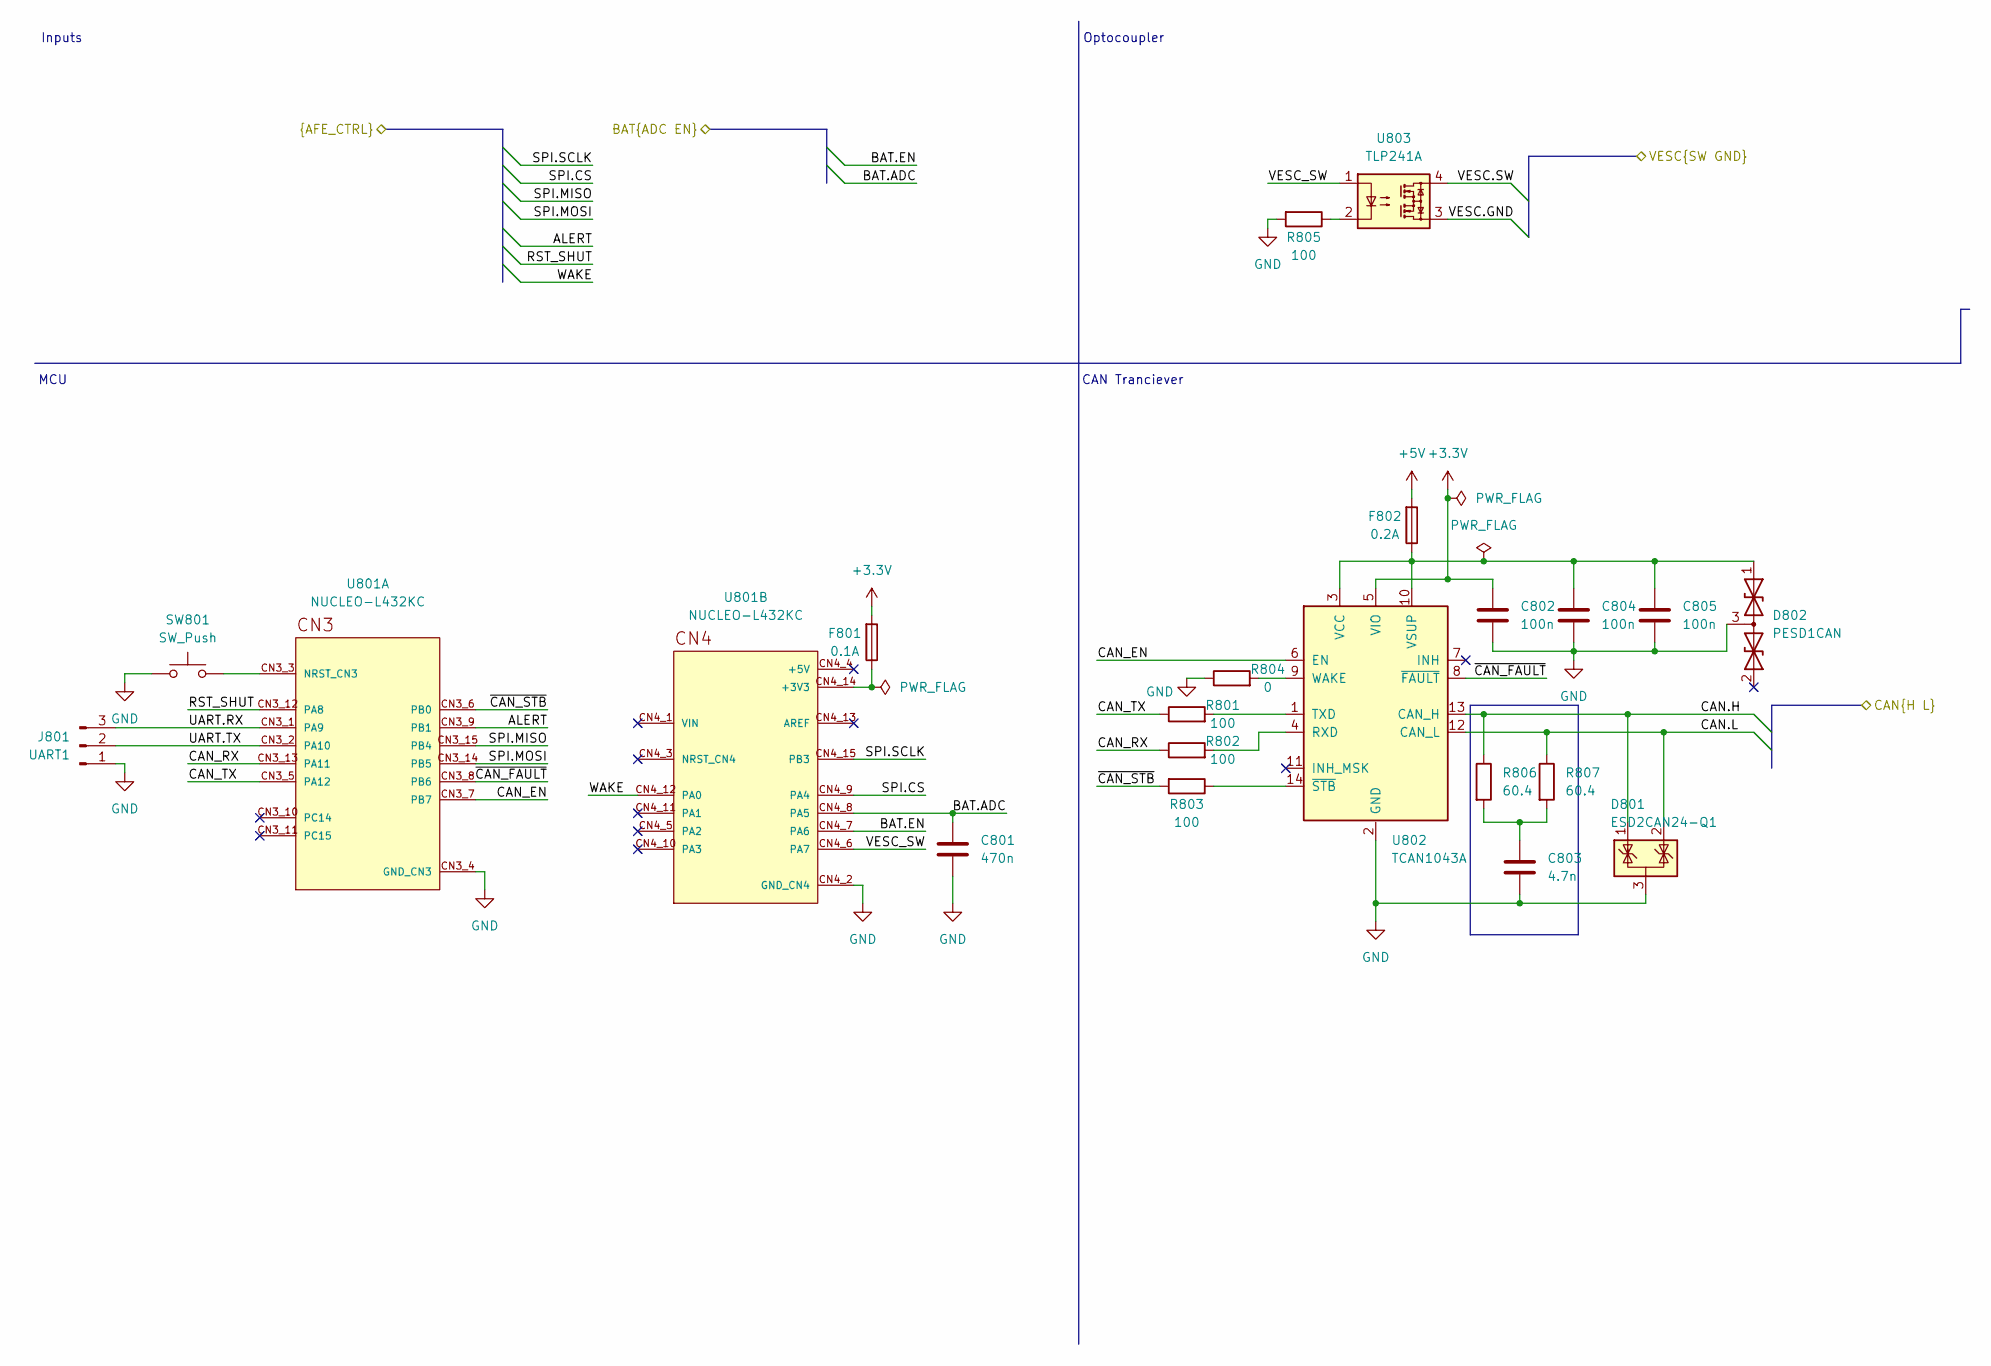
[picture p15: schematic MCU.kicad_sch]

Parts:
C801: 470n; C_0603_1608Metric
C802, C804, C805: 100n; C_0603_1608Metric; LCSC C14663
C803: 4.7n; C_0603_1608Metric; LCSC C14663
D801: ESD2CAN24-Q1; SOT-23
D802: PESD1CAN; SOT-23; LCSC C2687121
F801: 0.1A; Fuse_Littelfuse-NANO2-451_453; LCSC C178980
F802: 0.2A; Fuse_Littelfuse-NANO2-451_453; LCSC C178980
J801: UART1; JST_EH_B3B-EH-A_1x03_P2.50mm_Vertical
R801, R802, R803, R805: 100; R_0603_1608Metric; LCSC C22775
R804: 0; R_0603_1608Metric; LCSC C22775
R806, R807: 60.4; R_0603_1608Metric; LCSC C23090
SW801: SW_Push; SW_SPST_PTS810; LCSC C720477
U801: NUCLEO-L432KC; MODULE_NUCLEO-L432KC; PARTREV N/A
U802: TCAN1043A; SOIC-14_3.9x8.7mm_P1.27mm; MPN TCAN1043ADRQ1; LCSC C5215847
U803: TLP241A; DIP-4_W7.62mm

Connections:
+3.3V: C802.1, F801.2, U802.5 (VIO); also elsewhere on the board
+5V: F802.2; also elsewhere on the board
/CB Mosfets/BAT.ADC: C801.1, U801.CN4_8 (PA5); also elsewhere on the board
/CB Mosfets/BAT.EN: U801.CN4_7 (PA6); also elsewhere on the board
/Frontend/ALERT: U801.CN3_9 (PB1); also elsewhere on the board
/Frontend/RST_SHUT: U801.CN3_12 (PA8); also elsewhere on the board
/Frontend/SPI.CS: U801.CN4_9 (PA4); also elsewhere on the board
/Frontend/SPI.MISO: U801.CN3_15 (PB4); also elsewhere on the board
/Frontend/SPI.MOSI: U801.CN3_14 (PB5); also elsewhere on the board
/Frontend/SPI.SCLK: U801.CN4_15 (PB3); also elsewhere on the board
/Frontend/WAKE: U801.CN4_12 (PA0); also elsewhere on the board
/MCU/CAN.H: D801.1 (K), R806.1, U802.13 (CAN_H); also elsewhere on the board
/MCU/CAN.L: D801.2 (K), R807.1, U802.12 (CAN_L); also elsewhere on the board
/MCU/CAN_EN: U801.CN3_7 (PB7), U802.6 (EN)
/MCU/CAN_RX: R802.1, U801.CN3_13 (PA11)
/MCU/CAN_TX: R801.1, U801.CN3_5 (PA12)
/MCU/UART.RX: J801.3, U801.CN3_1 (PA9)
/MCU/UART.TX: J801.2, U801.CN3_2 (PA10)
/MCU/VESC.GND: U803.3; also elsewhere on the board
/MCU/VESC.SW: U803.4; also elsewhere on the board
/MCU/VESC_SW: U801.CN4_6 (PA7), U803.1
/MCU/~CAN_FAULT: U801.CN3_8 (PB6), U802.8 (~FAULT)
/MCU/~CAN_STB: R803.2, U801.CN3_6 (PB0)
GND: C801.2, C802.2, C803.2, C804.2, C805.2, D801.3 (A), D802.3 (common), J801.1, R804.1, R805.2, SW801.1, U801.CN3_4 (GND_CN3), U801.CN4_2 (GND_CN4), U802.2 (GND); also elsewhere on the board
unnamed: C803.1, R806.2, R807.2
unnamed: C804.1, C805.1, D802.1 (A1), F802.1, U802.3 (VCC), U802.10 (VSUP)
unnamed: R805.1, U803.2
unnamed: SW801.2, U801.CN3_3 (NRST_CN3)
unnamed: F801.1, U801.CN4_14 (+3V3)
unnamed: R802.2, U802.4 (RXD)
unnamed: R801.2, U802.1 (TXD)
unnamed: R804.2, U802.9 (WAKE)
unnamed: R803.1, U802.14 (~STB)

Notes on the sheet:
CAN Tranciever
MCU
Inputs
Optocoupler

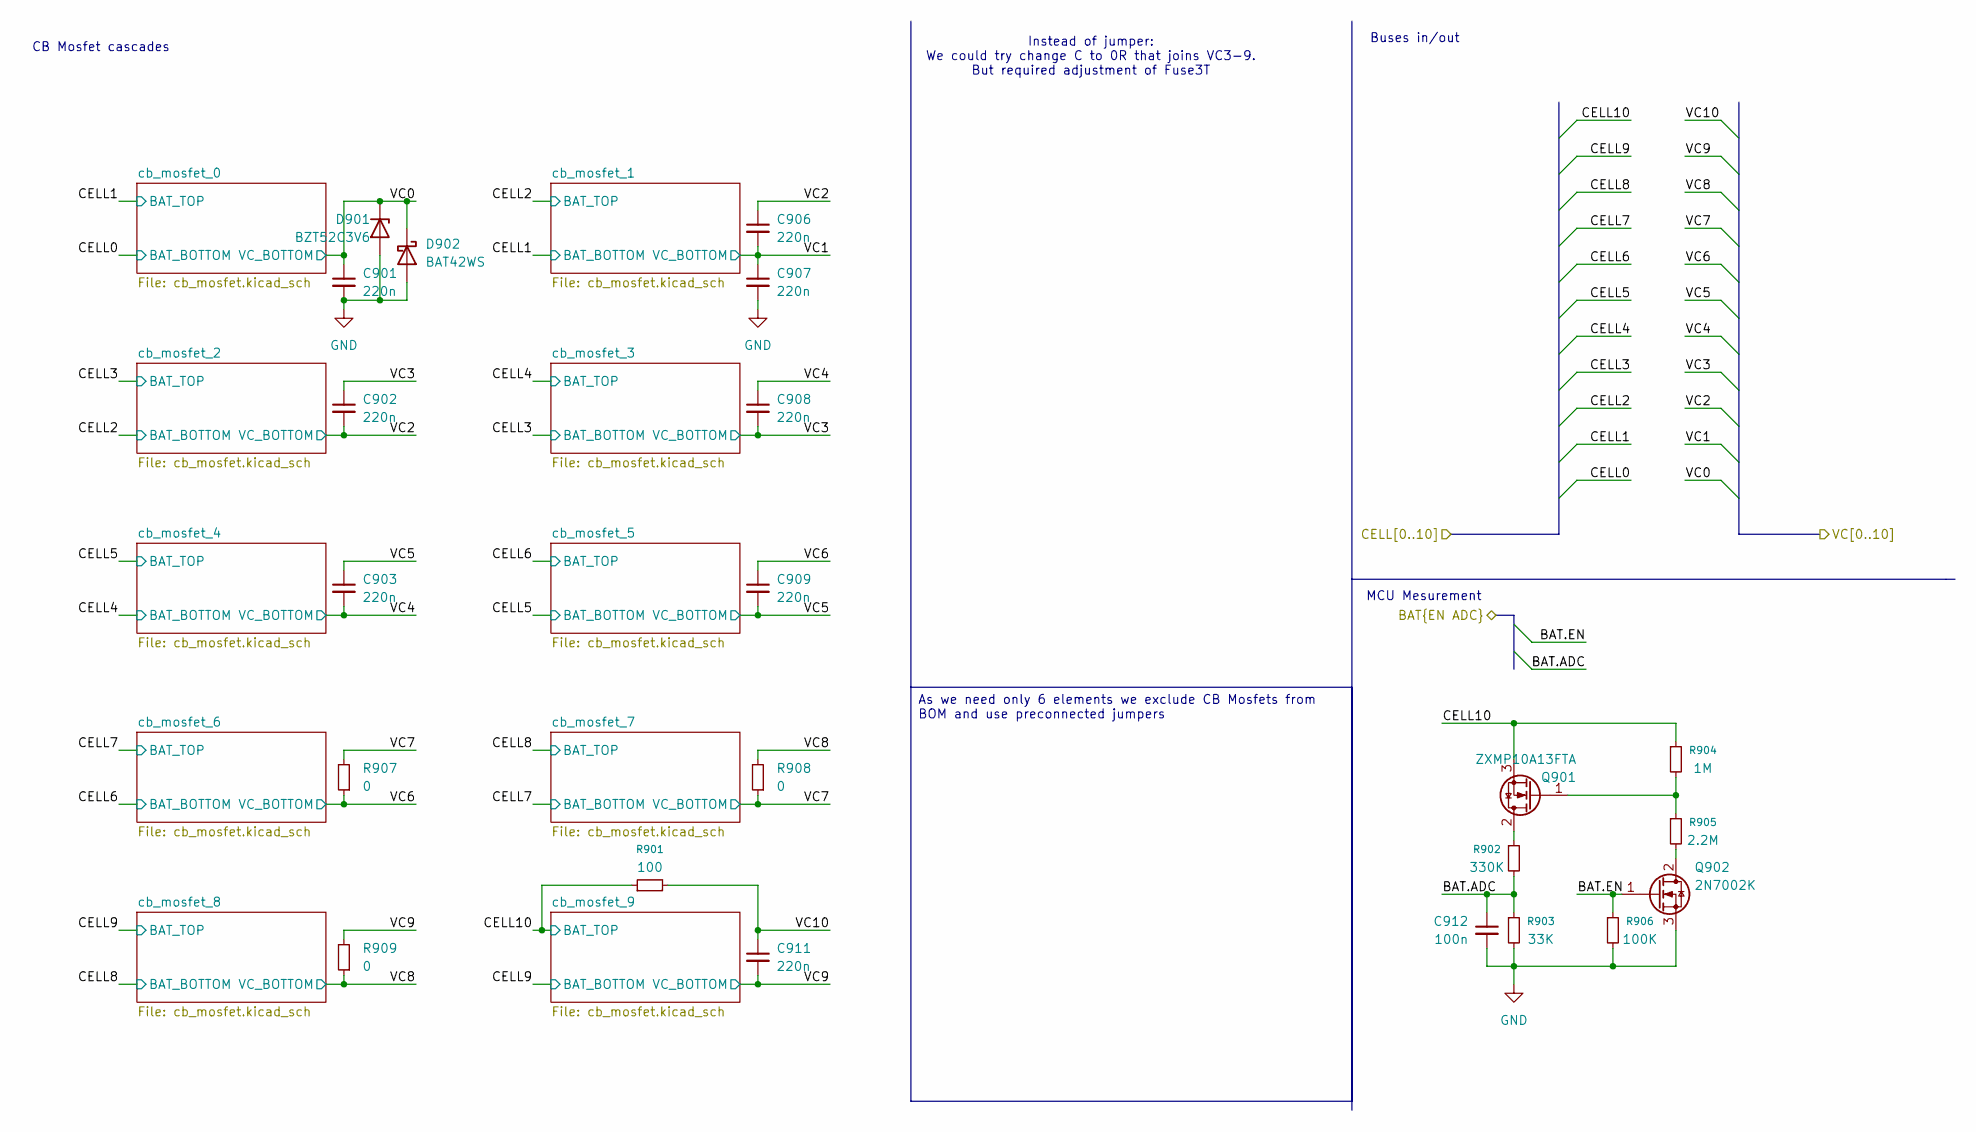
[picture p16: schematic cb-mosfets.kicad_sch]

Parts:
C901, C902, C903, C906, C907, C908, C909, C911: 220n; C_0603_1608Metric; LCSC C5378
C912: 100n; C_0603_1608Metric
D901: BZT52C3V6; D_SOD-123; LCSC C19077397
D902: BAT42WS; D_SOD-323F; LCSC C22466360
Q901: ZXMP10A13FTA; SOT-23
Q902: 2N7002K; SOT-23
R901: 100; R_0603_1608Metric; LCSC C17408
R902: 330K; R_0603_1608Metric; LCSC C17408
R903: 33K; R_0603_1608Metric; LCSC C17408
R904: 1M; R_0603_1608Metric; LCSC C17408
R905: 2.2M; R_0603_1608Metric; LCSC C17408
R906: 100K; R_0603_1608Metric; LCSC C17408
R907, R908, R909: 0; R_0603_1608Metric

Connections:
/CB Mosfets/BAT.ADC: C912.1, R902.2, R903.1; also elsewhere on the board
/CB Mosfets/BAT.EN: Q902.1 (G), R906.1; also elsewhere on the board
/CB Mosfets/CELL10: Q901.3 (S), R901.1, R904.1; also elsewhere on the board
/CB Mosfets/VC0: C901.1, D901.1 (K), D902.1 (K); also elsewhere on the board
/CB Mosfets/VC1: C906.2, C907.1; also elsewhere on the board
/CB Mosfets/VC2: C902.2, C906.1; also elsewhere on the board
/CB Mosfets/VC3: C902.1, C908.2; also elsewhere on the board
/CB Mosfets/VC4: C903.2, C908.1; also elsewhere on the board
/CB Mosfets/VC5: C903.1, C909.2; also elsewhere on the board
/CB Mosfets/VC6: C909.1, R907.1; also elsewhere on the board
/CB Mosfets/VC7: R907.2, R908.1; also elsewhere on the board
/CB Mosfets/VC8: R908.2, R909.1; also elsewhere on the board
/CB Mosfets/VC9: C911.2, R909.2; also elsewhere on the board
/CB Mosfets/VC10: C911.1, R901.2; also elsewhere on the board
GND: C901.2, C907.2, C912.2, D901.2 (A), D902.2 (A), Q902.3 (S), R903.2, R906.2; also elsewhere on the board
unnamed: Q901.2 (D), R902.1
unnamed: Q901.1 (G), R904.2, R905.1
unnamed: Q902.2 (D), R905.2

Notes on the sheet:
CB Mosfet cascades
Buses in/out
MCU Mesurement
Instead of jumper: We could try change C to 0R that joins VC3-9. But required adjustment of Fuse3T
As we need only 6 elements we exclude CB Mosfets from BOM and use preconnected jumpers

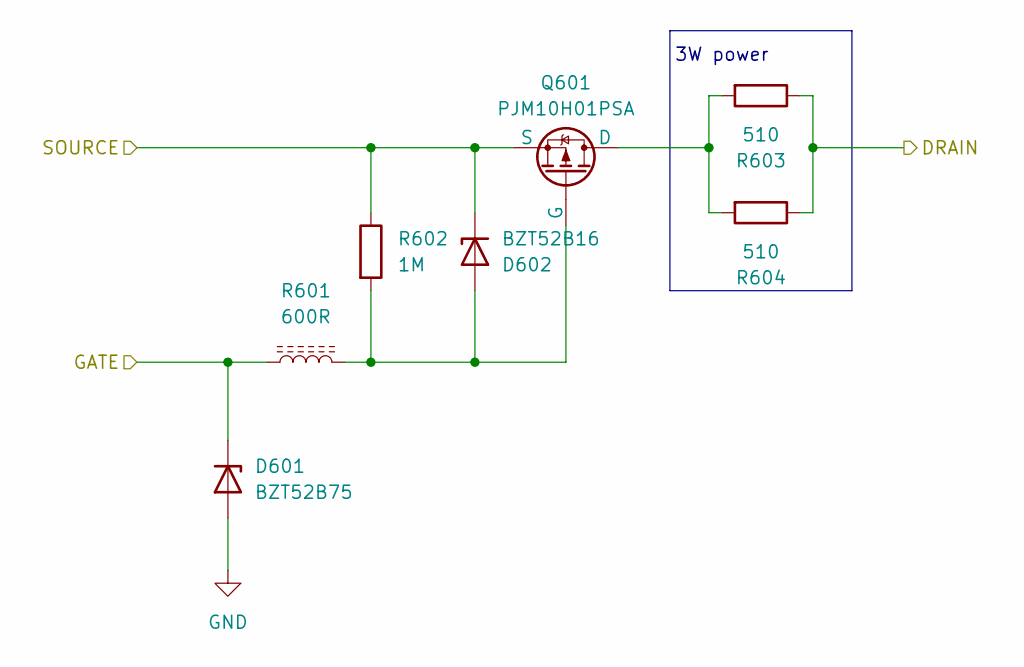
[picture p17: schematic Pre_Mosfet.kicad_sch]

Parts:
D601: BZT52B75; D_SOD-123F
D602: BZT52B16; D_SOD-123F
Q601: PJM10H01PSA; SOT-23; LCSC C2838029
R601: 600R; R_0603_1608Metric; LCSC C139183
R602: 1M; R_0603_1608Metric
R603, R604: 510; R_1206_3216Metric

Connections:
/BAT+: D602.1 (K), Q601.3 (S), R602.1; also elsewhere on the board
/Frontend/PCHG: D601.1 (K), R601.1; also elsewhere on the board
/High-Side N-MOSFET/MOSFET-CASCADE-CHG/DRAIN: R603.1, R604.1; also elsewhere on the board
GND: D601.2 (A); also elsewhere on the board
unnamed: D602.2 (A), Q601.2 (G), R601.2, R602.2
unnamed: Q601.1 (D), R603.2, R604.2

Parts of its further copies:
D701: BZT52B75; D_SOD-123F
D702: BZT52B16; D_SOD-123F
Q701: PJM10H01PSA; SOT-23; LCSC C2838029
R701: 600R; R_0603_1608Metric; LCSC C139183
R702: 1M; R_0603_1608Metric
R703, R704: 510; R_1206_3216Metric

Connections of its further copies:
/Frontend/PDSG: D701.1 (K), R701.1; also elsewhere on the board
/High-Side N-MOSFET/MOSFET-CASCADE-CHG/DRAIN: R703.1, R704.1; also elsewhere on the board
/PACK+: D702.1 (K), Q701.3 (S), R702.1; also elsewhere on the board
GND: D701.2 (A); also elsewhere on the board
unnamed: D702.2 (A), Q701.2 (G), R701.2, R702.2
unnamed: Q701.1 (D), R703.2, R704.2

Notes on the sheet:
3W power

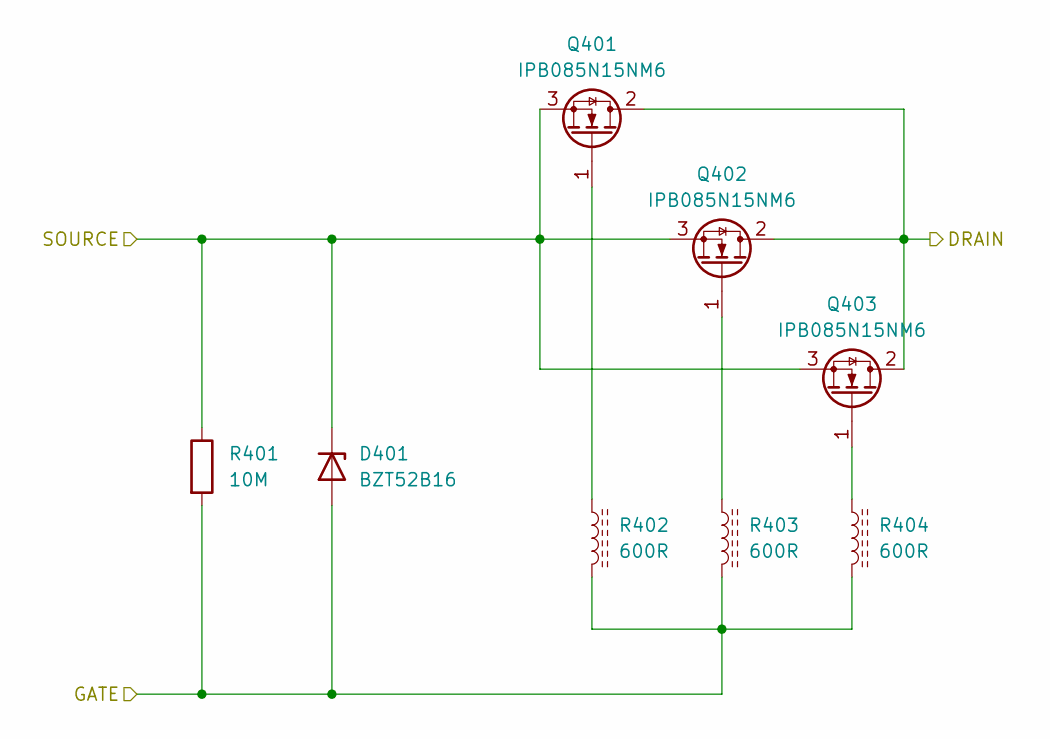
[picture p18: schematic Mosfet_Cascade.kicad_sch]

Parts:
D401: BZT52B16; D_SOD-123F
Q401, Q402, Q403: IPB085N15NM6; TO-263-2
R401: 10M; R_0603_1608Metric
R402, R403, R404: 600R; R_0603_1608Metric; LCSC C139183

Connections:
/BAT+: D401.1 (K), Q401.3 (S), Q402.3 (S), Q403.3 (S), R401.1; also elsewhere on the board
/High-Side N-MOSFET/MOSFET-CASCADE-CHG/DRAIN: Q401.2 (D), Q402.2 (D), Q403.2 (D); also elsewhere on the board
/High-Side N-MOSFET/MOSFET-CASCADE-CHG/GATE: D401.2 (A), R401.2, R402.2, R403.2, R404.2; also elsewhere on the board
unnamed: Q401.1 (G), R402.1
unnamed: Q402.1 (G), R403.1
unnamed: Q403.1 (G), R404.1

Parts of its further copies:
D501: BZT52B16; D_SOD-123F
Q501, Q502, Q503: IPB085N15NM6; TO-263-2
R501: 10M; R_0603_1608Metric
R502, R503, R504: 600R; R_0603_1608Metric; LCSC C139183

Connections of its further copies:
/High-Side N-MOSFET/MOSFET-CASCADE-CHG/DRAIN: Q501.2 (D), Q502.2 (D), Q503.2 (D); also elsewhere on the board
/High-Side N-MOSFET/MOSFET-CASCADE-DSG/GATE: D501.2 (A), R501.2, R502.2, R503.2, R504.2; also elsewhere on the board
/PACK+: D501.1 (K), Q501.3 (S), Q502.3 (S), Q503.3 (S), R501.1; also elsewhere on the board
unnamed: Q501.1 (G), R502.1
unnamed: Q502.1 (G), R503.1
unnamed: Q503.1 (G), R504.1

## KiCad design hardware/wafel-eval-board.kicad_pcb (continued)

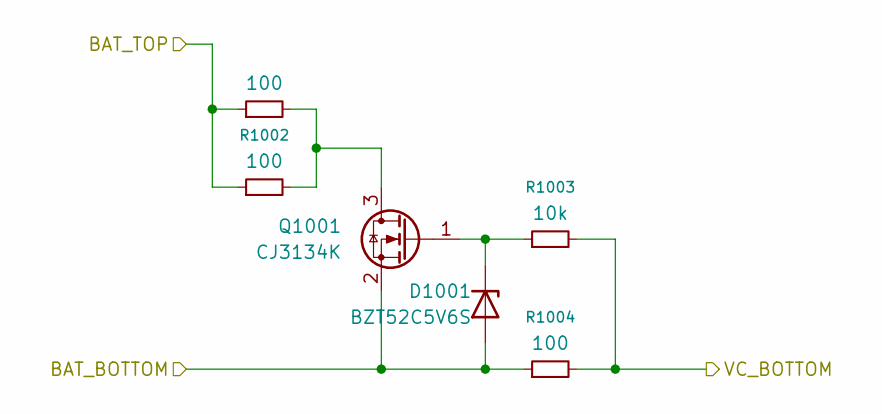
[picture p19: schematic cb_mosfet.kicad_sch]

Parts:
D1001: BZT52C5V6S; D_SOD-323; LCSC C19077441
Q1001: CJ3134K; SOT-723; LCSC C460977
R1001, R1002: 100; R_1206_3216Metric; LCSC C17901
R1003: 10k; R_0603_1608Metric; LCSC C25804
R1004: 100; R_0603_1608Metric; LCSC C22775

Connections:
/CB Mosfets/CELL0: D1001.2 (A), Q1001.2 (S), R1004.1; also elsewhere on the board
/CB Mosfets/CELL1: R1001.1, R1002.1; also elsewhere on the board
/CB Mosfets/VC0: R1003.2, R1004.2; also elsewhere on the board
unnamed: D1001.1 (K), Q1001.1 (G), R1003.1
unnamed: Q1001.3 (D), R1001.2, R1002.2

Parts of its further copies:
D1101, D1201, D1301, D1401, D1501, D1601, D1701, D1801, D1901: BZT52C5V6S; D_SOD-323; LCSC C19077441
Q1101, Q1201, Q1301, Q1401, Q1501, Q1601, Q1701, Q1801, Q1901: CJ3134K; SOT-723; LCSC C460977
R1101, R1102, R1201, R1202, R1301, R1302, R1401, R1402, R1501, R1502, R1601, R1602, R1701, R1702, R1801, R1802, R1901, R1902: 100; R_1206_3216Metric; LCSC C17901
R1103, R1203, R1303, R1403, R1503, R1603, R1703, R1803, R1903: 10k; R_0603_1608Metric; LCSC C25804
R1104, R1204, R1304, R1404, R1504, R1604, R1704, R1804, R1904: 100; R_0603_1608Metric; LCSC C22775

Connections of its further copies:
/CB Mosfets/CELL1: D1101.2 (A), Q1101.2 (S), R1104.1; also elsewhere on the board
/CB Mosfets/CELL2: D1201.2 (A), Q1201.2 (S), R1101.1, R1102.1, R1204.1; also elsewhere on the board
/CB Mosfets/CELL3: D1301.2 (A), Q1301.2 (S), R1201.1, R1202.1, R1304.1; also elsewhere on the board
/CB Mosfets/CELL4: D1401.2 (A), Q1401.2 (S), R1301.1, R1302.1, R1404.1; also elsewhere on the board
/CB Mosfets/CELL5: D1501.2 (A), Q1501.2 (S), R1401.1, R1402.1, R1504.1; also elsewhere on the board
/CB Mosfets/CELL6: D1601.2 (A), Q1601.2 (S), R1501.1, R1502.1, R1604.1; also elsewhere on the board
/CB Mosfets/CELL7: D1701.2 (A), Q1701.2 (S), R1601.1, R1602.1, R1704.1; also elsewhere on the board
/CB Mosfets/CELL8: D1801.2 (A), Q1801.2 (S), R1701.1, R1702.1, R1804.1; also elsewhere on the board
/CB Mosfets/CELL9: D1901.2 (A), Q1901.2 (S), R1801.1, R1802.1, R1904.1; also elsewhere on the board
/CB Mosfets/CELL10: R1901.1, R1902.1; also elsewhere on the board
/CB Mosfets/VC1: R1103.2, R1104.2; also elsewhere on the board
/CB Mosfets/VC2: R1203.2, R1204.2; also elsewhere on the board
/CB Mosfets/VC3: R1303.2, R1304.2; also elsewhere on the board
/CB Mosfets/VC4: R1403.2, R1404.2; also elsewhere on the board
/CB Mosfets/VC5: R1503.2, R1504.2; also elsewhere on the board
/CB Mosfets/VC6: R1603.2, R1604.2; also elsewhere on the board
/CB Mosfets/VC7: R1703.2, R1704.2; also elsewhere on the board
/CB Mosfets/VC8: R1803.2, R1804.2; also elsewhere on the board
/CB Mosfets/VC9: R1903.2, R1904.2; also elsewhere on the board
unnamed: D1101.1 (K), Q1101.1 (G), R1103.1
unnamed: D1201.1 (K), Q1201.1 (G), R1203.1
unnamed: D1301.1 (K), Q1301.1 (G), R1303.1
unnamed: D1401.1 (K), Q1401.1 (G), R1403.1
unnamed: D1501.1 (K), Q1501.1 (G), R1503.1
unnamed: D1601.1 (K), Q1601.1 (G), R1603.1
unnamed: D1701.1 (K), Q1701.1 (G), R1703.1
unnamed: D1801.1 (K), Q1801.1 (G), R1803.1
unnamed: D1901.1 (K), Q1901.1 (G), R1903.1
unnamed: Q1101.3 (D), R1101.2, R1102.2
unnamed: Q1201.3 (D), R1201.2, R1202.2
unnamed: Q1301.3 (D), R1301.2, R1302.2
unnamed: Q1401.3 (D), R1401.2, R1402.2
unnamed: Q1501.3 (D), R1501.2, R1502.2
unnamed: Q1601.3 (D), R1601.2, R1602.2
unnamed: Q1701.3 (D), R1701.2, R1702.2
unnamed: Q1801.3 (D), R1801.2, R1802.2
unnamed: Q1901.3 (D), R1901.2, R1902.2

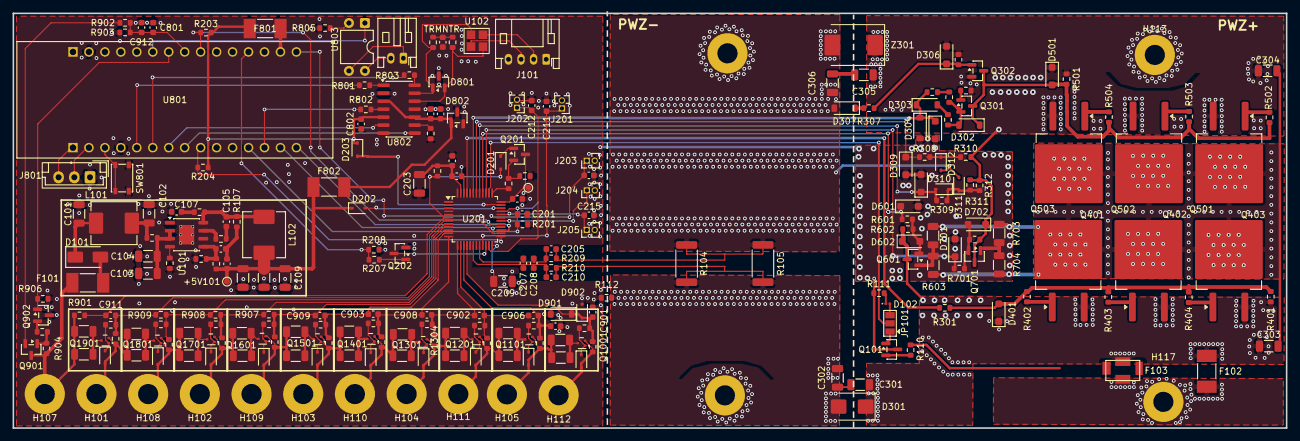
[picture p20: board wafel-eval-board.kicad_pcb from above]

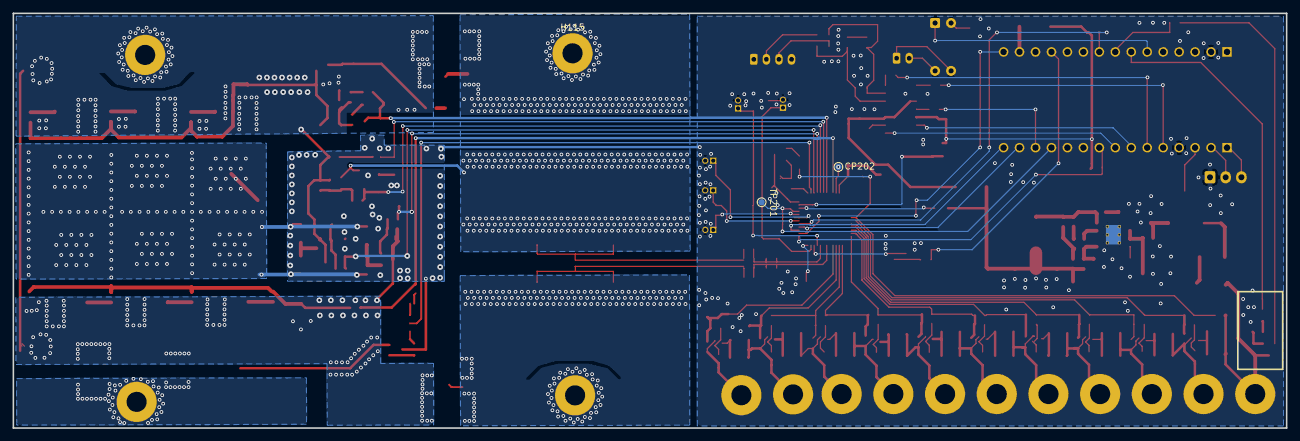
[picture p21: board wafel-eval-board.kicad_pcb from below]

Board: 2 copper layers, 202.6 x 66.0 mm, 256 parts (3 on the bottom side), 150 nets.

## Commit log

2026-03-20 Initial release v0.0.1
    [frontend.kicad_sch, wafel-eval-board.kicad_pcb, wafel-eval-board.kicad_sch]
2026-04-03 add sync folder
    [Mosfet_Cascade.kicad_sch, frontend.kicad_sch, hs-mosfet.kicad_sch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]
2026-04-06 Restore robust hardware project state and clean up test files
    [MCU.kicad_sch, Mosfet_Cascade.kicad_sch, NUCLEO-L432KC.step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]
2026-04-07 add fuses
    [frontend.kicad_sch, wafel-eval-board.kicad_sch]
2026-04-07 improve fuse connectios
    [wafel-eval-board.kicad_sch]
2026-04-09 remove jetbrains mcps, add uv in home and update flake
    [MCU.kicad_sch, Mosfet_Cascade.kicad_sch, Pre_Mosfet.kicad_sch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]
2026-04-09 remove EN
    [hs-mosfet.kicad_sch, wafel-eval-board.kicad_sch]
2026-04-09 change props
    [frontend.kicad_sch, hs-mosfet.kicad_sch, wafel-eval-board.kicad_sch]
2026-04-09 change add thermoprotection
    [frontend.kicad_sch]
2026-04-09 change change n transistor symbol
    [frontend.kicad_sch]
2026-04-09 hide symbols
    [frontend.kicad_sch, wafel-eval-board.kicad_sch]
2026-04-09 fix SPI pins
    [frontend.kicad_sch]
2026-04-10 add bat{en adc}
    [MCU.kicad_sch, cb-mosfets.kicad_sch, cb_mosfet.kicad_sch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]
2026-04-10 simplify page
    [cb-mosfets.kicad_sch]
2026-04-10 switch capasitors to 220mf
    [cb-mosfets.kicad_sch]
2026-04-13 improve can
    [MCU.kicad_sch, wafel-eval-board.kicad_sch]
2026-04-14 fix MCU pin mapping and resolve ERC conflicts
    [MCU.kicad_sch, cb-mosfets.kicad_sch, cb_mosfet.kicad_sch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]
2026-04-14 use bus alias
    [MCU.kicad_sch, frontend.kicad_sch, hs-mosfet.kicad_sch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]
2026-04-14 fix ERC warnings and footprint issues
    [MCU.kicad_sch, frontend.kicad_sch, hs-mosfet.kicad_sch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]
2026-04-14 update schematics
    [MCU.kicad_sch, frontend.kicad_sch, hs-mosfet.kicad_sch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]
2026-04-14 fix remaining missing footprints
    [MCU.kicad_sch, frontend.kicad_sch, hs-mosfet.kicad_sch]
2026-04-14 fix footprint strings inside embedded symbol definitions
2026-04-14 remove unconnected wire segment from frontend sheet
    [frontend.kicad_sch]
2026-04-14 first layout
    [cb-mosfets.kicad_sch, cb_mosfet.kicad_sch, wafel-eval-board.kicad_pcb]
2026-04-15 placed c mosfet
    [MCU.kicad_sch, Mosfet_Cascade.kicad_sch, Pre_Mosfet.kicad_sch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]
2026-04-17 reduced BOM
    [MCU.kicad_sch, Pre_Mosfet.kicad_sch, cb-mosfets.kicad_sch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]
2026-04-17 increased size two times
    [MCU.kicad_sch, Pre_Mosfet.kicad_sch, cb-mosfets.kicad_sch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]
2026-04-17 ADD ZONES
    [wafel-eval-board.kicad_pcb]
2026-04-17 Actualize resistors size
    [Pre_Mosfet.kicad_sch, cb_mosfet.kicad_sch, hs-mosfet.kicad_sch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]
2026-04-18 some chnages
    [cb-mosfets.kicad_sch, cb_mosfet.kicad_sch, frontend.kicad_sch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]
2026-04-18 added qulon zone
    [wafel-eval-board.kicad_pcb]
2026-04-19 Update C301-C306 to 1206 100V capacitors
    [Pre_Mosfet.kicad_sch, cb-mosfets.kicad_sch, cb_mosfet.kicad_sch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]
2026-04-19 Replace gate resistors with ferrite beads (600R @ 100MHz)
    [Mosfet_Cascade.kicad_sch, Pre_Mosfet.kicad_sch]
2026-04-19 Docs: Update MOSFET protection with Ferrite Beads calculation
2026-04-19 Replace pre-charge/discharge MOSFETs with smaller 100V SOT-23 PJM10H01PSA
    [Pre_Mosfet.kicad_sch]
2026-04-19 Sync PCB layout with updated schematic footprints (Q601/Q701 to SOT-23, C301-C306 to 1206)
    [hs-mosfet.kicad_sch, wafel-eval-board.kicad_pcb, wafel-eval-board.kicad_sch]
2026-04-19 Shrink load dump Schottky diodes to SOD-323 (BAT46WS)
    [hs-mosfet.kicad_sch, wafel-eval-board.kicad_pcb]
2026-04-19 Manually replace gate resistors with ferrite bead symbols in schematics
    [Mosfet_Cascade.kicad_sch, Pre_Mosfet.kicad_sch, hs-mosfet.kicad_sch]
2026-04-19 Sync PCB layout with updated gate ferrite bead symbols
    [wafel-eval-board.kicad_pcb]
2026-04-20 Replace huge SolderWire footprint with standard 2.54mm PinHeader
    [frontend.kicad_sch]
2026-04-20 Replace huge SS110 SMA diode (D201) with smaller B110WS in SOD-323
    [frontend.kicad_sch]
2026-04-20 Replace CAN TVS D802 (NUP2105L) with PESD1CAN
    [MCU.kicad_sch]
2026-04-20 Sync PCB layout with updated 2.54mm PinHeader footprints
    [frontend.kicad_sch, wafel-eval-board.kicad_pcb]
2026-04-21 29 drc errors
    [wafel-eval-board.kicad_pcb]
2026-04-21 move controll signals to back
    [MCU.kicad_sch, wafel-eval-board.kicad_pcb]
2026-04-22 done 0001
    [wafel-eval-board.kicad_pcb]
2026-04-22 no 199 warns
    [wafel-eval-board.kicad_pcb]
2026-04-22 no 88 warns
    [wafel-eval-board.kicad_pcb]
2026-04-22 no 122 warns
    [wafel-eval-board.kicad_pcb]
2026-04-22 no 70 warns
    [wafel-eval-board.kicad_pcb]
2026-04-22 no 79 warns
    [wafel-eval-board.kicad_pcb]
2026-04-22 add thermal vias
    [wafel-eval-board.kicad_pcb]
2026-04-22 kelvin connect
    [wafel-eval-board.kicad_pcb]
2026-04-23 fix tracks of correct resistors
2026-05-01 small improvements
    [frontend.kicad_sch, wafel-eval-board.kicad_sch]
